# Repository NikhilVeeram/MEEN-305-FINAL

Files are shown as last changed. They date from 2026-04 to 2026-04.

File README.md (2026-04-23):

# MEEN 305 Final Project

This repo is organized around the active continuous beam-design workflow for the
MEEN 305 beam project.

## Current Setup

- Project-correct geometry is a `9.0 in` total beam with supports at `x = 0.5 in`
  and `x = 8.5 in`.
- The support span remains `8.0 in`.
- Load locations are still measured from support A in the project equations, but
  the solver and optimizer now track the full `0 to 9 in` beam coordinate.

## DIR

```text
MEEN-305-FINAL/
|-- README.md
|-- requirements.txt
|-- scripts/
|   |-- beam_solver.py
|   |-- optimize_beam.py
|   |-- beam_3d_models.py
|   `-- diagram_assets.py
|-- docs/
|   |-- notes/
|   |   |-- active_continuous_design_summary.md
|   |   |-- current_design_selection.md
|   |   |-- analysis_accountability_map.md
|   |   `-- beam_length_support_correction_audit.md
|   |-- references/
|   |   `-- project_reference_materials/
|   `-- reports/
|       `-- final_project_report.tex
|-- designs/
|   |-- active_runs/
|   |   |-- continuous_uniform_load_case_1/
|   |   |-- continuous_uniform_load_case_2/
|   |   |-- continuous_uniform_both_load_cases/
|   |   `-- continuous_uniform_both_load_cases_9in_corrected/
|   |-- model_exports/
|   `-- packages/
|-- Instructions_References/
`-- archive/
    `-- deprecated_assets/
```

## Folder Definitions

- [scripts](/c:/Users/nikhil/Documents/GitHub/MEEN-305-FINAL/scripts): source-of-truth analysis, optimization, export, and diagram code.
- [docs/notes](/c:/Users/nikhil/Documents/GitHub/MEEN-305-FINAL/docs/notes): working notes, design decisions, and correction audits.
- [docs/references/project_reference_materials](/c:/Users/nikhil/Documents/GitHub/MEEN-305-FINAL/docs/references/project_reference_materials): project handout, equations sheets, and supporting reference material.
- [docs/reports](/c:/Users/nikhil/Documents/GitHub/MEEN-305-FINAL/docs/reports): report deliverables, including the large final report source.
- [designs/active_runs](/c:/Users/nikhil/Documents/GitHub/MEEN-305-FINAL/designs/active_runs): generated optimization runs and their reports/plots.
- [designs/model_exports](/c:/Users/nikhil/Documents/GitHub/MEEN-305-FINAL/designs/model_exports): exported mesh files, previews, and manifest readmes.
- [designs/packages](/c:/Users/nikhil/Documents/GitHub/MEEN-305-FINAL/designs/packages): presentation-ready per-design bundles.
- [Instructions_References](/c:/Users/nikhil/Documents/GitHub/MEEN-305-FINAL/Instructions_References): prompt fragments and correction instructions collected during the project.
- [archive/deprecated_assets](/c:/Users/nikhil/Documents/GitHub/MEEN-305-FINAL/archive/deprecated_assets): superseded runs, legacy exports, and older exploratory work retained for reference.

## Active Reference Files

- [active_continuous_design_summary.md](/c:/Users/nikhil/Documents/GitHub/MEEN-305-FINAL/docs/notes/active_continuous_design_summary.md)
- [current_design_selection.md](/c:/Users/nikhil/Documents/GitHub/MEEN-305-FINAL/docs/notes/current_design_selection.md)
- [beam_length_support_correction_audit.md](/c:/Users/nikhil/Documents/GitHub/MEEN-305-FINAL/docs/notes/beam_length_support_correction_audit.md)

## Common Commands

Run the solver:

```powershell
python scripts/beam_solver.py --total-length-in 9.0 --span-in 8.0 --support-a-x-in 0.5 --support-b-x-in 8.5
```

Run the corrected optimizer into a named folder:

```powershell
python scripts/optimize_beam.py --output-dir designs/active_runs/continuous_uniform_both_load_cases_9in_corrected --total-length-in 9.0 --span-in 8.0 --support-a-x-in 0.5 --support-b-x-in 8.5
```

Generate 3D exports:

```powershell
python scripts/beam_3d_models.py --write-dxf
```

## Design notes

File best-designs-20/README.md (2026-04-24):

# Best Designs 20

Top 20 feasible corrected 9 in beam candidates for report review.

Ranking formula: `weight_lbf`, with tie-breakers `max_deflection_in`, `abs(min_fos - 1.5)`, then `fos_3to7_std`.

Weight is the primary ranking target. Load Case 2 flatness over x=3..7 is retained as a reported metric and late tie-breaker.

## Folders

- `ranked-designs/`: one folder per top-20 candidate, prefixed with report rank.
- `3d-models/`: generated STL/OBJ/DXF/preview assets after running `scripts/beam_3d_models.py`.
- `report-packages/`: packaged copies of each ranked candidate after 3D generation.
- `ranking_summary.csv`: compact table for report selection.

Archived non-top-20 ranked candidates: `archive/ranked-design-candidates/ranked_candidates_after_top20.csv`.

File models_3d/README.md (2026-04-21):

# 3D Beam Models

This folder contains generated 3D models and preview renders for the beam designs found in the repo.

## Generated designs

### sample_geometry

- STL: [sample_geometry.stl](sample_geometry.stl)
- OBJ: [sample_geometry.obj](sample_geometry.obj)
- Preview: [sample_geometry_preview.png](sample_geometry_preview.png)

### optimization_outputs

- STL: [optimization_outputs.stl](optimization_outputs.stl)
- OBJ: [optimization_outputs.obj](optimization_outputs.obj)
- Preview: [optimization_outputs_preview.png](optimization_outputs_preview.png)

### optimization_targeted

- STL: [optimization_targeted.stl](optimization_targeted.stl)
- OBJ: [optimization_targeted.obj](optimization_targeted.obj)
- Preview: [optimization_targeted_preview.png](optimization_targeted_preview.png)

### optimization_opening_smoke

- STL: [optimization_opening_smoke.stl](optimization_opening_smoke.stl)
- OBJ: [optimization_opening_smoke.obj](optimization_opening_smoke.obj)
- Preview: [optimization_opening_smoke_preview.png](optimization_opening_smoke_preview.png)

### optimization_connected_2026

- STL: [optimization_connected_2026.stl](optimization_connected_2026.stl)
- OBJ: [optimization_connected_2026.obj](optimization_connected_2026.obj)
- Preview: [optimization_connected_2026_preview.png](optimization_connected_2026_preview.png)

### optimization_connected_7777

- STL: [optimization_connected_7777.stl](optimization_connected_7777.stl)
- OBJ: [optimization_connected_7777.obj](optimization_connected_7777.obj)
- Preview: [optimization_connected_7777_preview.png](optimization_connected_7777_preview.png)

### optimization_connected_4242

- STL: [optimization_connected_4242.stl](optimization_connected_4242.stl)
- OBJ: [optimization_connected_4242.obj](optimization_connected_4242.obj)
- Preview: [optimization_connected_4242_preview.png](optimization_connected_4242_preview.png)

### optimization_connected_v2_9191

- STL: [optimization_connected_v2_9191.stl](optimization_connected_v2_9191.stl)
- OBJ: [optimization_connected_v2_9191.obj](optimization_connected_v2_9191.obj)
- Preview: [optimization_connected_v2_9191_preview.png](optimization_connected_v2_9191_preview.png)

### optimization_connected_v2_3030

- STL: [optimization_connected_v2_3030.stl](optimization_connected_v2_3030.stl)
- OBJ: [optimization_connected_v2_3030.obj](optimization_connected_v2_3030.obj)
- Preview: [optimization_connected_v2_3030_preview.png](optimization_connected_v2_3030_preview.png)

### optimization_connected_v2_6060

- STL: [optimization_connected_v2_6060.stl](optimization_connected_v2_6060.stl)
- OBJ: [optimization_connected_v2_6060.obj](optimization_connected_v2_6060.obj)
- Preview: [optimization_connected_v2_6060_preview.png](optimization_connected_v2_6060_preview.png)

### optimization_connected_v3

- STL: [optimization_connected_v3.stl](optimization_connected_v3.stl)
- OBJ: [optimization_connected_v3.obj](optimization_connected_v3.obj)
- Preview: [optimization_connected_v3_preview.png](optimization_connected_v3_preview.png)

### optimization_final

- STL: [optimization_final.stl](optimization_final.stl)
- OBJ: [optimization_final.obj](optimization_final.obj)
- Preview: [optimization_final_preview.png](optimization_final_preview.png)

## How to view them

- Double-click an `.obj` or `.stl` file in a local 3D viewer if you have one installed.
- Use the `.png` previews for quick comparison inside the repo.
- Re-run `python beam_3d_models.py` after optimization updates to refresh the models.

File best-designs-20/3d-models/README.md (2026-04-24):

# 3D Beam Models

This folder contains generated 3D models and preview renders for the beam designs found in the repo.

## Generated designs

### 01_overall_rank__continuous_uniform_both_load_cases_9in_corrected__eval_0370__w_0.02815__fos_1.642

- STL: [01_overall_rank__continuous_uniform_both_load_cases_9in_corrected__eval_0370__w_0.02815__fos_1.642.stl](01_overall_rank__continuous_uniform_both_load_cases_9in_corrected__eval_0370__w_0.02815__fos_1.642.stl)
- OBJ: [01_overall_rank__continuous_uniform_both_load_cases_9in_corrected__eval_0370__w_0.02815__fos_1.642.obj](01_overall_rank__continuous_uniform_both_load_cases_9in_corrected__eval_0370__w_0.02815__fos_1.642.obj)
- Preview: [01_overall_rank__continuous_uniform_both_load_cases_9in_corrected__eval_0370__w_0.02815__fos_1.642_preview.png](01_overall_rank__continuous_uniform_both_load_cases_9in_corrected__eval_0370__w_0.02815__fos_1.642_preview.png)
- DXF sketch: [01_overall_rank__continuous_uniform_both_load_cases_9in_corrected__eval_0370__w_0.02815__fos_1.642.dxf](01_overall_rank__continuous_uniform_both_load_cases_9in_corrected__eval_0370__w_0.02815__fos_1.642.dxf)

### 02_overall_rank__ultra_light_full_strength_seed2433__eval_1528__w_0.02894__fos_1.732

- STL: [02_overall_rank__ultra_light_full_strength_seed2433__eval_1528__w_0.02894__fos_1.732.stl](02_overall_rank__ultra_light_full_strength_seed2433__eval_1528__w_0.02894__fos_1.732.stl)
- OBJ: [02_overall_rank__ultra_light_full_strength_seed2433__eval_1528__w_0.02894__fos_1.732.obj](02_overall_rank__ultra_light_full_strength_seed2433__eval_1528__w_0.02894__fos_1.732.obj)
- Preview: [02_overall_rank__ultra_light_full_strength_seed2433__eval_1528__w_0.02894__fos_1.732_preview.png](02_overall_rank__ultra_light_full_strength_seed2433__eval_1528__w_0.02894__fos_1.732_preview.png)
- DXF sketch: [02_overall_rank__ultra_light_full_strength_seed2433__eval_1528__w_0.02894__fos_1.732.dxf](02_overall_rank__ultra_light_full_strength_seed2433__eval_1528__w_0.02894__fos_1.732.dxf)

### 03_overall_rank__ultra_light_run4_asymmetric_seed2427__eval_1102__w_0.02958__fos_2.116

- STL: [03_overall_rank__ultra_light_run4_asymmetric_seed2427__eval_1102__w_0.02958__fos_2.116.stl](03_overall_rank__ultra_light_run4_asymmetric_seed2427__eval_1102__w_0.02958__fos_2.116.stl)
- OBJ: [03_overall_rank__ultra_light_run4_asymmetric_seed2427__eval_1102__w_0.02958__fos_2.116.obj](03_overall_rank__ultra_light_run4_asymmetric_seed2427__eval_1102__w_0.02958__fos_2.116.obj)
- Preview: [03_overall_rank__ultra_light_run4_asymmetric_seed2427__eval_1102__w_0.02958__fos_2.116_preview.png](03_overall_rank__ultra_light_run4_asymmetric_seed2427__eval_1102__w_0.02958__fos_2.116_preview.png)
- DXF sketch: [03_overall_rank__ultra_light_run4_asymmetric_seed2427__eval_1102__w_0.02958__fos_2.116.dxf](03_overall_rank__ultra_light_run4_asymmetric_seed2427__eval_1102__w_0.02958__fos_2.116.dxf)

### 04_overall_rank__ultra_light_full_strength_seed2433__eval_2458__w_0.02971__fos_1.562

- STL: [04_overall_rank__ultra_light_full_strength_seed2433__eval_2458__w_0.02971__fos_1.562.stl](04_overall_rank__ultra_light_full_strength_seed2433__eval_2458__w_0.02971__fos_1.562.stl)
- OBJ: [04_overall_rank__ultra_light_full_strength_seed2433__eval_2458__w_0.02971__fos_1.562.obj](04_overall_rank__ultra_light_full_strength_seed2433__eval_2458__w_0.02971__fos_1.562.obj)
- Preview: [04_overall_rank__ultra_light_full_strength_seed2433__eval_2458__w_0.02971__fos_1.562_preview.png](04_overall_rank__ultra_light_full_strength_seed2433__eval_2458__w_0.02971__fos_1.562_preview.png)
- DXF sketch: [04_overall_rank__ultra_light_full_strength_seed2433__eval_2458__w_0.02971__fos_1.562.dxf](04_overall_rank__ultra_light_full_strength_seed2433__eval_2458__w_0.02971__fos_1.562.dxf)

### 05_overall_rank__ultra_light_full_infill_seed2432__eval_2924__w_0.03074__fos_1.789

- STL: [05_overall_rank__ultra_light_full_infill_seed2432__eval_2924__w_0.03074__fos_1.789.stl](05_overall_rank__ultra_light_full_infill_seed2432__eval_2924__w_0.03074__fos_1.789.stl)
- OBJ: [05_overall_rank__ultra_light_full_infill_seed2432__eval_2924__w_0.03074__fos_1.789.obj](05_overall_rank__ultra_light_full_infill_seed2432__eval_2924__w_0.03074__fos_1.789.obj)
- Preview: [05_overall_rank__ultra_light_full_infill_seed2432__eval_2924__w_0.03074__fos_1.789_preview.png](05_overall_rank__ultra_light_full_infill_seed2432__eval_2924__w_0.03074__fos_1.789_preview.png)
- DXF sketch: [05_overall_rank__ultra_light_full_infill_seed2432__eval_2924__w_0.03074__fos_1.789.dxf](05_overall_rank__ultra_light_full_infill_seed2432__eval_2924__w_0.03074__fos_1.789.dxf)

### 06_overall_rank__ultra_light_full_strength_seed2433__eval_1532__w_0.03127__fos_1.712

- STL: [06_overall_rank__ultra_light_full_strength_seed2433__eval_1532__w_0.03127__fos_1.712.stl](06_overall_rank__ultra_light_full_strength_seed2433__eval_1532__w_0.03127__fos_1.712.stl)
- OBJ: [06_overall_rank__ultra_light_full_strength_seed2433__eval_1532__w_0.03127__fos_1.712.obj](06_overall_rank__ultra_light_full_strength_seed2433__eval_1532__w_0.03127__fos_1.712.obj)
- Preview: [06_overall_rank__ultra_light_full_strength_seed2433__eval_1532__w_0.03127__fos_1.712_preview.png](06_overall_rank__ultra_light_full_strength_seed2433__eval_1532__w_0.03127__fos_1.712_preview.png)
- DXF sketch: [06_overall_rank__ultra_light_full_strength_seed2433__eval_1532__w_0.03127__fos_1.712.dxf](06_overall_rank__ultra_light_full_strength_seed2433__eval_1532__w_0.03127__fos_1.712.dxf)

### 07_overall_rank__ultra_light_full_infill_seed2432__eval_2497__w_0.03158__fos_1.751

- STL: [07_overall_rank__ultra_light_full_infill_seed2432__eval_2497__w_0.03158__fos_1.751.stl](07_overall_rank__ultra_light_full_infill_seed2432__eval_2497__w_0.03158__fos_1.751.stl)
- OBJ: [07_overall_rank__ultra_light_full_infill_seed2432__eval_2497__w_0.03158__fos_1.751.obj](07_overall_rank__ultra_light_full_infill_seed2432__eval_2497__w_0.03158__fos_1.751.obj)
- Preview: [07_overall_rank__ultra_light_full_infill_seed2432__eval_2497__w_0.03158__fos_1.751_preview.png](07_overall_rank__ultra_light_full_infill_seed2432__eval_2497__w_0.03158__fos_1.751_preview.png)
- DXF sketch: [07_overall_rank__ultra_light_full_infill_seed2432__eval_2497__w_0.03158__fos_1.751.dxf](07_overall_rank__ultra_light_full_infill_seed2432__eval_2497__w_0.03158__fos_1.751.dxf)

### 08_overall_rank__ultra_light_full_infill_seed2432__eval_2852__w_0.03254__fos_1.713

- STL: [08_overall_rank__ultra_light_full_infill_seed2432__eval_2852__w_0.03254__fos_1.713.stl](08_overall_rank__ultra_light_full_infill_seed2432__eval_2852__w_0.03254__fos_1.713.stl)
- OBJ: [08_overall_rank__ultra_light_full_infill_seed2432__eval_2852__w_0.03254__fos_1.713.obj](08_overall_rank__ultra_light_full_infill_seed2432__eval_2852__w_0.03254__fos_1.713.obj)
- Preview: [08_overall_rank__ultra_light_full_infill_seed2432__eval_2852__w_0.03254__fos_1.713_preview.png](08_overall_rank__ultra_light_full_infill_seed2432__eval_2852__w_0.03254__fos_1.713_preview.png)
- DXF sketch: [08_overall_rank__ultra_light_full_infill_seed2432__eval_2852__w_0.03254__fos_1.713.dxf](08_overall_rank__ultra_light_full_infill_seed2432__eval_2852__w_0.03254__fos_1.713.dxf)

### 09_overall_rank__ultra_light_full_infill_seed2432__eval_2251__w_0.03329__fos_1.595

- STL: [09_overall_rank__ultra_light_full_infill_seed2432__eval_2251__w_0.03329__fos_1.595.stl](09_overall_rank__ultra_light_full_infill_seed2432__eval_2251__w_0.03329__fos_1.595.stl)
- OBJ: [09_overall_rank__ultra_light_full_infill_seed2432__eval_2251__w_0.03329__fos_1.595.obj](09_overall_rank__ultra_light_full_infill_seed2432__eval_2251__w_0.03329__fos_1.595.obj)
- Preview: [09_overall_rank__ultra_light_full_infill_seed2432__eval_2251__w_0.03329__fos_1.595_preview.png](09_overall_rank__ultra_light_full_infill_seed2432__eval_2251__w_0.03329__fos_1.595_preview.png)
- DXF sketch: [09_overall_rank__ultra_light_full_infill_seed2432__eval_2251__w_0.03329__fos_1.595.dxf](09_overall_rank__ultra_light_full_infill_seed2432__eval_2251__w_0.03329__fos_1.595.dxf)

### 10_overall_rank__ultra_light_full_infill_seed2432__eval_2514__w_0.03483__fos_1.572

- STL: [10_overall_rank__ultra_light_full_infill_seed2432__eval_2514__w_0.03483__fos_1.572.stl](10_overall_rank__ultra_light_full_infill_seed2432__eval_2514__w_0.03483__fos_1.572.stl)
- OBJ: [10_overall_rank__ultra_light_full_infill_seed2432__eval_2514__w_0.03483__fos_1.572.obj](10_overall_rank__ultra_light_full_infill_seed2432__eval_2514__w_0.03483__fos_1.572.obj)
- Preview: [10_overall_rank__ultra_light_full_infill_seed2432__eval_2514__w_0.03483__fos_1.572_preview.png](10_overall_rank__ultra_light_full_infill_seed2432__eval_2514__w_0.03483__fos_1.572_preview.png)
- DXF sketch: [10_overall_rank__ultra_light_full_infill_seed2432__eval_2514__w_0.03483__fos_1.572.dxf](10_overall_rank__ultra_light_full_infill_seed2432__eval_2514__w_0.03483__fos_1.572.dxf)

### 11_overall_rank__continuous_uniform_both_load_cases_9in_corrected__eval_0572__w_0.03504__fos_1.877

- STL: [11_overall_rank__continuous_uniform_both_load_cases_9in_corrected__eval_0572__w_0.03504__fos_1.877.stl](11_overall_rank__continuous_uniform_both_load_cases_9in_corrected__eval_0572__w_0.03504__fos_1.877.stl)
- OBJ: [11_overall_rank__continuous_uniform_both_load_cases_9in_corrected__eval_0572__w_0.03504__fos_1.877.obj](11_overall_rank__continuous_uniform_both_load_cases_9in_corrected__eval_0572__w_0.03504__fos_1.877.obj)
- Preview: [11_overall_rank__continuous_uniform_both_load_cases_9in_corrected__eval_0572__w_0.03504__fos_1.877_preview.png](11_overall_rank__continuous_uniform_both_load_cases_9in_corrected__eval_0572__w_0.03504__fos_1.877_preview.png)
- DXF sketch: [11_overall_rank__continuous_uniform_both_load_cases_9in_corrected__eval_0572__w_0.03504__fos_1.877.dxf](11_overall_rank__continuous_uniform_both_load_cases_9in_corrected__eval_0572__w_0.03504__fos_1.877.dxf)

### 12_overall_rank__continuous_uniform_both_load_cases_9in_corrected__eval_0680__w_0.03546__fos_2.902

- STL: [12_overall_rank__continuous_uniform_both_load_cases_9in_corrected__eval_0680__w_0.03546__fos_2.902.stl](12_overall_rank__continuous_uniform_both_load_cases_9in_corrected__eval_0680__w_0.03546__fos_2.902.stl)
- OBJ: [12_overall_rank__continuous_uniform_both_load_cases_9in_corrected__eval_0680__w_0.03546__fos_2.902.obj](12_overall_rank__continuous_uniform_both_load_cases_9in_corrected__eval_0680__w_0.03546__fos_2.902.obj)
- Preview: [12_overall_rank__continuous_uniform_both_load_cases_9in_corrected__eval_0680__w_0.03546__fos_2.902_preview.png](12_overall_rank__continuous_uniform_both_load_cases_9in_corrected__eval_0680__w_0.03546__fos_2.902_preview.png)
- DXF sketch: [12_overall_rank__continuous_uniform_both_load_cases_9in_corrected__eval_0680__w_0.03546__fos_2.902.dxf](12_overall_rank__continuous_uniform_both_load_cases_9in_corrected__eval_0680__w_0.03546__fos_2.902.dxf)

### 13_overall_rank__ultra_light_runa_seed2430__eval_2464__w_0.03652__fos_2.154

- STL: [13_overall_rank__ultra_light_runa_seed2430__eval_2464__w_0.03652__fos_2.154.stl](13_overall_rank__ultra_light_runa_seed2430__eval_2464__w_0.03652__fos_2.154.stl)
- OBJ: [13_overall_rank__ultra_light_runa_seed2430__eval_2464__w_0.03652__fos_2.154.obj](13_overall_rank__ultra_light_runa_seed2430__eval_2464__w_0.03652__fos_2.154.obj)
- Preview: [13_overall_rank__ultra_light_runa_seed2430__eval_2464__w_0.03652__fos_2.154_preview.png](13_overall_rank__ultra_light_runa_seed2430__eval_2464__w_0.03652__fos_2.154_preview.png)
- DXF sketch: [13_overall_rank__ultra_light_runa_seed2430__eval_2464__w_0.03652__fos_2.154.dxf](13_overall_rank__ultra_light_runa_seed2430__eval_2464__w_0.03652__fos_2.154.dxf)

### 14_overall_rank__continuous_uniform_both_load_cases_9in_corrected__eval_0402__w_0.03782__fos_2.022

- STL: [14_overall_rank__continuous_uniform_both_load_cases_9in_corrected__eval_0402__w_0.03782__fos_2.022.stl](14_overall_rank__continuous_uniform_both_load_cases_9in_corrected__eval_0402__w_0.03782__fos_2.022.stl)
- OBJ: [14_overall_rank__continuous_uniform_both_load_cases_9in_corrected__eval_0402__w_0.03782__fos_2.022.obj](14_overall_rank__continuous_uniform_both_load_cases_9in_corrected__eval_0402__w_0.03782__fos_2.022.obj)
- Preview: [14_overall_rank__continuous_uniform_both_load_cases_9in_corrected__eval_0402__w_0.03782__fos_2.022_preview.png](14_overall_rank__continuous_uniform_both_load_cases_9in_corrected__eval_0402__w_0.03782__fos_2.022_preview.png)
- DXF sketch: [14_overall_rank__continuous_uniform_both_load_cases_9in_corrected__eval_0402__w_0.03782__fos_2.022.dxf](14_overall_rank__continuous_uniform_both_load_cases_9in_corrected__eval_0402__w_0.03782__fos_2.022.dxf)

### 15_overall_rank__continuous_uniform_both_load_cases_9in_corrected__eval_0364__w_0.03983__fos_1.695

- STL: [15_overall_rank__continuous_uniform_both_load_cases_9in_corrected__eval_0364__w_0.03983__fos_1.695.stl](15_overall_rank__continuous_uniform_both_load_cases_9in_corrected__eval_0364__w_0.03983__fos_1.695.stl)
- OBJ: [15_overall_rank__continuous_uniform_both_load_cases_9in_corrected__eval_0364__w_0.03983__fos_1.695.obj](15_overall_rank__continuous_uniform_both_load_cases_9in_corrected__eval_0364__w_0.03983__fos_1.695.obj)
- Preview: [15_overall_rank__continuous_uniform_both_load_cases_9in_corrected__eval_0364__w_0.03983__fos_1.695_preview.png](15_overall_rank__continuous_uniform_both_load_cases_9in_corrected__eval_0364__w_0.03983__fos_1.695_preview.png)
- DXF sketch: [15_overall_rank__continuous_uniform_both_load_cases_9in_corrected__eval_0364__w_0.03983__fos_1.695.dxf](15_overall_rank__continuous_uniform_both_load_cases_9in_corrected__eval_0364__w_0.03983__fos_1.695.dxf)

### 16_overall_rank__continuous_uniform_both_load_cases_9in_corrected__eval_0219__w_0.03983__fos_1.761

- STL: [16_overall_rank__continuous_uniform_both_load_cases_9in_corrected__eval_0219__w_0.03983__fos_1.761.stl](16_overall_rank__continuous_uniform_both_load_cases_9in_corrected__eval_0219__w_0.03983__fos_1.761.stl)
- OBJ: [16_overall_rank__continuous_uniform_both_load_cases_9in_corrected__eval_0219__w_0.03983__fos_1.761.obj](16_overall_rank__continuous_uniform_both_load_cases_9in_corrected__eval_0219__w_0.03983__fos_1.761.obj)
- Preview: [16_overall_rank__continuous_uniform_both_load_cases_9in_corrected__eval_0219__w_0.03983__fos_1.761_preview.png](16_overall_rank__continuous_uniform_both_load_cases_9in_corrected__eval_0219__w_0.03983__fos_1.761_preview.png)
- DXF sketch: [16_overall_rank__continuous_uniform_both_load_cases_9in_corrected__eval_0219__w_0.03983__fos_1.761.dxf](16_overall_rank__continuous_uniform_both_load_cases_9in_corrected__eval_0219__w_0.03983__fos_1.761.dxf)

### 17_overall_rank__print_safe_contiguous_closed_tube_seed2502__eval_1066__w_0.04048__fos_1.674

- STL: [17_overall_rank__print_safe_contiguous_closed_tube_seed2502__eval_1066__w_0.04048__fos_1.674.stl](17_overall_rank__print_safe_contiguous_closed_tube_seed2502__eval_1066__w_0.04048__fos_1.674.stl)
- OBJ: [17_overall_rank__print_safe_contiguous_closed_tube_seed2502__eval_1066__w_0.04048__fos_1.674.obj](17_overall_rank__print_safe_contiguous_closed_tube_seed2502__eval_1066__w_0.04048__fos_1.674.obj)
- Preview: [17_overall_rank__print_safe_contiguous_closed_tube_seed2502__eval_1066__w_0.04048__fos_1.674_preview.png](17_overall_rank__print_safe_contiguous_closed_tube_seed2502__eval_1066__w_0.04048__fos_1.674_preview.png)
- DXF sketch: [17_overall_rank__print_safe_contiguous_closed_tube_seed2502__eval_1066__w_0.04048__fos_1.674.dxf](17_overall_rank__print_safe_contiguous_closed_tube_seed2502__eval_1066__w_0.04048__fos_1.674.dxf)

### 18_overall_rank__continuous_uniform_both_load_cases_9in_corrected__eval_0441__w_0.04079__fos_1.503

- STL: [18_overall_rank__continuous_uniform_both_load_cases_9in_corrected__eval_0441__w_0.04079__fos_1.503.stl](18_overall_rank__continuous_uniform_both_load_cases_9in_corrected__eval_0441__w_0.04079__fos_1.503.stl)
- OBJ: [18_overall_rank__continuous_uniform_both_load_cases_9in_corrected__eval_0441__w_0.04079__fos_1.503.obj](18_overall_rank__continuous_uniform_both_load_cases_9in_corrected__eval_0441__w_0.04079__fos_1.503.obj)
- Preview: [18_overall_rank__continuous_uniform_both_load_cases_9in_corrected__eval_0441__w_0.04079__fos_1.503_preview.png](18_overall_rank__continuous_uniform_both_load_cases_9in_corrected__eval_0441__w_0.04079__fos_1.503_preview.png)
- DXF sketch: [18_overall_rank__continuous_uniform_both_load_cases_9in_corrected__eval_0441__w_0.04079__fos_1.503.dxf](18_overall_rank__continuous_uniform_both_load_cases_9in_corrected__eval_0441__w_0.04079__fos_1.503.dxf)

### 19_overall_rank__ultra_light_full_infill_seed2432__eval_2513__w_0.04121__fos_1.565

- STL: [19_overall_rank__ultra_light_full_infill_seed2432__eval_2513__w_0.04121__fos_1.565.stl](19_overall_rank__ultra_light_full_infill_seed2432__eval_2513__w_0.04121__fos_1.565.stl)
- OBJ: [19_overall_rank__ultra_light_full_infill_seed2432__eval_2513__w_0.04121__fos_1.565.obj](19_overall_rank__ultra_light_full_infill_seed2432__eval_2513__w_0.04121__fos_1.565.obj)
- Preview: [19_overall_rank__ultra_light_full_infill_seed2432__eval_2513__w_0.04121__fos_1.565_preview.png](19_overall_rank__ultra_light_full_infill_seed2432__eval_2513__w_0.04121__fos_1.565_preview.png)
- DXF sketch: [19_overall_rank__ultra_light_full_infill_seed2432__eval_2513__w_0.04121__fos_1.565.dxf](19_overall_rank__ultra_light_full_infill_seed2432__eval_2513__w_0.04121__fos_1.565.dxf)

### 20_overall_rank__ultra_light_run3_lowheight_seed2426__eval_1611__w_0.04175__fos_2.633

- STL: [20_overall_rank__ultra_light_run3_lowheight_seed2426__eval_1611__w_0.04175__fos_2.633.stl](20_overall_rank__ultra_light_run3_lowheight_seed2426__eval_1611__w_0.04175__fos_2.633.stl)
- OBJ: [20_overall_rank__ultra_light_run3_lowheight_seed2426__eval_1611__w_0.04175__fos_2.633.obj](20_overall_rank__ultra_light_run3_lowheight_seed2426__eval_1611__w_0.04175__fos_2.633.obj)
- Preview: [20_overall_rank__ultra_light_run3_lowheight_seed2426__eval_1611__w_0.04175__fos_2.633_preview.png](20_overall_rank__ultra_light_run3_lowheight_seed2426__eval_1611__w_0.04175__fos_2.633_preview.png)
- DXF sketch: [20_overall_rank__ultra_light_run3_lowheight_seed2426__eval_1611__w_0.04175__fos_2.633.dxf](20_overall_rank__ultra_light_run3_lowheight_seed2426__eval_1611__w_0.04175__fos_2.633.dxf)

## How to view them

- Double-click an `.obj` or `.stl` file in a local 3D viewer if you have one installed.
- Use the `.png` previews for quick comparison inside the repo.
- Re-run `python scripts/beam_3d_models.py` after optimization updates to refresh the models.

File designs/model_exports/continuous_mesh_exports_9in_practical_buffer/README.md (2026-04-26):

# 3D Beam Models

This folder contains generated 3D models and preview renders for the beam designs found in the repo.

## Generated designs

### continuous_uniform_both_load_cases_9in_practical_buffer

- STL: [continuous_uniform_both_load_cases_9in_practical_buffer.stl](continuous_uniform_both_load_cases_9in_practical_buffer.stl)
- OBJ: [continuous_uniform_both_load_cases_9in_practical_buffer.obj](continuous_uniform_both_load_cases_9in_practical_buffer.obj)
- Preview: [continuous_uniform_both_load_cases_9in_practical_buffer_preview.png](continuous_uniform_both_load_cases_9in_practical_buffer_preview.png)
- DXF sketch: [continuous_uniform_both_load_cases_9in_practical_buffer.dxf](continuous_uniform_both_load_cases_9in_practical_buffer.dxf)

## How to view them

- Double-click an `.obj` or `.stl` file in a local 3D viewer if you have one installed.
- Use the `.png` previews for quick comparison inside the repo.
- Re-run `python scripts/beam_3d_models.py` after optimization updates to refresh the models.

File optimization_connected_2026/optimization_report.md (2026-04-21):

# Beam Optimization Report

## Search Summary

- Search method: stratified global sampling with elite local refinement
- Total evaluated designs: 1540
- Feasible designs found: 429
- Minimum required factor of safety: 1.500
- Objective shaping: penalize excess FoS margin and underutilized stress envelope so the design approaches the 1.5 target more closely
- Maximum allowed deflection: not enforced in this run
- Random seed: 2026

## Best Design

- Weight: 0.05103 lbf
- Minimum factor of safety: 2.288
- Excess FoS above target: 0.788
- Governing minimum-FoS load case: Load Case 2 at x = 4.000 in
- Maximum deflection: 0.07570 in
- Durability score (0 is best): 0.000000
- Constraint status: feasible

### Geometry Variables

| Variable | Value |
| --- | ---: |
| $L$ [in] | 8.000 |
| $L_{total}$ [in] | 9.000 |
| $b_L$ [in] | 0.400 |
| $b_M$ [in] | 0.400 |
| $b_R$ [in] | 0.759 |
| $h_L$ [in] | 0.978 |
| $h_M$ [in] | 0.533 |
| $h_R$ [in] | 0.889 |
| $t$ [in] | 0.074 |
| $r_L$ [-] | 0.680 |
| $r_M$ [-] | 0.000 |
| $r_R$ [-] | 0.000 |
| $E_{eff}$ [psi] | 297500.0 |
| $\sigma_{allow,eff}$ [psi] | 2380.0 |

### Best-Design Load-Case Metrics

| Load Case | Orientation | Load [lbf] | Location [in] | Min FoS | FoS x [in] | Max Deflection [in] | Max von Mises [psi] |
| --- | --- | ---: | ---: | ---: | ---: | ---: | ---: |
| Load Case 1 | upright | 5.000 | 4.000 | 3.416 | 4.000 | 0.02977 | 696.8 |
| Load Case 2 | side | 8.000 | 5.000 | 2.288 | 4.000 | 0.07570 | 1040.3 |

## Beam Structure and Parameters

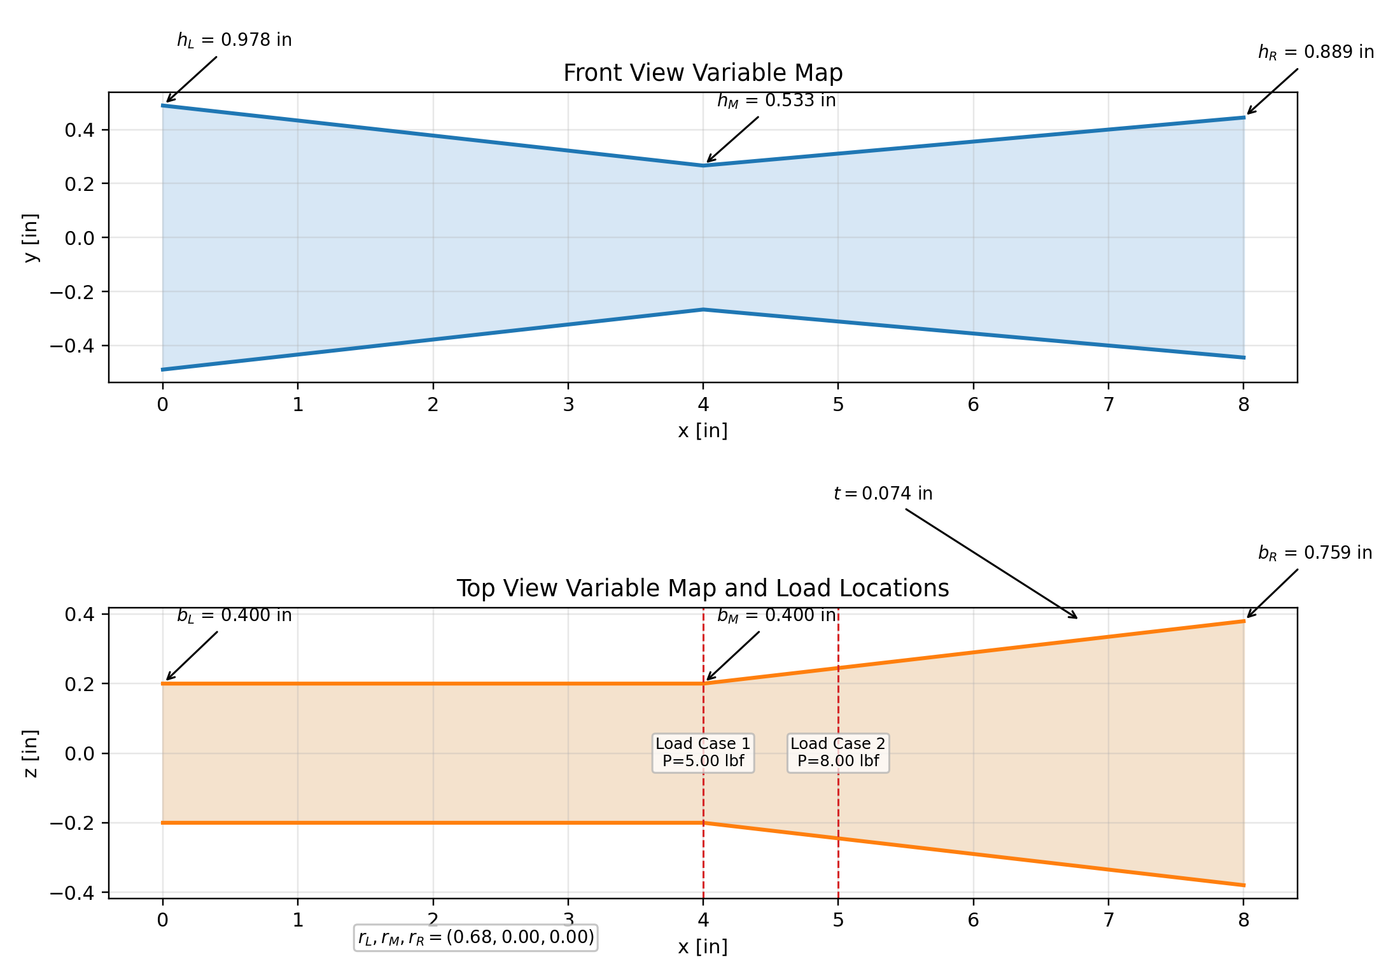
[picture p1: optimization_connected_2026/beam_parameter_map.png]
Beam parameter map


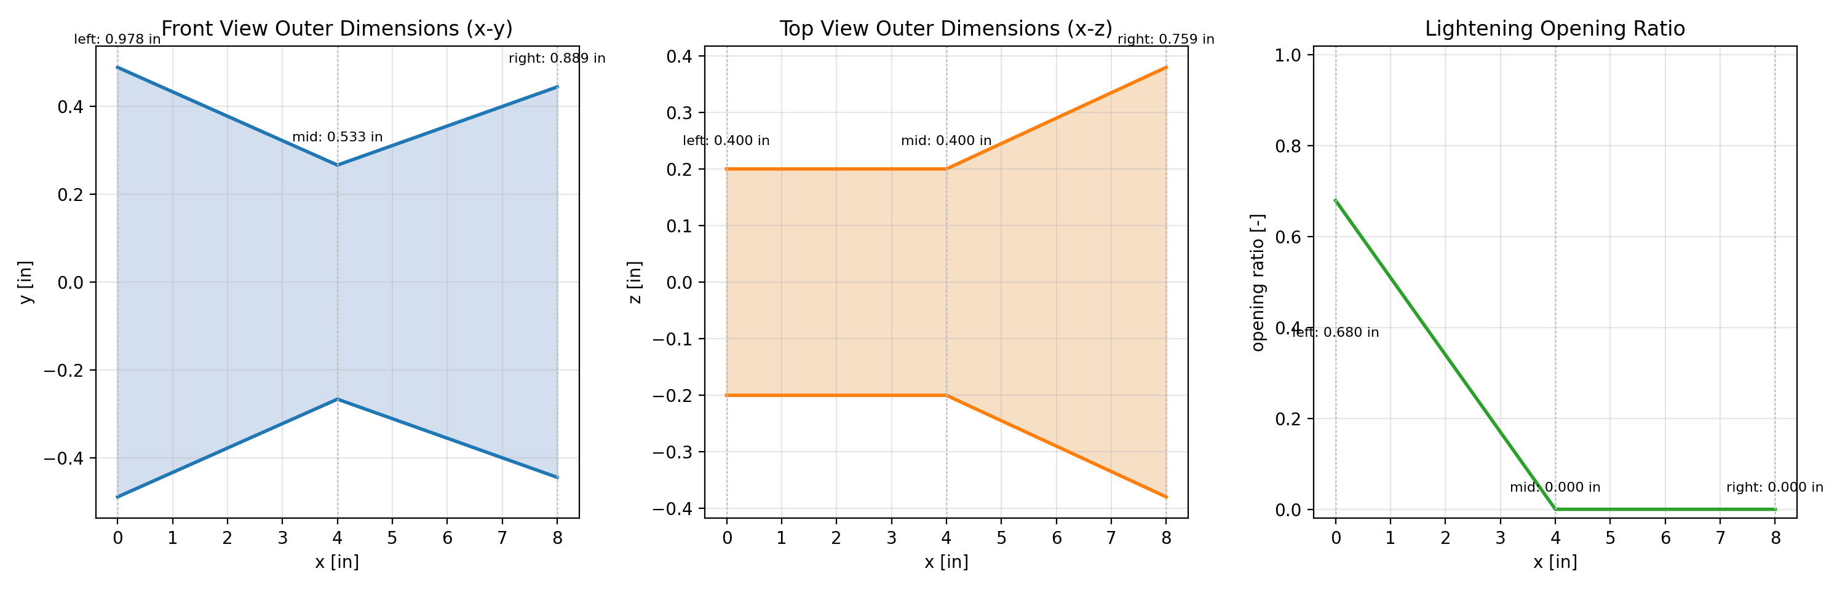
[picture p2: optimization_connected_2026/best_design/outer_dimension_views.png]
Outer dimension views


## General Equations

### Geometry

- $$b(x)=\begin{cases}0.4000 + (0.0000)x, & 0 \le x \le 4.0000\\0.4000 + (0.0897)(x-4.0000), & 4.0000 < x \le 8.0000\end{cases}$$
- $$h(x)=\begin{cases}0.9784 + (-0.1113)x, & 0 \le x \le 4.0000\\0.5332 + (0.0890)(x-4.0000), & 4.0000 < x \le 8.0000\end{cases}$$
- $$r(x)=\begin{cases}0.6797 + (-0.1699)x, & 0 \le x \le 4.0000\\0.0000 + (0.0000)(x-4.0000), & 4.0000 < x \le 8.0000\end{cases}$$
- Hollow tube area with lightening openings: $A(x)=2b(x)t + [1-r(x)]2t[h(x)-2t]$
- Upright bending second moment: $I(x)=\frac{b(x)h(x)^3-[b(x)-2t][h(x)-2t]^3}{12}-2\frac{t[r(x)(h(x)-2t)]^3}{12}$
- Side-rotated bending second moment: $I_{side}(x)=\frac{h(x)b(x)^3-[h(x)-2t][b(x)-2t]^3}{12}-2\frac{t[r(x)(b(x)-2t)]^3}{12}$
- Section modulus: $S(x)=I(x)/c(x)$ with $c(x)=\text{outer vertical dimension}/2$

### Statics and Stress

- Reactions for a point load $P$ at $x=a$: $R_A=P(L-a)/L$, $R_B=Pa/L$
- Shear and moment: $V(x)$ and $M(x)$ are computed piecewise from the reactions and applied load
- Bending stress: $\sigma_b(x)=|M(x)|/S(x)$
- Shear stress estimate: $\tau(x)=|V(x)|/A_{shear}(x)$ with $A_{shear}(x)=[1-r(x)]2t\,h_{clear}(x)$ for the active orientation
- von Mises stress: $\sigma_{vm}(x)=\sqrt{\sigma_b(x)^2+3\tau(x)^2}$
- Factor of safety: $FoS(x)=\sigma_{allow,eff}/\sigma_{vm}(x)$

### Deflection and Objective

- Euler-Bernoulli relation: $E_{eff}I(x)v''(x)=M(x)$
- Weight objective: $W=\rho\int_0^L A(x)\,dx$
- Search objective used here: minimize weight while enforcing factor-of-safety and optional deflection constraints

## Automatic Equation Substitution

### Effective Material Properties

- $E_{eff} = E \times k_{orientation} \times k_{infill} = 500000.0 \times 0.700 \times 0.850 = 297500.0\ \text{psi}$
- $\sigma_{allow,eff} = \sigma_{allow} \times k_{orientation} \times k_{infill} = 4000.0 \times 0.700 \times 0.850 = 2380.0\ \text{psi}$
- $W = \rho \int_0^L A(x)\,dx = 0.05103\ \text{lbf}$
- Global governing factor of safety is the minimum value over all beam stations and over both load cases.

### Load Case 1

- Active bending orientation: upright (upright section properties)
- $R_A = P(L-a)/L = 5.000(8.000-4.000)/8.000 = 2.500\ \text{lbf}$
- $R_B = Pa/L = 5.000(4.000)/8.000 = 2.500\ \text{lbf}$
- $FoS_{min} = \sigma_{allow,eff}/\sigma_{vm,max} = 2380.0/696.8 = 3.416$
- Governing location for this load case: $x = 4.000\ \text{in}$
- $\max |v(x)| = 0.02977\ \text{in}$
- $\max |\theta(x)| = 0.010006\ \text{rad}$

### Load Case 2

- Active bending orientation: side (side-rotated section properties)
- $R_A = P(L-a)/L = 8.000(8.000-5.000)/8.000 = 3.000\ \text{lbf}$
- $R_B = Pa/L = 8.000(5.000)/8.000 = 5.000\ \text{lbf}$
- $FoS_{min} = \sigma_{allow,eff}/\sigma_{vm,max} = 2380.0/1040.3 = 2.288$
- Governing location for this load case: $x = 4.000\ \text{in}$
- $\max |v(x)| = 0.07570\ \text{in}$
- $\max |\theta(x)| = 0.027437\ \text{rad}$

## Automatic Trail of Tried Designs

- Full design study table: `design_study.csv`
- Best design record: `best_design.json`
- Best-design plots folder: `best_design/`

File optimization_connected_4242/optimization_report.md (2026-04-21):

# Beam Optimization Report

## Search Summary

- Search method: stratified global sampling with elite local refinement
- Total evaluated designs: 1540
- Feasible designs found: 418
- Minimum required factor of safety: 1.500
- Objective shaping: penalize excess FoS margin and underutilized stress envelope so the design approaches the 1.5 target more closely
- Maximum allowed deflection: not enforced in this run
- Random seed: 4242

## Best Design

- Weight: 0.05003 lbf
- Minimum factor of safety: 2.594
- Excess FoS above target: 1.094
- Governing minimum-FoS load case: Load Case 2 at x = 4.000 in
- Maximum deflection: 0.05061 in
- Durability score (0 is best): 0.000000
- Constraint status: feasible

### Geometry Variables

| Variable | Value |
| --- | ---: |
| $L$ [in] | 8.000 |
| $L_{total}$ [in] | 9.000 |
| $b_L$ [in] | 0.909 |
| $b_M$ [in] | 0.477 |
| $b_R$ [in] | 0.807 |
| $h_L$ [in] | 0.659 |
| $h_M$ [in] | 0.450 |
| $h_R$ [in] | 0.703 |
| $t$ [in] | 0.073 |
| $r_L$ [-] | 0.595 |
| $r_M$ [-] | 0.195 |
| $r_R$ [-] | 0.309 |
| $E_{eff}$ [psi] | 297500.0 |
| $\sigma_{allow,eff}$ [psi] | 2380.0 |

### Best-Design Load-Case Metrics

| Load Case | Orientation | Load [lbf] | Location [in] | Min FoS | FoS x [in] | Max Deflection [in] | Max von Mises [psi] |
| --- | --- | ---: | ---: | ---: | ---: | ---: | ---: |
| Load Case 1 | upright | 5.000 | 4.000 | 2.981 | 4.000 | 0.04204 | 798.4 |
| Load Case 2 | side | 8.000 | 5.000 | 2.594 | 4.000 | 0.05061 | 917.5 |

## Beam Structure and Parameters

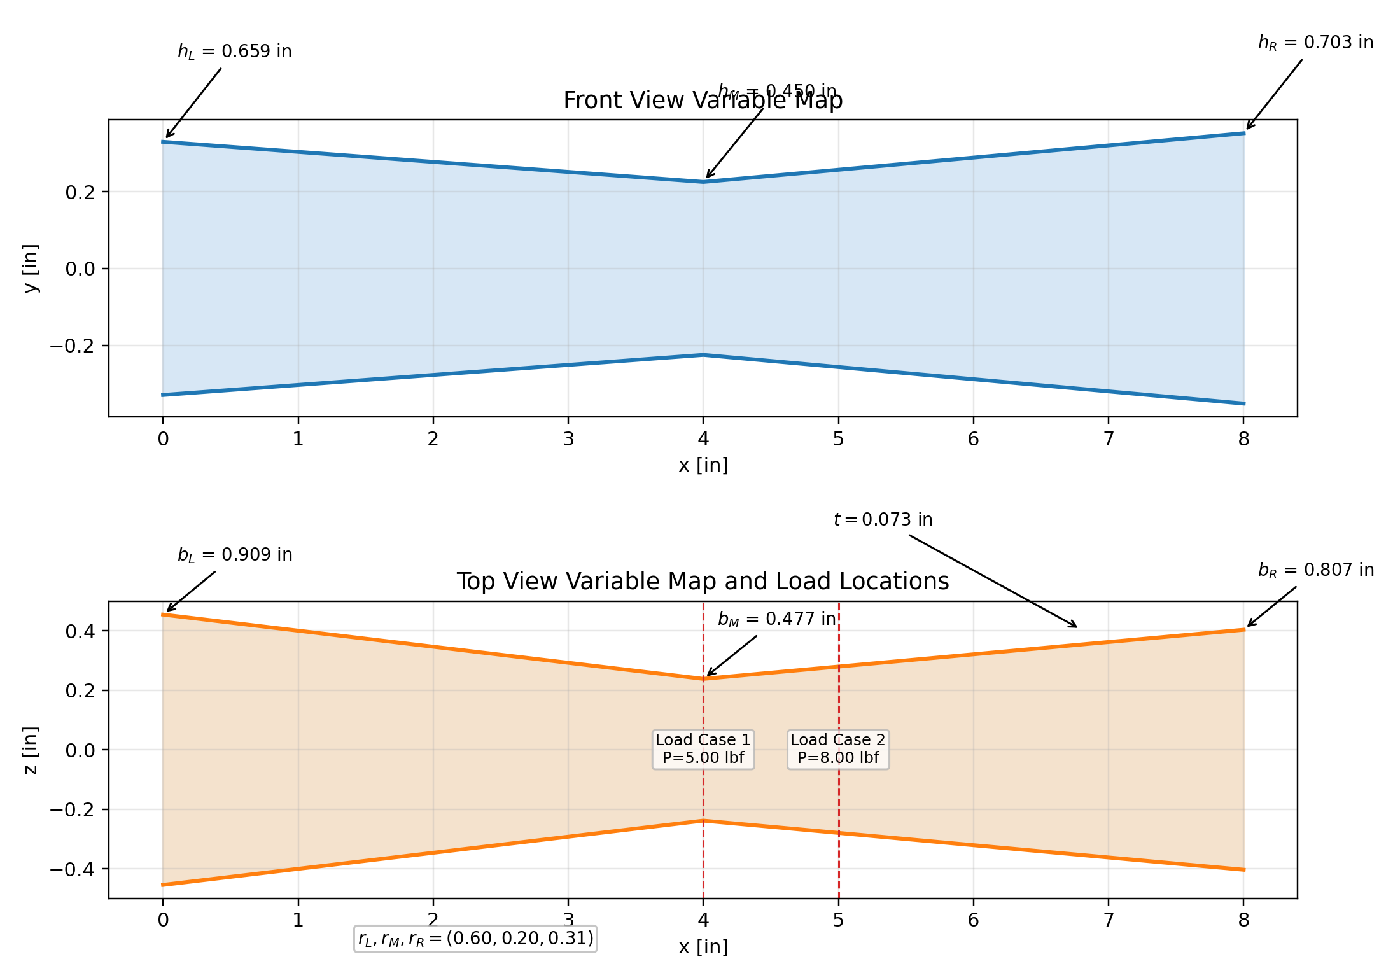
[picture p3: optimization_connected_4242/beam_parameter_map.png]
Beam parameter map


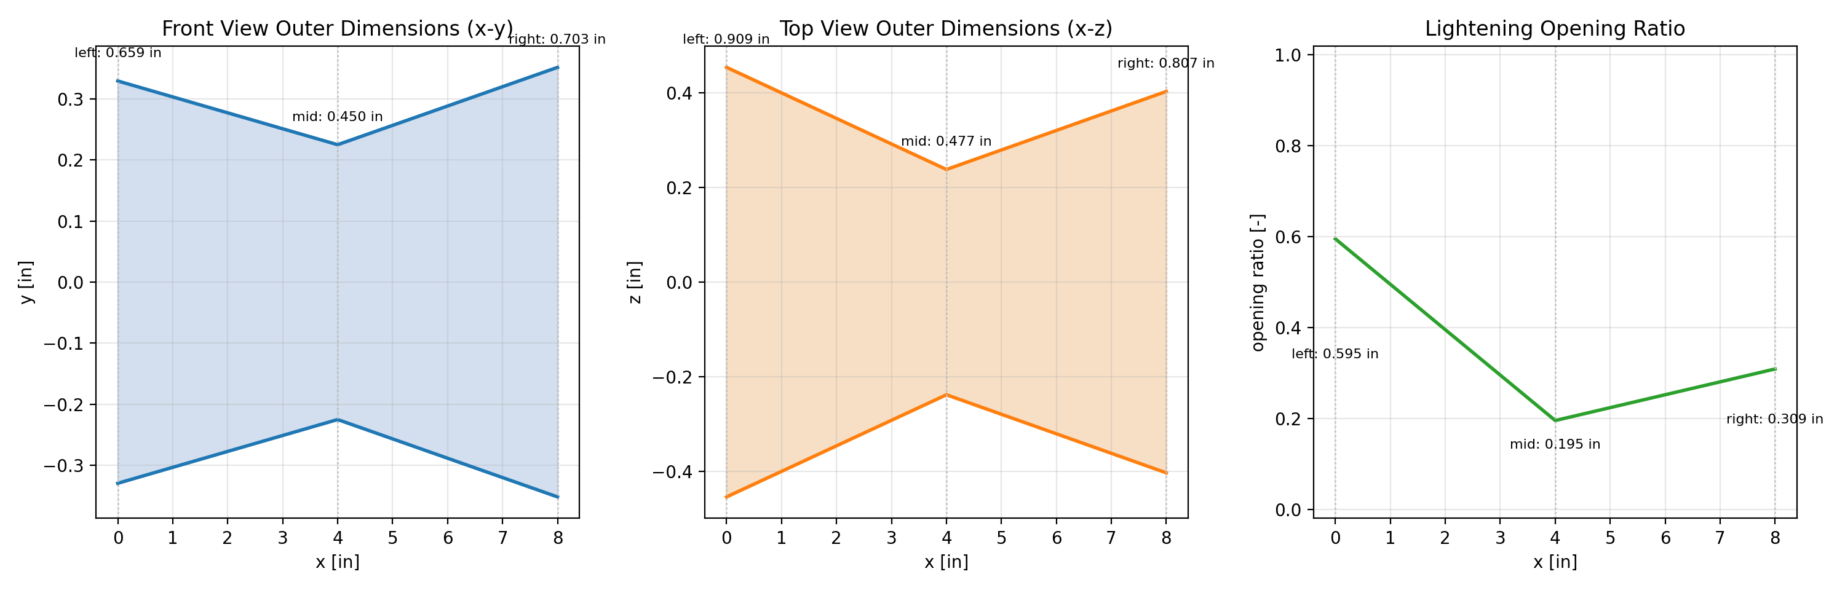
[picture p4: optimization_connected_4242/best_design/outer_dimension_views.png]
Outer dimension views


## General Equations

### Geometry

- $$b(x)=\begin{cases}0.9087 + (-0.1080)x, & 0 \le x \le 4.0000\\0.4766 + (0.0826)(x-4.0000), & 4.0000 < x \le 8.0000\end{cases}$$
- $$h(x)=\begin{cases}0.6586 + (-0.0522)x, & 0 \le x \le 4.0000\\0.4500 + (0.0633)(x-4.0000), & 4.0000 < x \le 8.0000\end{cases}$$
- $$r(x)=\begin{cases}0.5951 + (-0.0999)x, & 0 \le x \le 4.0000\\0.1954 + (0.0284)(x-4.0000), & 4.0000 < x \le 8.0000\end{cases}$$
- Hollow tube area with lightening openings: $A(x)=2b(x)t + [1-r(x)]2t[h(x)-2t]$
- Upright bending second moment: $I(x)=\frac{b(x)h(x)^3-[b(x)-2t][h(x)-2t]^3}{12}-2\frac{t[r(x)(h(x)-2t)]^3}{12}$
- Side-rotated bending second moment: $I_{side}(x)=\frac{h(x)b(x)^3-[h(x)-2t][b(x)-2t]^3}{12}-2\frac{t[r(x)(b(x)-2t)]^3}{12}$
- Section modulus: $S(x)=I(x)/c(x)$ with $c(x)=\text{outer vertical dimension}/2$

### Statics and Stress

- Reactions for a point load $P$ at $x=a$: $R_A=P(L-a)/L$, $R_B=Pa/L$
- Shear and moment: $V(x)$ and $M(x)$ are computed piecewise from the reactions and applied load
- Bending stress: $\sigma_b(x)=|M(x)|/S(x)$
- Shear stress estimate: $\tau(x)=|V(x)|/A_{shear}(x)$ with $A_{shear}(x)=[1-r(x)]2t\,h_{clear}(x)$ for the active orientation
- von Mises stress: $\sigma_{vm}(x)=\sqrt{\sigma_b(x)^2+3\tau(x)^2}$
- Factor of safety: $FoS(x)=\sigma_{allow,eff}/\sigma_{vm}(x)$

### Deflection and Objective

- Euler-Bernoulli relation: $E_{eff}I(x)v''(x)=M(x)$
- Weight objective: $W=\rho\int_0^L A(x)\,dx$
- Search objective used here: minimize weight while enforcing factor-of-safety and optional deflection constraints

## Automatic Equation Substitution

### Effective Material Properties

- $E_{eff} = E \times k_{orientation} \times k_{infill} = 500000.0 \times 0.700 \times 0.850 = 297500.0\ \text{psi}$
- $\sigma_{allow,eff} = \sigma_{allow} \times k_{orientation} \times k_{infill} = 4000.0 \times 0.700 \times 0.850 = 2380.0\ \text{psi}$
- $W = \rho \int_0^L A(x)\,dx = 0.05003\ \text{lbf}$
- Global governing factor of safety is the minimum value over all beam stations and over both load cases.

### Load Case 1

- Active bending orientation: upright (upright section properties)
- $R_A = P(L-a)/L = 5.000(8.000-4.000)/8.000 = 2.500\ \text{lbf}$
- $R_B = Pa/L = 5.000(4.000)/8.000 = 2.500\ \text{lbf}$
- $FoS_{min} = \sigma_{allow,eff}/\sigma_{vm,max} = 2380.0/798.4 = 2.981$
- Governing location for this load case: $x = 4.000\ \text{in}$
- $\max |v(x)| = 0.04204\ \text{in}$
- $\max |\theta(x)| = 0.014120\ \text{rad}$

### Load Case 2

- Active bending orientation: side (side-rotated section properties)
- $R_A = P(L-a)/L = 8.000(8.000-5.000)/8.000 = 3.000\ \text{lbf}$
- $R_B = Pa/L = 8.000(5.000)/8.000 = 5.000\ \text{lbf}$
- $FoS_{min} = \sigma_{allow,eff}/\sigma_{vm,max} = 2380.0/917.5 = 2.594$
- Governing location for this load case: $x = 4.000\ \text{in}$
- $\max |v(x)| = 0.05061\ \text{in}$
- $\max |\theta(x)| = 0.018242\ \text{rad}$

## Automatic Trail of Tried Designs

- Full design study table: `design_study.csv`
- Best design record: `best_design.json`
- Best-design plots folder: `best_design/`

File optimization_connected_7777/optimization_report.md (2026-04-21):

# Beam Optimization Report

## Search Summary

- Search method: stratified global sampling with elite local refinement
- Total evaluated designs: 1540
- Feasible designs found: 433
- Minimum required factor of safety: 1.500
- Objective shaping: penalize excess FoS margin and underutilized stress envelope so the design approaches the 1.5 target more closely
- Maximum allowed deflection: not enforced in this run
- Random seed: 7777

## Best Design

- Weight: 0.03968 lbf
- Minimum factor of safety: 2.051
- Excess FoS above target: 0.551
- Governing minimum-FoS load case: Load Case 2 at x = 5.000 in
- Maximum deflection: 0.09771 in
- Durability score (0 is best): 0.000000
- Constraint status: feasible

### Geometry Variables

| Variable | Value |
| --- | ---: |
| $L$ [in] | 8.000 |
| $L_{total}$ [in] | 9.000 |
| $b_L$ [in] | 0.400 |
| $b_M$ [in] | 0.400 |
| $b_R$ [in] | 0.400 |
| $h_L$ [in] | 0.616 |
| $h_M$ [in] | 0.687 |
| $h_R$ [in] | 0.450 |
| $t$ [in] | 0.072 |
| $r_L$ [-] | 0.302 |
| $r_M$ [-] | 0.205 |
| $r_R$ [-] | 0.130 |
| $E_{eff}$ [psi] | 297500.0 |
| $\sigma_{allow,eff}$ [psi] | 2380.0 |

### Best-Design Load-Case Metrics

| Load Case | Orientation | Load [lbf] | Location [in] | Min FoS | FoS x [in] | Max Deflection [in] | Max von Mises [psi] |
| --- | --- | ---: | ---: | ---: | ---: | ---: | ---: |
| Load Case 1 | upright | 5.000 | 4.000 | 5.049 | 4.000 | 0.02899 | 471.4 |
| Load Case 2 | side | 8.000 | 5.000 | 2.051 | 5.000 | 0.09771 | 1160.5 |

## Beam Structure and Parameters

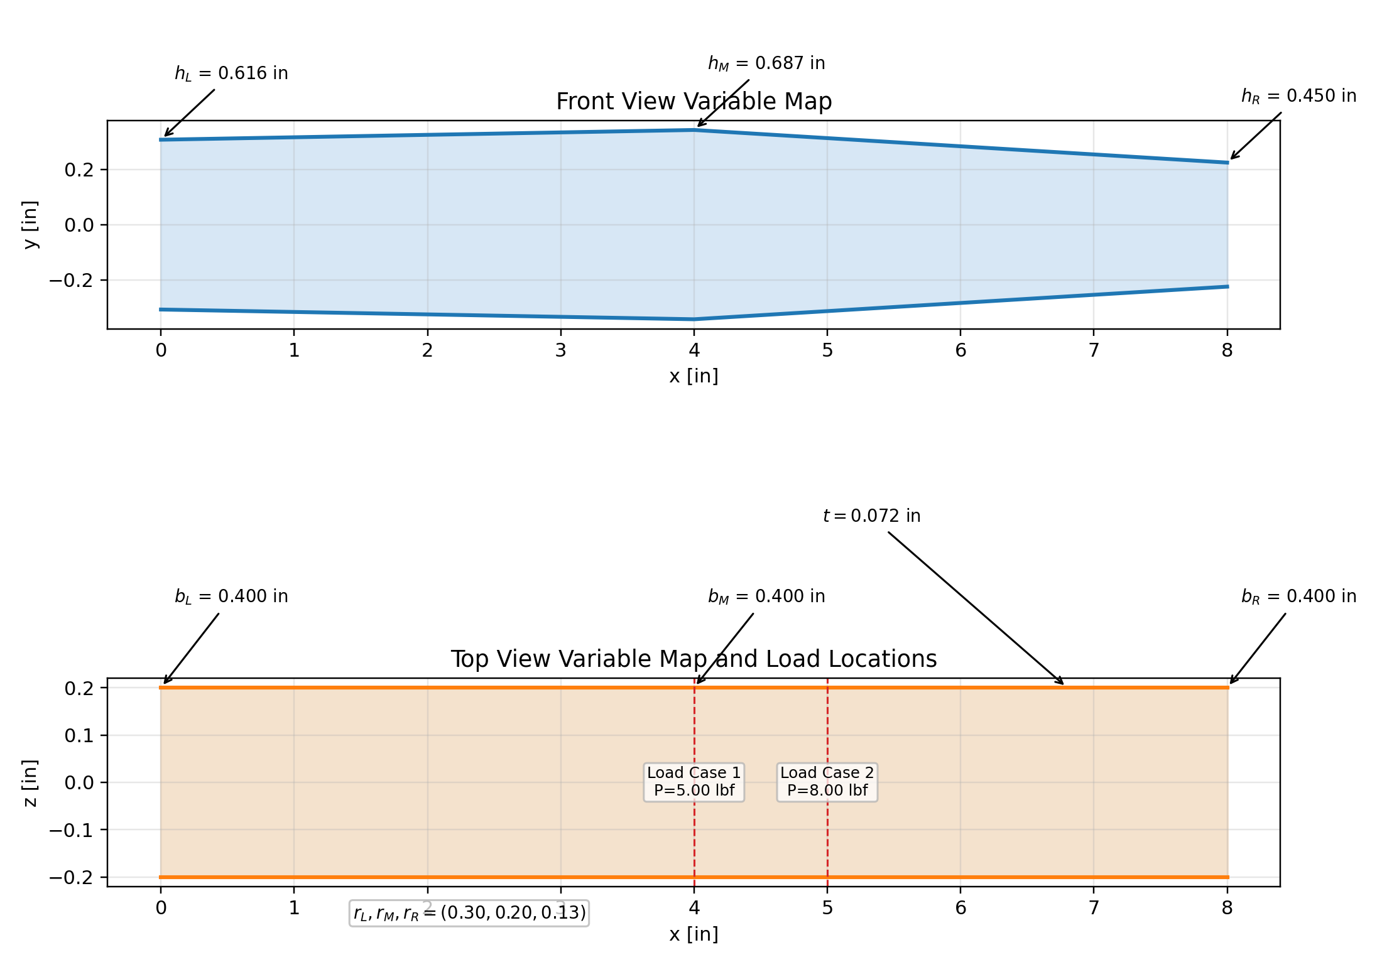
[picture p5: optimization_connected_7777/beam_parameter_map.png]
Beam parameter map


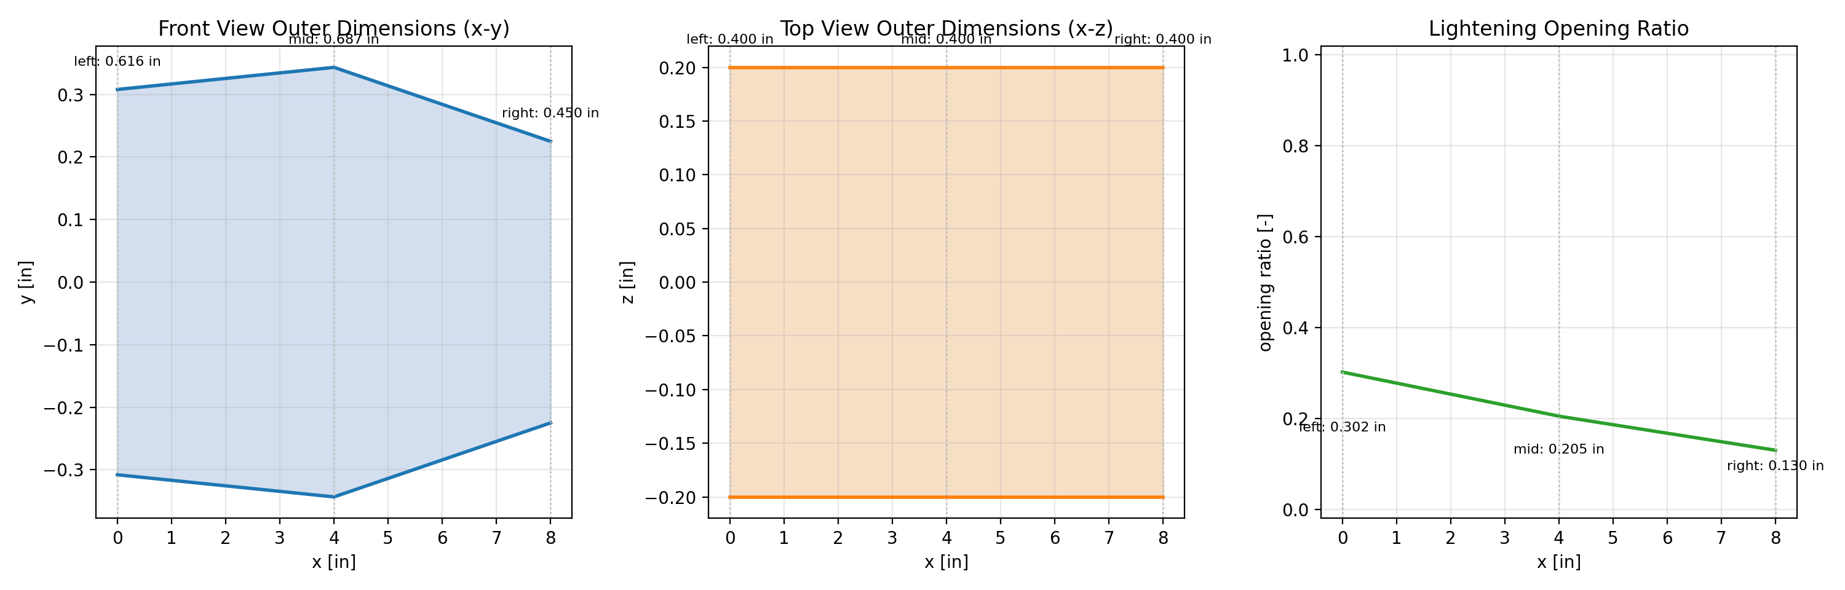
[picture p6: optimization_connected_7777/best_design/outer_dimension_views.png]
Outer dimension views


## General Equations

### Geometry

- $$b(x)=\begin{cases}0.4000 + (0.0000)x, & 0 \le x \le 4.0000\\0.4000 + (0.0000)(x-4.0000), & 4.0000 < x \le 8.0000\end{cases}$$
- $$h(x)=\begin{cases}0.6159 + (0.0177)x, & 0 \le x \le 4.0000\\0.6866 + (-0.0591)(x-4.0000), & 4.0000 < x \le 8.0000\end{cases}$$
- $$r(x)=\begin{cases}0.3020 + (-0.0243)x, & 0 \le x \le 4.0000\\0.2049 + (-0.0187)(x-4.0000), & 4.0000 < x \le 8.0000\end{cases}$$
- Hollow tube area with lightening openings: $A(x)=2b(x)t + [1-r(x)]2t[h(x)-2t]$
- Upright bending second moment: $I(x)=\frac{b(x)h(x)^3-[b(x)-2t][h(x)-2t]^3}{12}-2\frac{t[r(x)(h(x)-2t)]^3}{12}$
- Side-rotated bending second moment: $I_{side}(x)=\frac{h(x)b(x)^3-[h(x)-2t][b(x)-2t]^3}{12}-2\frac{t[r(x)(b(x)-2t)]^3}{12}$
- Section modulus: $S(x)=I(x)/c(x)$ with $c(x)=\text{outer vertical dimension}/2$

### Statics and Stress

- Reactions for a point load $P$ at $x=a$: $R_A=P(L-a)/L$, $R_B=Pa/L$
- Shear and moment: $V(x)$ and $M(x)$ are computed piecewise from the reactions and applied load
- Bending stress: $\sigma_b(x)=|M(x)|/S(x)$
- Shear stress estimate: $\tau(x)=|V(x)|/A_{shear}(x)$ with $A_{shear}(x)=[1-r(x)]2t\,h_{clear}(x)$ for the active orientation
- von Mises stress: $\sigma_{vm}(x)=\sqrt{\sigma_b(x)^2+3\tau(x)^2}$
- Factor of safety: $FoS(x)=\sigma_{allow,eff}/\sigma_{vm}(x)$

### Deflection and Objective

- Euler-Bernoulli relation: $E_{eff}I(x)v''(x)=M(x)$
- Weight objective: $W=\rho\int_0^L A(x)\,dx$
- Search objective used here: minimize weight while enforcing factor-of-safety and optional deflection constraints

## Automatic Equation Substitution

### Effective Material Properties

- $E_{eff} = E \times k_{orientation} \times k_{infill} = 500000.0 \times 0.700 \times 0.850 = 297500.0\ \text{psi}$
- $\sigma_{allow,eff} = \sigma_{allow} \times k_{orientation} \times k_{infill} = 4000.0 \times 0.700 \times 0.850 = 2380.0\ \text{psi}$
- $W = \rho \int_0^L A(x)\,dx = 0.03968\ \text{lbf}$
- Global governing factor of safety is the minimum value over all beam stations and over both load cases.

### Load Case 1

- Active bending orientation: upright (upright section properties)
- $R_A = P(L-a)/L = 5.000(8.000-4.000)/8.000 = 2.500\ \text{lbf}$
- $R_B = Pa/L = 5.000(4.000)/8.000 = 2.500\ \text{lbf}$
- $FoS_{min} = \sigma_{allow,eff}/\sigma_{vm,max} = 2380.0/471.4 = 5.049$
- Governing location for this load case: $x = 4.000\ \text{in}$
- $\max |v(x)| = 0.02899\ \text{in}$
- $\max |\theta(x)| = 0.012448\ \text{rad}$

### Load Case 2

- Active bending orientation: side (side-rotated section properties)
- $R_A = P(L-a)/L = 8.000(8.000-5.000)/8.000 = 3.000\ \text{lbf}$
- $R_B = Pa/L = 8.000(5.000)/8.000 = 5.000\ \text{lbf}$
- $FoS_{min} = \sigma_{allow,eff}/\sigma_{vm,max} = 2380.0/1160.5 = 2.051$
- Governing location for this load case: $x = 5.000\ \text{in}$
- $\max |v(x)| = 0.09771\ \text{in}$
- $\max |\theta(x)| = 0.042322\ \text{rad}$

## Automatic Trail of Tried Designs

- Full design study table: `design_study.csv`
- Best design record: `best_design.json`
- Best-design plots folder: `best_design/`

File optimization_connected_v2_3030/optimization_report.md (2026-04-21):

# Beam Optimization Report

## Search Summary

- Search method: stratified global sampling with elite local refinement
- Total evaluated designs: 1540
- Feasible designs found: 398
- Minimum required factor of safety: 1.500
- Objective shaping: penalize excess FoS margin and underutilized stress envelope so the design approaches the 1.5 target more closely
- Maximum allowed deflection: not enforced in this run
- Random seed: 3030

## Best Design

- Weight: 0.03643 lbf
- Minimum factor of safety: 1.591
- Excess FoS above target: 0.091
- Governing minimum-FoS load case: Load Case 2 at x = 5.000 in
- Maximum deflection: 0.14085 in
- Durability score (0 is best): 0.000000
- Constraint status: feasible

### Geometry Variables

| Variable | Value |
| --- | ---: |
| $L$ [in] | 8.000 |
| $L_{total}$ [in] | 9.000 |
| $b_L$ [in] | 0.350 |
| $b_M$ [in] | 0.351 |
| $b_R$ [in] | 0.350 |
| $h_L$ [in] | 0.694 |
| $h_M$ [in] | 0.584 |
| $h_R$ [in] | 0.551 |
| $t$ [in] | 0.081 |
| $r_L$ [-] | 0.442 |
| $r_M$ [-] | 0.304 |
| $r_R$ [-] | 0.458 |
| $E_{eff}$ [psi] | 297500.0 |
| $\sigma_{allow,eff}$ [psi] | 2380.0 |

### Best-Design Load-Case Metrics

| Load Case | Orientation | Load [lbf] | Location [in] | Min FoS | FoS x [in] | Max Deflection [in] | Max von Mises [psi] |
| --- | --- | ---: | ---: | ---: | ---: | ---: | ---: |
| Load Case 1 | upright | 5.000 | 4.000 | 3.722 | 4.000 | 0.03762 | 639.4 |
| Load Case 2 | side | 8.000 | 5.000 | 1.591 | 5.000 | 0.14085 | 1496.0 |

## Beam Structure and Parameters

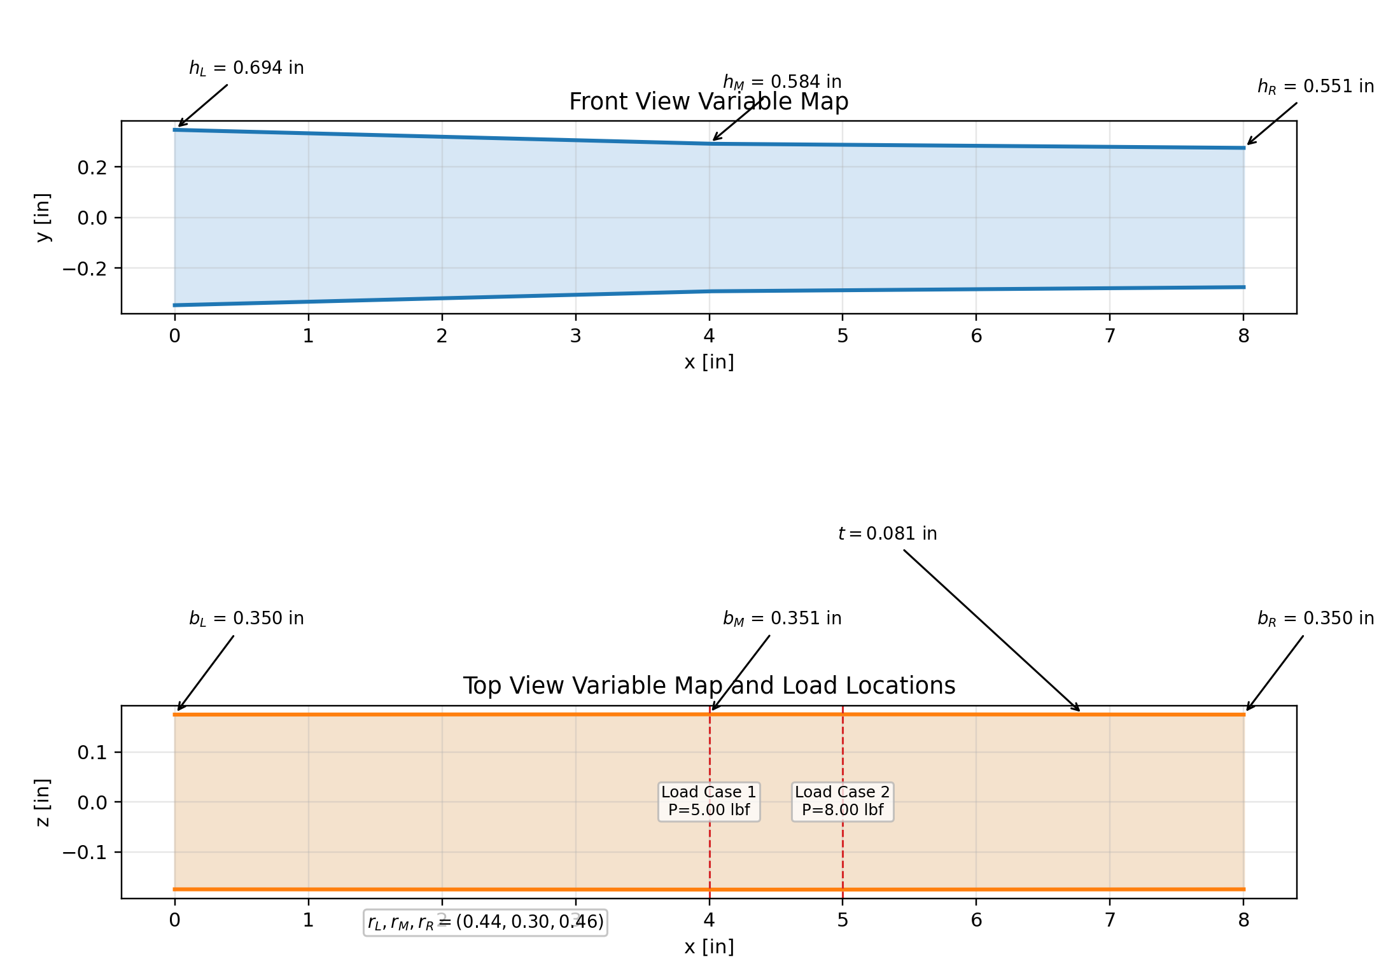
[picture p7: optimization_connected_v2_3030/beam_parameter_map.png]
Beam parameter map


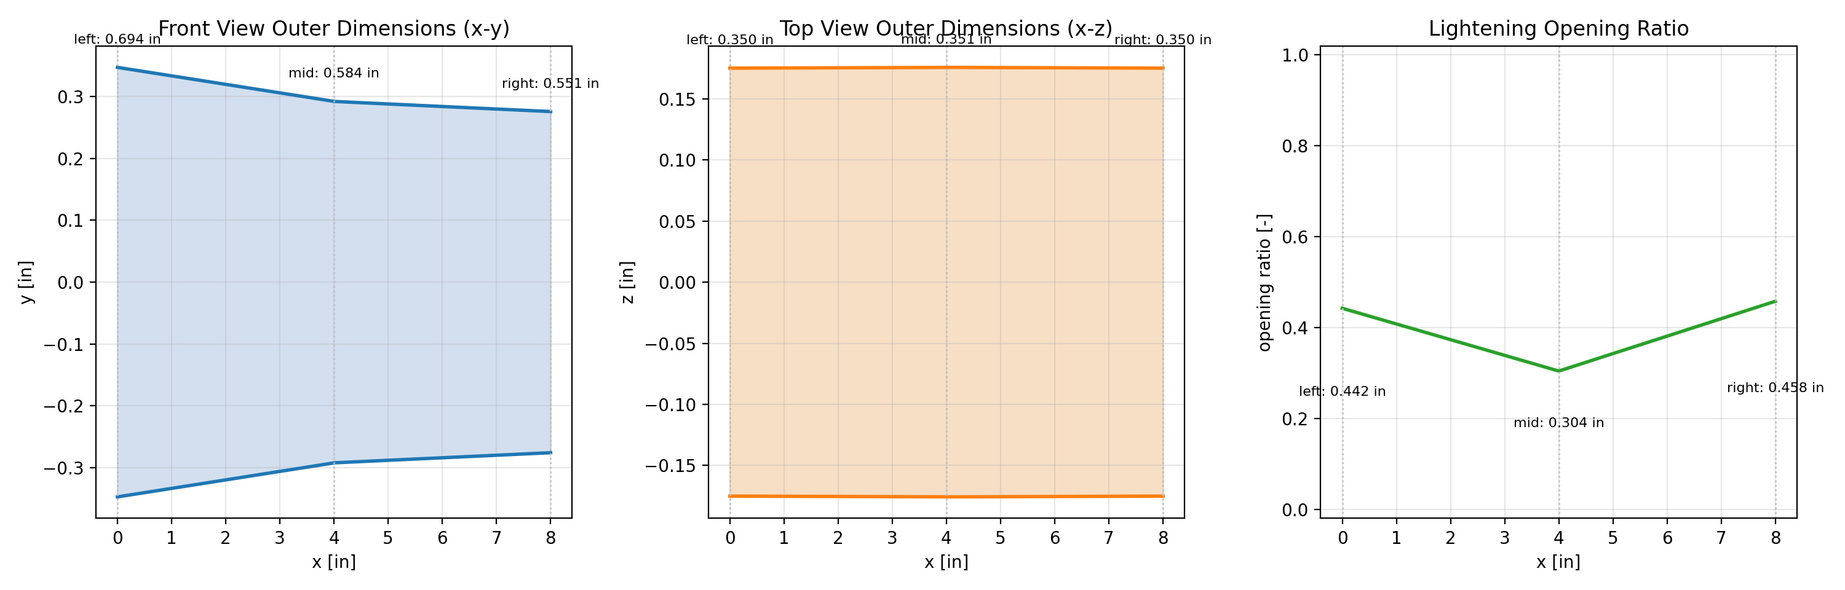
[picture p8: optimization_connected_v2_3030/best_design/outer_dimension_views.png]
Outer dimension views


## General Equations

### Geometry

- $$b(x)=\begin{cases}0.3500 + (0.0003)x, & 0 \le x \le 4.0000\\0.3513 + (-0.0003)(x-4.0000), & 4.0000 < x \le 8.0000\end{cases}$$
- $$h(x)=\begin{cases}0.6940 + (-0.0275)x, & 0 \le x \le 4.0000\\0.5839 + (-0.0082)(x-4.0000), & 4.0000 < x \le 8.0000\end{cases}$$
- $$r(x)=\begin{cases}0.4425 + (-0.0346)x, & 0 \le x \le 4.0000\\0.3043 + (0.0384)(x-4.0000), & 4.0000 < x \le 8.0000\end{cases}$$
- Hollow tube area with lightening openings: $A(x)=2b(x)t + [1-r(x)]2t[h(x)-2t]$
- Upright bending second moment: $I(x)=\frac{b(x)h(x)^3-[b(x)-2t][h(x)-2t]^3}{12}-2\frac{t[r(x)(h(x)-2t)]^3}{12}$
- Side-rotated bending second moment: $I_{side}(x)=\frac{h(x)b(x)^3-[h(x)-2t][b(x)-2t]^3}{12}-2\frac{t[r(x)(b(x)-2t)]^3}{12}$
- Section modulus: $S(x)=I(x)/c(x)$ with $c(x)=\text{outer vertical dimension}/2$

### Statics and Stress

- Reactions for a point load $P$ at $x=a$: $R_A=P(L-a)/L$, $R_B=Pa/L$
- Shear and moment: $V(x)$ and $M(x)$ are computed piecewise from the reactions and applied load
- Bending stress: $\sigma_b(x)=|M(x)|/S(x)$
- Shear stress estimate: $\tau(x)=|V(x)|/A_{shear}(x)$ with $A_{shear}(x)=[1-r(x)]2t\,h_{clear}(x)$ for the active orientation
- von Mises stress: $\sigma_{vm}(x)=\sqrt{\sigma_b(x)^2+3\tau(x)^2}$
- Factor of safety: $FoS(x)=\sigma_{allow,eff}/\sigma_{vm}(x)$

### Deflection and Objective

- Euler-Bernoulli relation: $E_{eff}I(x)v''(x)=M(x)$
- Weight objective: $W=\rho\int_0^L A(x)\,dx$
- Search objective used here: minimize weight while enforcing factor-of-safety and optional deflection constraints

## Automatic Equation Substitution

### Effective Material Properties

- $E_{eff} = E \times k_{orientation} \times k_{infill} = 500000.0 \times 0.700 \times 0.850 = 297500.0\ \text{psi}$
- $\sigma_{allow,eff} = \sigma_{allow} \times k_{orientation} \times k_{infill} = 4000.0 \times 0.700 \times 0.850 = 2380.0\ \text{psi}$
- $W = \rho \int_0^L A(x)\,dx = 0.03643\ \text{lbf}$
- Global governing factor of safety is the minimum value over all beam stations and over both load cases.

### Load Case 1

- Active bending orientation: upright (upright section properties)
- $R_A = P(L-a)/L = 5.000(8.000-4.000)/8.000 = 2.500\ \text{lbf}$
- $R_B = Pa/L = 5.000(4.000)/8.000 = 2.500\ \text{lbf}$
- $FoS_{min} = \sigma_{allow,eff}/\sigma_{vm,max} = 2380.0/639.4 = 3.722$
- Governing location for this load case: $x = 4.000\ \text{in}$
- $\max |v(x)| = 0.03762\ \text{in}$
- $\max |\theta(x)| = 0.014684\ \text{rad}$

### Load Case 2

- Active bending orientation: side (side-rotated section properties)
- $R_A = P(L-a)/L = 8.000(8.000-5.000)/8.000 = 3.000\ \text{lbf}$
- $R_B = Pa/L = 8.000(5.000)/8.000 = 5.000\ \text{lbf}$
- $FoS_{min} = \sigma_{allow,eff}/\sigma_{vm,max} = 2380.0/1496.0 = 1.591$
- Governing location for this load case: $x = 5.000\ \text{in}$
- $\max |v(x)| = 0.14085\ \text{in}$
- $\max |\theta(x)| = 0.059125\ \text{rad}$

## Automatic Trail of Tried Designs

- Full design study table: `design_study.csv`
- Best design record: `best_design.json`
- Best-design plots folder: `best_design/`

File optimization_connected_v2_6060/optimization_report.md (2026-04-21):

# Beam Optimization Report

## Search Summary

- Search method: stratified global sampling with elite local refinement
- Total evaluated designs: 1540
- Feasible designs found: 419
- Minimum required factor of safety: 1.500
- Objective shaping: penalize excess FoS margin and underutilized stress envelope so the design approaches the 1.5 target more closely
- Maximum allowed deflection: not enforced in this run
- Random seed: 6060

## Best Design

- Weight: 0.03018 lbf
- Minimum factor of safety: 1.634
- Excess FoS above target: 0.134
- Governing minimum-FoS load case: Load Case 2 at x = 5.000 in
- Maximum deflection: 0.12226 in
- Durability score (0 is best): 0.000000
- Constraint status: feasible

### Geometry Variables

| Variable | Value |
| --- | ---: |
| $L$ [in] | 8.000 |
| $L_{total}$ [in] | 9.000 |
| $b_L$ [in] | 0.446 |
| $b_M$ [in] | 0.350 |
| $b_R$ [in] | 0.572 |
| $h_L$ [in] | 1.051 |
| $h_M$ [in] | 0.559 |
| $h_R$ [in] | 0.530 |
| $t$ [in] | 0.060 |
| $r_L$ [-] | 0.621 |
| $r_M$ [-] | 0.525 |
| $r_R$ [-] | 0.297 |
| $E_{eff}$ [psi] | 297500.0 |
| $\sigma_{allow,eff}$ [psi] | 2380.0 |

### Best-Design Load-Case Metrics

| Load Case | Orientation | Load [lbf] | Location [in] | Min FoS | FoS x [in] | Max Deflection [in] | Max von Mises [psi] |
| --- | --- | ---: | ---: | ---: | ---: | ---: | ---: |
| Load Case 1 | upright | 5.000 | 4.000 | 2.798 | 4.000 | 0.04145 | 850.7 |
| Load Case 2 | side | 8.000 | 5.000 | 1.634 | 5.000 | 0.12226 | 1457.0 |

## Beam Structure and Parameters

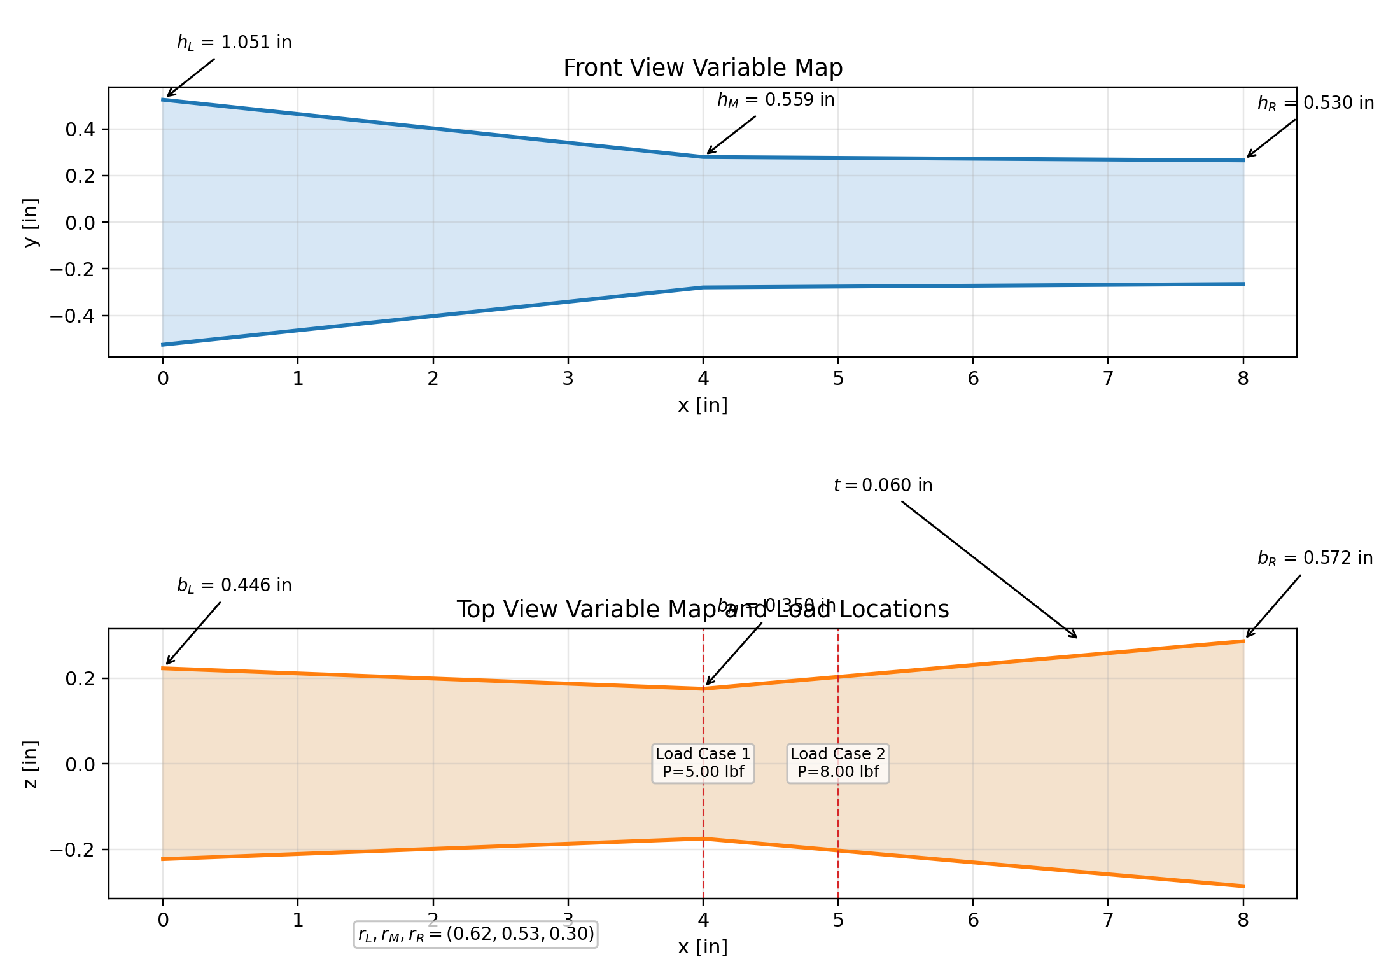
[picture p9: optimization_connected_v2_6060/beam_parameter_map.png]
Beam parameter map


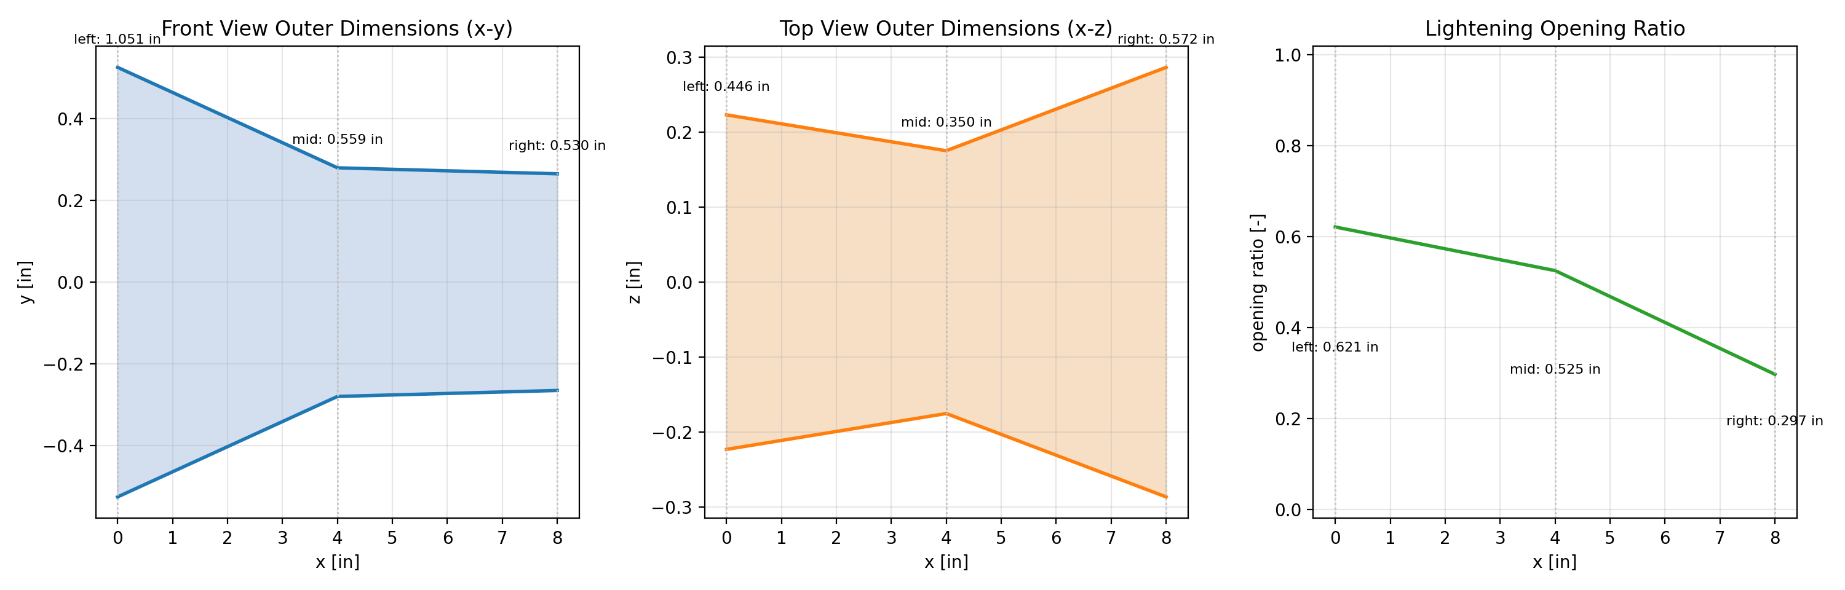
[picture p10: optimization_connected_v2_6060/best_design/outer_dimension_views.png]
Outer dimension views


## General Equations

### Geometry

- $$b(x)=\begin{cases}0.4458 + (-0.0239)x, & 0 \le x \le 4.0000\\0.3502 + (0.0555)(x-4.0000), & 4.0000 < x \le 8.0000\end{cases}$$
- $$h(x)=\begin{cases}1.0509 + (-0.1229)x, & 0 \le x \le 4.0000\\0.5594 + (-0.0073)(x-4.0000), & 4.0000 < x \le 8.0000\end{cases}$$
- $$r(x)=\begin{cases}0.6214 + (-0.0240)x, & 0 \le x \le 4.0000\\0.5254 + (-0.0571)(x-4.0000), & 4.0000 < x \le 8.0000\end{cases}$$
- Hollow tube area with lightening openings: $A(x)=2b(x)t + [1-r(x)]2t[h(x)-2t]$
- Upright bending second moment: $I(x)=\frac{b(x)h(x)^3-[b(x)-2t][h(x)-2t]^3}{12}-2\frac{t[r(x)(h(x)-2t)]^3}{12}$
- Side-rotated bending second moment: $I_{side}(x)=\frac{h(x)b(x)^3-[h(x)-2t][b(x)-2t]^3}{12}-2\frac{t[r(x)(b(x)-2t)]^3}{12}$
- Section modulus: $S(x)=I(x)/c(x)$ with $c(x)=\text{outer vertical dimension}/2$

### Statics and Stress

- Reactions for a point load $P$ at $x=a$: $R_A=P(L-a)/L$, $R_B=Pa/L$
- Shear and moment: $V(x)$ and $M(x)$ are computed piecewise from the reactions and applied load
- Bending stress: $\sigma_b(x)=|M(x)|/S(x)$
- Shear stress estimate: $\tau(x)=|V(x)|/A_{shear}(x)$ with $A_{shear}(x)=[1-r(x)]2t\,h_{clear}(x)$ for the active orientation
- von Mises stress: $\sigma_{vm}(x)=\sqrt{\sigma_b(x)^2+3\tau(x)^2}$
- Factor of safety: $FoS(x)=\sigma_{allow,eff}/\sigma_{vm}(x)$

### Deflection and Objective

- Euler-Bernoulli relation: $E_{eff}I(x)v''(x)=M(x)$
- Weight objective: $W=\rho\int_0^L A(x)\,dx$
- Search objective used here: minimize weight while enforcing factor-of-safety and optional deflection constraints

## Automatic Equation Substitution

### Effective Material Properties

- $E_{eff} = E \times k_{orientation} \times k_{infill} = 500000.0 \times 0.700 \times 0.850 = 297500.0\ \text{psi}$
- $\sigma_{allow,eff} = \sigma_{allow} \times k_{orientation} \times k_{infill} = 4000.0 \times 0.700 \times 0.850 = 2380.0\ \text{psi}$
- $W = \rho \int_0^L A(x)\,dx = 0.03018\ \text{lbf}$
- Global governing factor of safety is the minimum value over all beam stations and over both load cases.

### Load Case 1

- Active bending orientation: upright (upright section properties)
- $R_A = P(L-a)/L = 5.000(8.000-4.000)/8.000 = 2.500\ \text{lbf}$
- $R_B = Pa/L = 5.000(4.000)/8.000 = 2.500\ \text{lbf}$
- $FoS_{min} = \sigma_{allow,eff}/\sigma_{vm,max} = 2380.0/850.7 = 2.798$
- Governing location for this load case: $x = 4.000\ \text{in}$
- $\max |v(x)| = 0.04145\ \text{in}$
- $\max |\theta(x)| = 0.015984\ \text{rad}$

### Load Case 2

- Active bending orientation: side (side-rotated section properties)
- $R_A = P(L-a)/L = 8.000(8.000-5.000)/8.000 = 3.000\ \text{lbf}$
- $R_B = Pa/L = 8.000(5.000)/8.000 = 5.000\ \text{lbf}$
- $FoS_{min} = \sigma_{allow,eff}/\sigma_{vm,max} = 2380.0/1457.0 = 1.634$
- Governing location for this load case: $x = 5.000\ \text{in}$
- $\max |v(x)| = 0.12226\ \text{in}$
- $\max |\theta(x)| = 0.045448\ \text{rad}$

## Automatic Trail of Tried Designs

- Full design study table: `design_study.csv`
- Best design record: `best_design.json`
- Best-design plots folder: `best_design/`

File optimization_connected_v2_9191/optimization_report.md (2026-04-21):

# Beam Optimization Report

## Search Summary

- Search method: stratified global sampling with elite local refinement
- Total evaluated designs: 1540
- Feasible designs found: 337
- Minimum required factor of safety: 1.500
- Objective shaping: penalize excess FoS margin and underutilized stress envelope so the design approaches the 1.5 target more closely
- Maximum allowed deflection: not enforced in this run
- Random seed: 9191

## Best Design

- Weight: 0.04215 lbf
- Minimum factor of safety: 1.551
- Excess FoS above target: 0.051
- Governing minimum-FoS load case: Load Case 2 at x = 4.000 in
- Maximum deflection: 0.11218 in
- Durability score (0 is best): 0.000000
- Constraint status: feasible

### Geometry Variables

| Variable | Value |
| --- | ---: |
| $L$ [in] | 8.000 |
| $L_{total}$ [in] | 9.000 |
| $b_L$ [in] | 0.707 |
| $b_M$ [in] | 0.350 |
| $b_R$ [in] | 0.626 |
| $h_L$ [in] | 0.595 |
| $h_M$ [in] | 0.463 |
| $h_R$ [in] | 0.685 |
| $t$ [in] | 0.067 |
| $r_L$ [-] | 0.456 |
| $r_M$ [-] | 0.018 |
| $r_R$ [-] | 0.000 |
| $E_{eff}$ [psi] | 297500.0 |
| $\sigma_{allow,eff}$ [psi] | 2380.0 |

### Best-Design Load-Case Metrics

| Load Case | Orientation | Load [lbf] | Location [in] | Min FoS | FoS x [in] | Max Deflection [in] | Max von Mises [psi] |
| --- | --- | ---: | ---: | ---: | ---: | ---: | ---: |
| Load Case 1 | upright | 5.000 | 4.000 | 2.307 | 4.000 | 0.05582 | 1031.5 |
| Load Case 2 | side | 8.000 | 5.000 | 1.551 | 4.000 | 0.11218 | 1534.9 |

## Beam Structure and Parameters

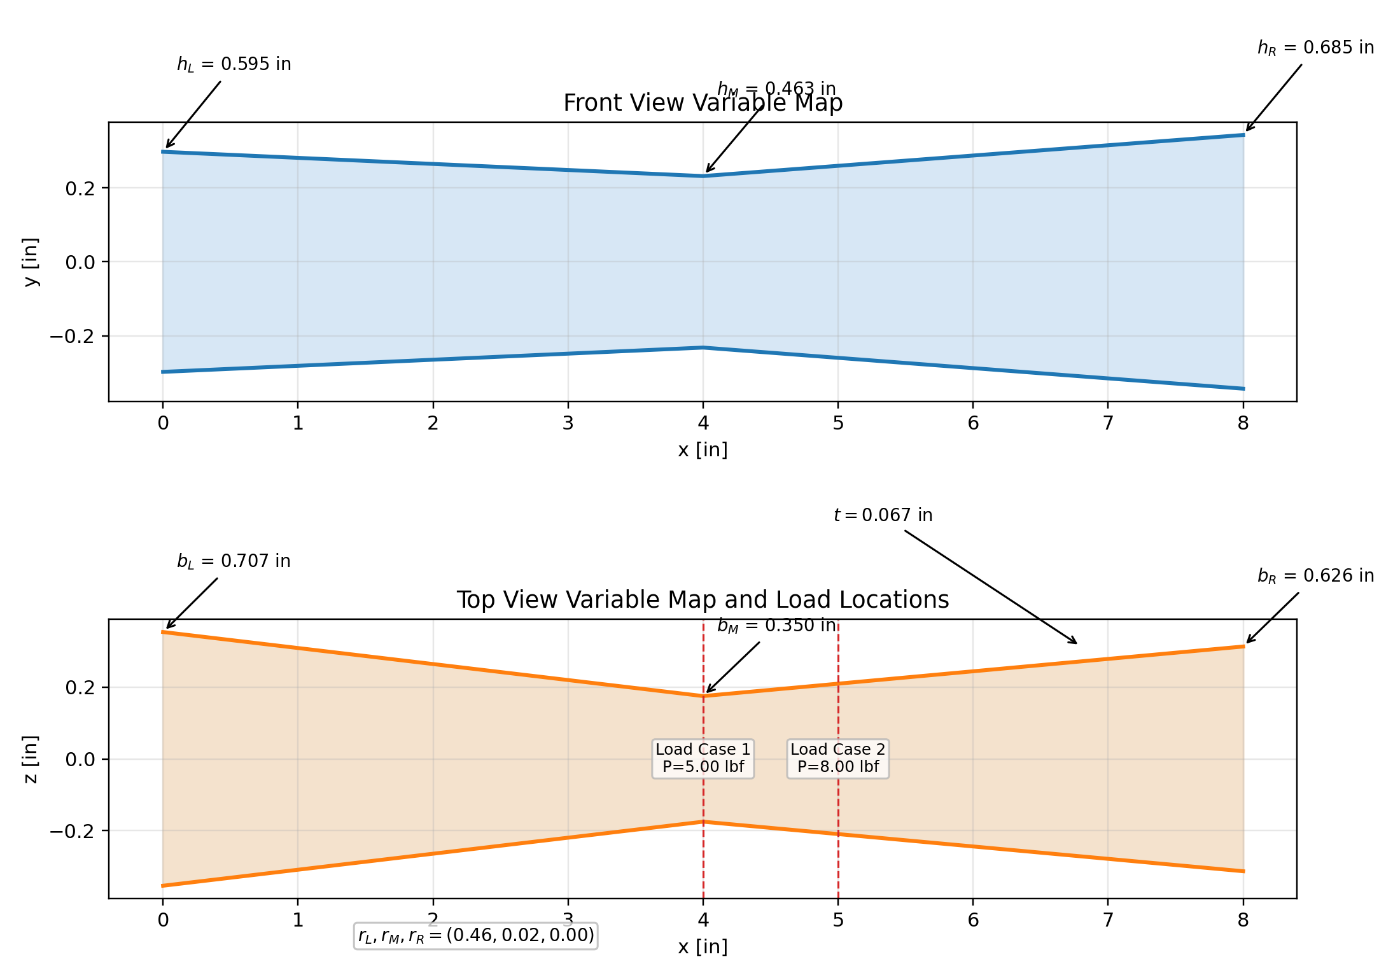
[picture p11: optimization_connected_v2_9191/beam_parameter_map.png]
Beam parameter map


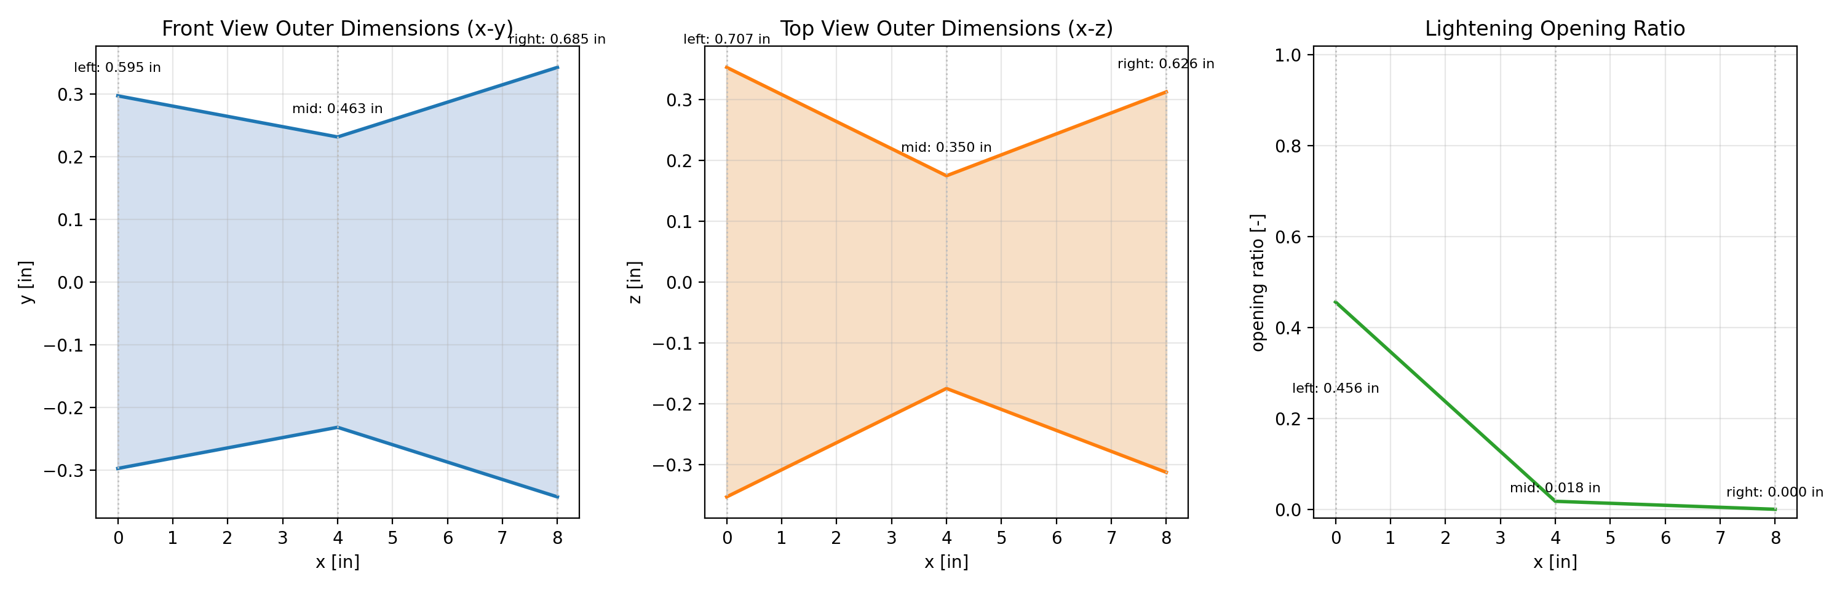
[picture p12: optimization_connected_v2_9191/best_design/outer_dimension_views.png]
Outer dimension views


## General Equations

### Geometry

- $$b(x)=\begin{cases}0.7068 + (-0.0892)x, & 0 \le x \le 4.0000\\0.3500 + (0.0690)(x-4.0000), & 4.0000 < x \le 8.0000\end{cases}$$
- $$h(x)=\begin{cases}0.5947 + (-0.0328)x, & 0 \le x \le 4.0000\\0.4633 + (0.0555)(x-4.0000), & 4.0000 < x \le 8.0000\end{cases}$$
- $$r(x)=\begin{cases}0.4562 + (-0.1097)x, & 0 \le x \le 4.0000\\0.0176 + (-0.0044)(x-4.0000), & 4.0000 < x \le 8.0000\end{cases}$$
- Hollow tube area with lightening openings: $A(x)=2b(x)t + [1-r(x)]2t[h(x)-2t]$
- Upright bending second moment: $I(x)=\frac{b(x)h(x)^3-[b(x)-2t][h(x)-2t]^3}{12}-2\frac{t[r(x)(h(x)-2t)]^3}{12}$
- Side-rotated bending second moment: $I_{side}(x)=\frac{h(x)b(x)^3-[h(x)-2t][b(x)-2t]^3}{12}-2\frac{t[r(x)(b(x)-2t)]^3}{12}$
- Section modulus: $S(x)=I(x)/c(x)$ with $c(x)=\text{outer vertical dimension}/2$

### Statics and Stress

- Reactions for a point load $P$ at $x=a$: $R_A=P(L-a)/L$, $R_B=Pa/L$
- Shear and moment: $V(x)$ and $M(x)$ are computed piecewise from the reactions and applied load
- Bending stress: $\sigma_b(x)=|M(x)|/S(x)$
- Shear stress estimate: $\tau(x)=|V(x)|/A_{shear}(x)$ with $A_{shear}(x)=[1-r(x)]2t\,h_{clear}(x)$ for the active orientation
- von Mises stress: $\sigma_{vm}(x)=\sqrt{\sigma_b(x)^2+3\tau(x)^2}$
- Factor of safety: $FoS(x)=\sigma_{allow,eff}/\sigma_{vm}(x)$

### Deflection and Objective

- Euler-Bernoulli relation: $E_{eff}I(x)v''(x)=M(x)$
- Weight objective: $W=\rho\int_0^L A(x)\,dx$
- Search objective used here: minimize weight while enforcing factor-of-safety and optional deflection constraints

## Automatic Equation Substitution

### Effective Material Properties

- $E_{eff} = E \times k_{orientation} \times k_{infill} = 500000.0 \times 0.700 \times 0.850 = 297500.0\ \text{psi}$
- $\sigma_{allow,eff} = \sigma_{allow} \times k_{orientation} \times k_{infill} = 4000.0 \times 0.700 \times 0.850 = 2380.0\ \text{psi}$
- $W = \rho \int_0^L A(x)\,dx = 0.04215\ \text{lbf}$
- Global governing factor of safety is the minimum value over all beam stations and over both load cases.

### Load Case 1

- Active bending orientation: upright (upright section properties)
- $R_A = P(L-a)/L = 5.000(8.000-4.000)/8.000 = 2.500\ \text{lbf}$
- $R_B = Pa/L = 5.000(4.000)/8.000 = 2.500\ \text{lbf}$
- $FoS_{min} = \sigma_{allow,eff}/\sigma_{vm,max} = 2380.0/1031.5 = 2.307$
- Governing location for this load case: $x = 4.000\ \text{in}$
- $\max |v(x)| = 0.05582\ \text{in}$
- $\max |\theta(x)| = 0.019223\ \text{rad}$

### Load Case 2

- Active bending orientation: side (side-rotated section properties)
- $R_A = P(L-a)/L = 8.000(8.000-5.000)/8.000 = 3.000\ \text{lbf}$
- $R_B = Pa/L = 8.000(5.000)/8.000 = 5.000\ \text{lbf}$
- $FoS_{min} = \sigma_{allow,eff}/\sigma_{vm,max} = 2380.0/1534.9 = 1.551$
- Governing location for this load case: $x = 4.000\ \text{in}$
- $\max |v(x)| = 0.11218\ \text{in}$
- $\max |\theta(x)| = 0.040035\ \text{rad}$

## Automatic Trail of Tried Designs

- Full design study table: `design_study.csv`
- Best design record: `best_design.json`
- Best-design plots folder: `best_design/`

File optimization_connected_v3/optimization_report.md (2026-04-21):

# Beam Optimization Report

## Search Summary

- Search method: stratified global sampling with elite local refinement
- Total evaluated designs: 1940
- Feasible designs found: 579
- Minimum required factor of safety: 1.500
- Objective shaping: penalize excess FoS margin and underutilized stress envelope so the design approaches the 1.5 target more closely
- Maximum allowed deflection: not enforced in this run
- Random seed: 9191

## Best Design

- Weight: 0.09583 lbf
- Minimum factor of safety: 1.804
- Excess FoS above target: 0.304
- Governing minimum-FoS load case: Load Case 2 at x = 5.000 in
- Maximum deflection: 0.05265 in
- Durability score (0 is best): 0.000000
- Constraint status: feasible

### Geometry Variables

| Variable | Value |
| --- | ---: |
| $L$ [in] | 8.000 |
| $L_{total}$ [in] | 9.000 |
| $b_L$ [in] | 0.719 |
| $b_M$ [in] | 0.350 |
| $b_R$ [in] | 0.350 |
| $h_L$ [in] | 0.691 |
| $h_M$ [in] | 1.250 |
| $h_R$ [in] | 1.091 |
| $t$ [in] | 0.149 |
| $r_L$ [-] | 0.084 |
| $r_M$ [-] | 0.602 |
| $r_R$ [-] | 0.281 |
| $E_{eff}$ [psi] | 297500.0 |
| $\sigma_{allow,eff}$ [psi] | 2380.0 |

### Best-Design Load-Case Metrics

| Load Case | Orientation | Load [lbf] | Location [in] | Min FoS | FoS x [in] | Max Deflection [in] | Max von Mises [psi] |
| --- | --- | ---: | ---: | ---: | ---: | ---: | ---: |
| Load Case 1 | upright | 5.000 | 4.000 | 17.728 | 4.000 | 0.00416 | 134.3 |
| Load Case 2 | side | 8.000 | 5.000 | 1.804 | 5.000 | 0.05265 | 1318.9 |

## Beam Structure and Parameters

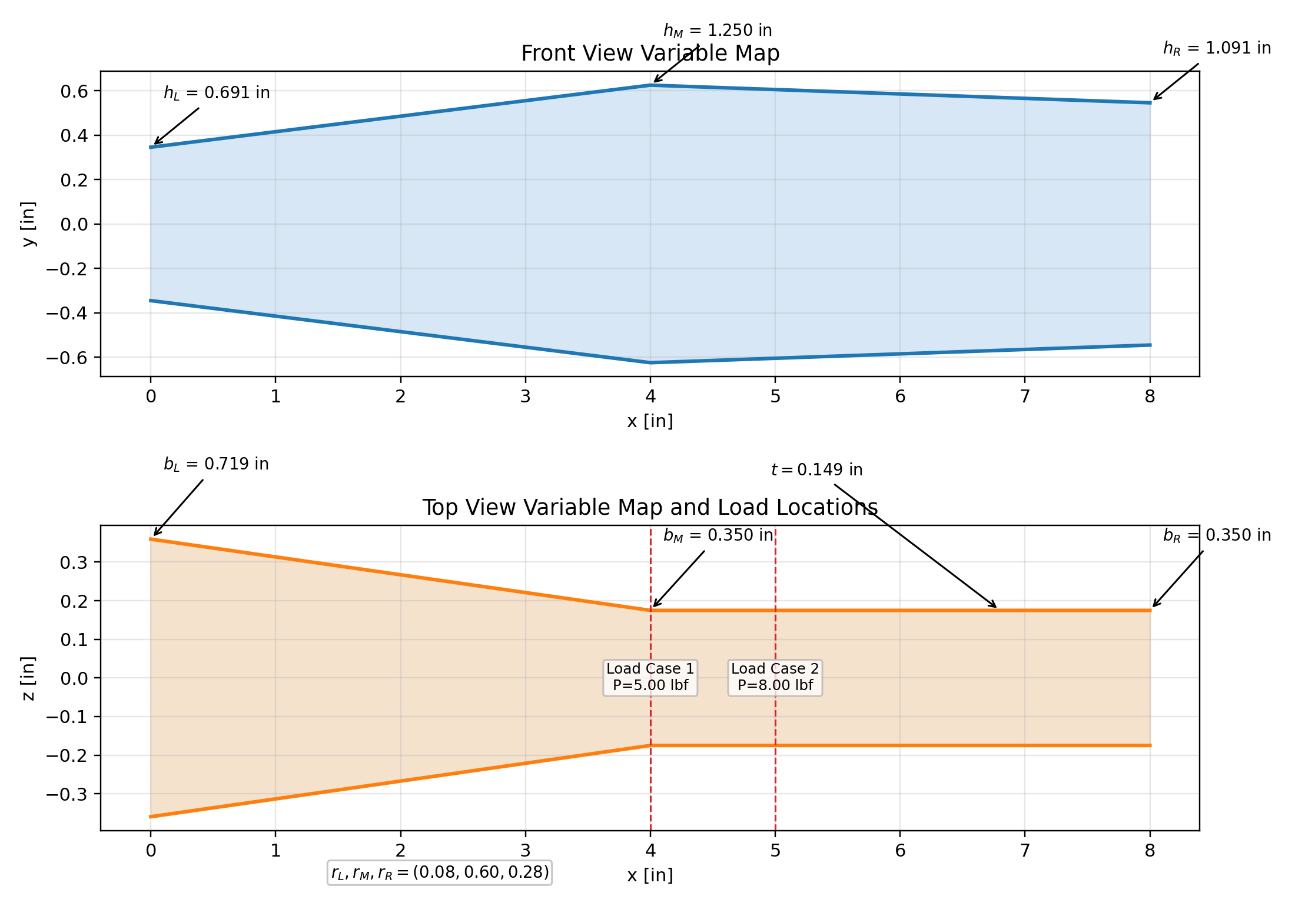
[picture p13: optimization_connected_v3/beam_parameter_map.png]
Beam parameter map


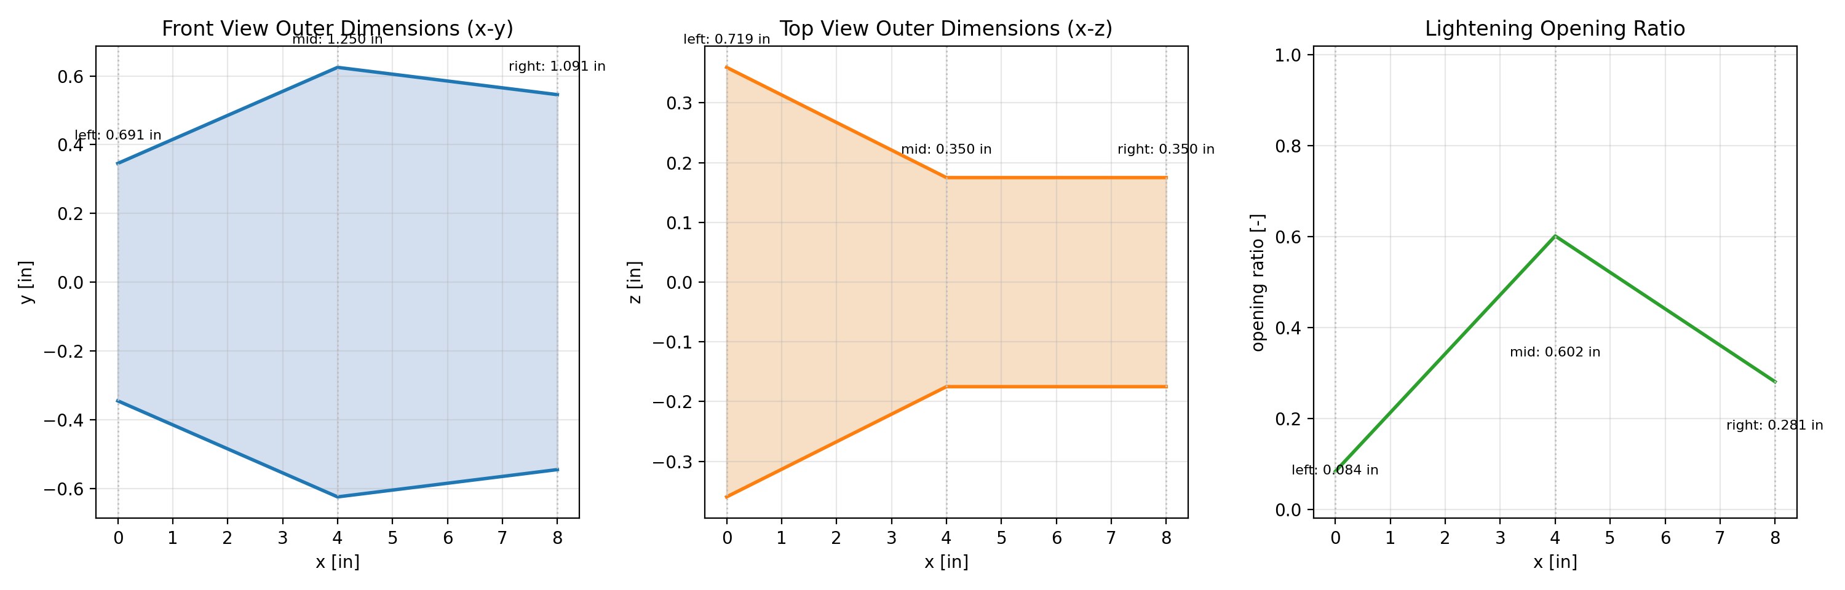
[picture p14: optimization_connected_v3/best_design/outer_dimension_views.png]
Outer dimension views


## General Equations

### Geometry

- $$b(x)=\begin{cases}0.7191 + (-0.0923)x, & 0 \le x \le 4.0000\\0.3500 + (0.0000)(x-4.0000), & 4.0000 < x \le 8.0000\end{cases}$$
- $$h(x)=\begin{cases}0.6910 + (0.1398)x, & 0 \le x \le 4.0000\\1.2500 + (-0.0397)(x-4.0000), & 4.0000 < x \le 8.0000\end{cases}$$
- $$r(x)=\begin{cases}0.0835 + (0.1295)x, & 0 \le x \le 4.0000\\0.6016 + (-0.0802)(x-4.0000), & 4.0000 < x \le 8.0000\end{cases}$$
- Hollow tube area with lightening openings: $A(x)=2b(x)t + [1-r(x)]2t[h(x)-2t]$
- Upright bending second moment: $I(x)=\frac{b(x)h(x)^3-[b(x)-2t][h(x)-2t]^3}{12}-2\frac{t[r(x)(h(x)-2t)]^3}{12}$
- Side-rotated bending second moment: $I_{side}(x)=\frac{h(x)b(x)^3-[h(x)-2t][b(x)-2t]^3}{12}-2\frac{t[r(x)(b(x)-2t)]^3}{12}$
- Section modulus: $S(x)=I(x)/c(x)$ with $c(x)=\text{outer vertical dimension}/2$

### Statics and Stress

- Reactions for a point load $P$ at $x=a$: $R_A=P(L-a)/L$, $R_B=Pa/L$
- Shear and moment: $V(x)$ and $M(x)$ are computed piecewise from the reactions and applied load
- Bending stress: $\sigma_b(x)=|M(x)|/S(x)$
- Shear stress estimate: $\tau(x)=|V(x)|/A_{shear}(x)$ with $A_{shear}(x)=[1-r(x)]2t\,h_{clear}(x)$ for the active orientation
- von Mises stress: $\sigma_{vm}(x)=\sqrt{\sigma_b(x)^2+3\tau(x)^2}$
- Factor of safety: $FoS(x)=\sigma_{allow,eff}/\sigma_{vm}(x)$

### Deflection and Objective

- Euler-Bernoulli relation: $E_{eff}I(x)v''(x)=M(x)$
- Weight objective: $W=\rho\int_0^L A(x)\,dx$
- Search objective used here: minimize weight while enforcing factor-of-safety and optional deflection constraints

## Automatic Equation Substitution

### Effective Material Properties

- $E_{eff} = E \times k_{orientation} \times k_{infill} = 500000.0 \times 0.700 \times 0.850 = 297500.0\ \text{psi}$
- $\sigma_{allow,eff} = \sigma_{allow} \times k_{orientation} \times k_{infill} = 4000.0 \times 0.700 \times 0.850 = 2380.0\ \text{psi}$
- $W = \rho \int_0^L A(x)\,dx = 0.09583\ \text{lbf}$
- Global governing factor of safety is the minimum value over all beam stations and over both load cases.

### Load Case 1

- Active bending orientation: upright (upright section properties)
- $R_A = P(L-a)/L = 5.000(8.000-4.000)/8.000 = 2.500\ \text{lbf}$
- $R_B = Pa/L = 5.000(4.000)/8.000 = 2.500\ \text{lbf}$
- $FoS_{min} = \sigma_{allow,eff}/\sigma_{vm,max} = 2380.0/134.3 = 17.728$
- Governing location for this load case: $x = 4.000\ \text{in}$
- $\max |v(x)| = 0.00416\ \text{in}$
- $\max |\theta(x)| = 0.001728\ \text{rad}$

### Load Case 2

- Active bending orientation: side (side-rotated section properties)
- $R_A = P(L-a)/L = 8.000(8.000-5.000)/8.000 = 3.000\ \text{lbf}$
- $R_B = Pa/L = 8.000(5.000)/8.000 = 5.000\ \text{lbf}$
- $FoS_{min} = \sigma_{allow,eff}/\sigma_{vm,max} = 2380.0/1318.9 = 1.804$
- Governing location for this load case: $x = 5.000\ \text{in}$
- $\max |v(x)| = 0.05265\ \text{in}$
- $\max |\theta(x)| = 0.023306\ \text{rad}$

## Automatic Trail of Tried Designs

- Full design study table: `design_study.csv`
- Best design record: `best_design.json`
- Best-design plots folder: `best_design/`

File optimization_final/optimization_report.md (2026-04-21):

# Beam Optimization Report

## Search Summary

- Search method: stratified global sampling with elite local refinement
- Total evaluated designs: 1300
- Feasible designs found: 684
- Minimum required factor of safety: 1.500
- Objective shaping: penalize excess FoS margin and underutilized stress envelope so the design approaches the 1.5 target more closely
- Maximum allowed deflection: not enforced in this run
- Random seed: 7777

## Best Design

- Weight: 0.03454 lbf
- Minimum factor of safety: 1.522
- Excess FoS above target: 0.022
- Governing minimum-FoS load case: Load Case 2 at x = 5.000 in
- Maximum deflection: 0.11608 in
- Constraint status: feasible

### Geometry Variables

| Variable | Value |
| --- | ---: |
| $L$ [in] | 8.000 |
| $L_{total}$ [in] | 9.000 |
| $b_L$ [in] | 0.823 |
| $b_M$ [in] | 0.350 |
| $b_R$ [in] | 0.350 |
| $h_L$ [in] | 0.959 |
| $h_M$ [in] | 0.727 |
| $h_R$ [in] | 0.606 |
| $t$ [in] | 0.060 |
| $r_L$ [-] | 0.334 |
| $r_M$ [-] | 0.650 |
| $r_R$ [-] | 0.276 |
| $E_{eff}$ [psi] | 297500.0 |
| $\sigma_{allow,eff}$ [psi] | 2380.0 |

### Best-Design Load-Case Metrics

| Load Case | Orientation | Load [lbf] | Location [in] | Min FoS | FoS x [in] | Max Deflection [in] | Max von Mises [psi] |
| --- | --- | ---: | ---: | ---: | ---: | ---: | ---: |
| Load Case 1 | upright | 5.000 | 4.000 | 3.956 | 4.000 | 0.02538 | 601.6 |
| Load Case 2 | side | 8.000 | 5.000 | 1.522 | 5.000 | 0.11608 | 1563.8 |

## Beam Structure and Parameters

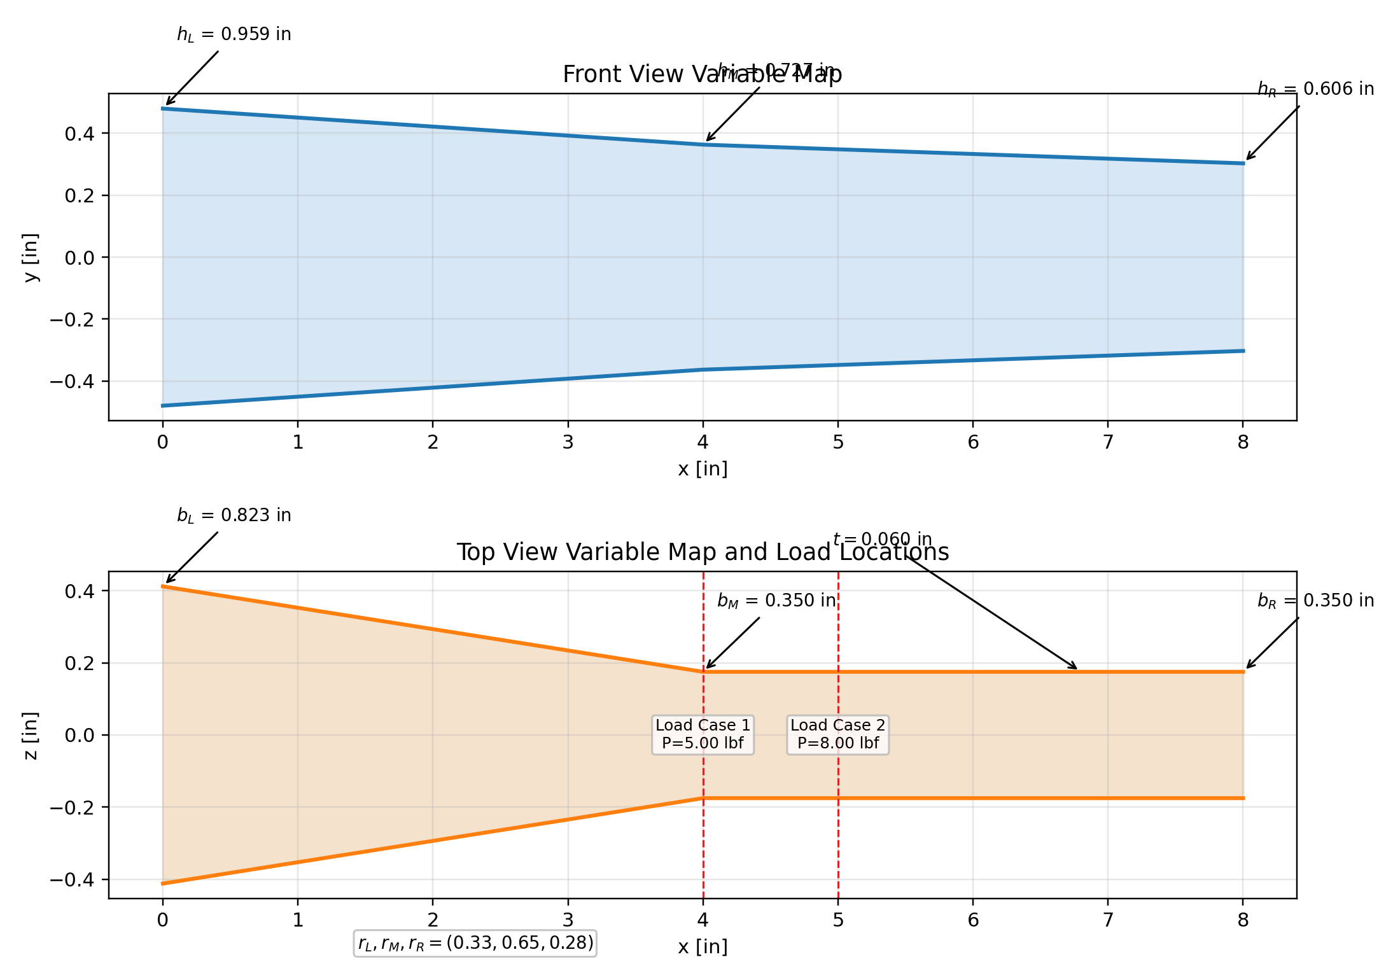
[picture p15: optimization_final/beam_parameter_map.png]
Beam parameter map


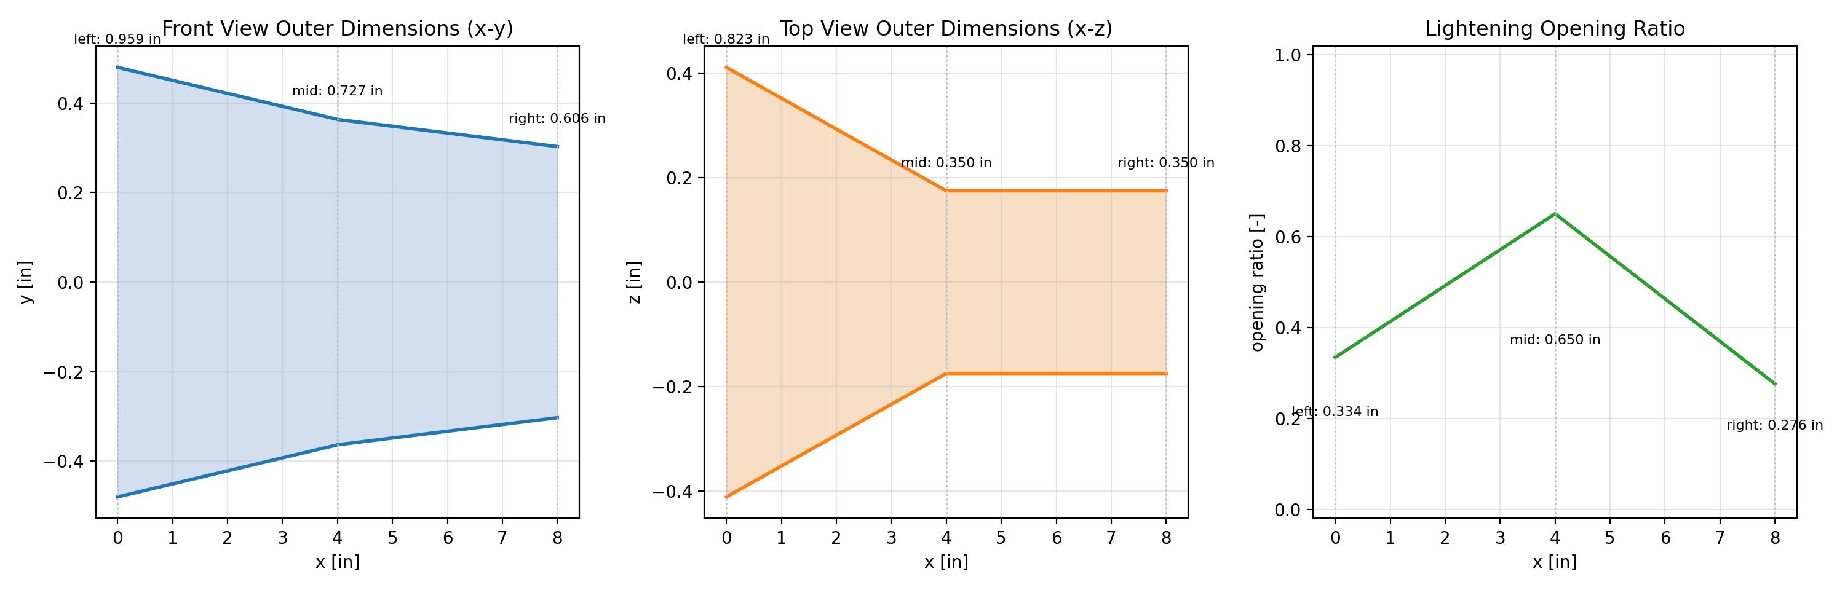
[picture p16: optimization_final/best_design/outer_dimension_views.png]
Outer dimension views


## General Equations

### Geometry

- $$b(x)=\begin{cases}0.8230 + (-0.1183)x, & 0 \le x \le 4.0000\\0.3500 + (0.0000)(x-4.0000), & 4.0000 < x \le 8.0000\end{cases}$$
- $$h(x)=\begin{cases}0.9594 + (-0.0582)x, & 0 \le x \le 4.0000\\0.7266 + (-0.0302)(x-4.0000), & 4.0000 < x \le 8.0000\end{cases}$$
- $$r(x)=\begin{cases}0.3342 + (0.0790)x, & 0 \le x \le 4.0000\\0.6504 + (-0.0936)(x-4.0000), & 4.0000 < x \le 8.0000\end{cases}$$
- Hollow tube area with lightening openings: $A(x)=2b(x)t + [1-r(x)]2t[h(x)-2t]$
- Upright bending second moment: $I(x)=\frac{b(x)h(x)^3-[b(x)-2t][h(x)-2t]^3}{12}-2\frac{t[r(x)(h(x)-2t)]^3}{12}$
- Side-rotated bending second moment: $I_{side}(x)=\frac{h(x)b(x)^3-[h(x)-2t][b(x)-2t]^3}{12}-2\frac{t[r(x)(b(x)-2t)]^3}{12}$
- Section modulus: $S(x)=I(x)/c(x)$ with $c(x)=\text{outer vertical dimension}/2$

### Statics and Stress

- Reactions for a point load $P$ at $x=a$: $R_A=P(L-a)/L$, $R_B=Pa/L$
- Shear and moment: $V(x)$ and $M(x)$ are computed piecewise from the reactions and applied load
- Bending stress: $\sigma_b(x)=|M(x)|/S(x)$
- Shear stress estimate: $\tau(x)=|V(x)|/A_{shear}(x)$ with $A_{shear}(x)=[1-r(x)]2t\,h_{clear}(x)$ for the active orientation
- von Mises stress: $\sigma_{vm}(x)=\sqrt{\sigma_b(x)^2+3\tau(x)^2}$
- Factor of safety: $FoS(x)=\sigma_{allow,eff}/\sigma_{vm}(x)$

### Deflection and Objective

- Euler-Bernoulli relation: $E_{eff}I(x)v''(x)=M(x)$
- Weight objective: $W=\rho\int_0^L A(x)\,dx$
- Search objective used here: minimize weight while enforcing factor-of-safety and optional deflection constraints

## Automatic Equation Substitution

### Effective Material Properties

- $E_{eff} = E \times k_{orientation} \times k_{infill} = 500000.0 \times 0.700 \times 0.850 = 297500.0\ \text{psi}$
- $\sigma_{allow,eff} = \sigma_{allow} \times k_{orientation} \times k_{infill} = 4000.0 \times 0.700 \times 0.850 = 2380.0\ \text{psi}$
- $W = \rho \int_0^L A(x)\,dx = 0.03454\ \text{lbf}$
- Global governing factor of safety is the minimum value over all beam stations and over both load cases.

### Load Case 1

- Active bending orientation: upright (upright section properties)
- $R_A = P(L-a)/L = 5.000(8.000-4.000)/8.000 = 2.500\ \text{lbf}$
- $R_B = Pa/L = 5.000(4.000)/8.000 = 2.500\ \text{lbf}$
- $FoS_{min} = \sigma_{allow,eff}/\sigma_{vm,max} = 2380.0/601.6 = 3.956$
- Governing location for this load case: $x = 4.000\ \text{in}$
- $\max |v(x)| = 0.02538\ \text{in}$
- $\max |\theta(x)| = 0.010536\ \text{rad}$

### Load Case 2

- Active bending orientation: side (side-rotated section properties)
- $R_A = P(L-a)/L = 8.000(8.000-5.000)/8.000 = 3.000\ \text{lbf}$
- $R_B = Pa/L = 8.000(5.000)/8.000 = 5.000\ \text{lbf}$
- $FoS_{min} = \sigma_{allow,eff}/\sigma_{vm,max} = 2380.0/1563.8 = 1.522$
- Governing location for this load case: $x = 5.000\ \text{in}$
- $\max |v(x)| = 0.11608\ \text{in}$
- $\max |\theta(x)| = 0.052181\ \text{rad}$

## Automatic Trail of Tried Designs

- Full design study table: `design_study.csv`
- Best design record: `best_design.json`
- Best-design plots folder: `best_design/`

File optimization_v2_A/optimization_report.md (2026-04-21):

# Beam Optimization Report

## Search Summary

- Search method: stratified global sampling with elite local refinement
- Total evaluated designs: 760
- Feasible designs found: 717
- Minimum required factor of safety: 1.500
- Objective shaping: penalize excess FoS margin and underutilized stress envelope so the design approaches the 1.5 target more closely
- Maximum allowed deflection: not enforced in this run
- Random seed: 42

## Best Design

- Weight: 0.05057 lbf
- Minimum factor of safety: 3.157
- Excess FoS above target: 1.657
- Governing minimum-FoS load case: Load Case 1 at x = 4.000 in
- Maximum deflection: 0.02303 in
- Constraint status: feasible

### Geometry Variables

| Variable | Value |
| --- | ---: |
| $L$ [in] | 8.000 |
| $L_{total}$ [in] | 9.000 |
| $b_L$ [in] | 1.099 |
| $b_M$ [in] | 0.450 |
| $b_R$ [in] | 1.431 |
| $h_L$ [in] | 1.387 |
| $h_M$ [in] | 0.550 |
| $h_R$ [in] | 0.958 |
| $t$ [in] | 0.060 |
| $r_L$ [-] | 0.630 |
| $r_M$ [-] | 0.644 |
| $r_R$ [-] | 0.384 |
| $E_{eff}$ [psi] | 297500.0 |
| $\sigma_{allow,eff}$ [psi] | 2380.0 |

### Best-Design Load-Case Metrics

| Load Case | Orientation | Load [lbf] | Location [in] | Min FoS | FoS x [in] | Max Deflection [in] | Max von Mises [psi] |
| --- | --- | ---: | ---: | ---: | ---: | ---: | ---: |
| Load Case 1 | upright | 5.000 | 4.000 | 3.157 | 4.000 | 0.02303 | 754.0 |
| Load Case 2 | side | 3.000 | 2.500 | 7.360 | 4.000 | 0.01260 | 323.4 |

## Beam Structure and Parameters

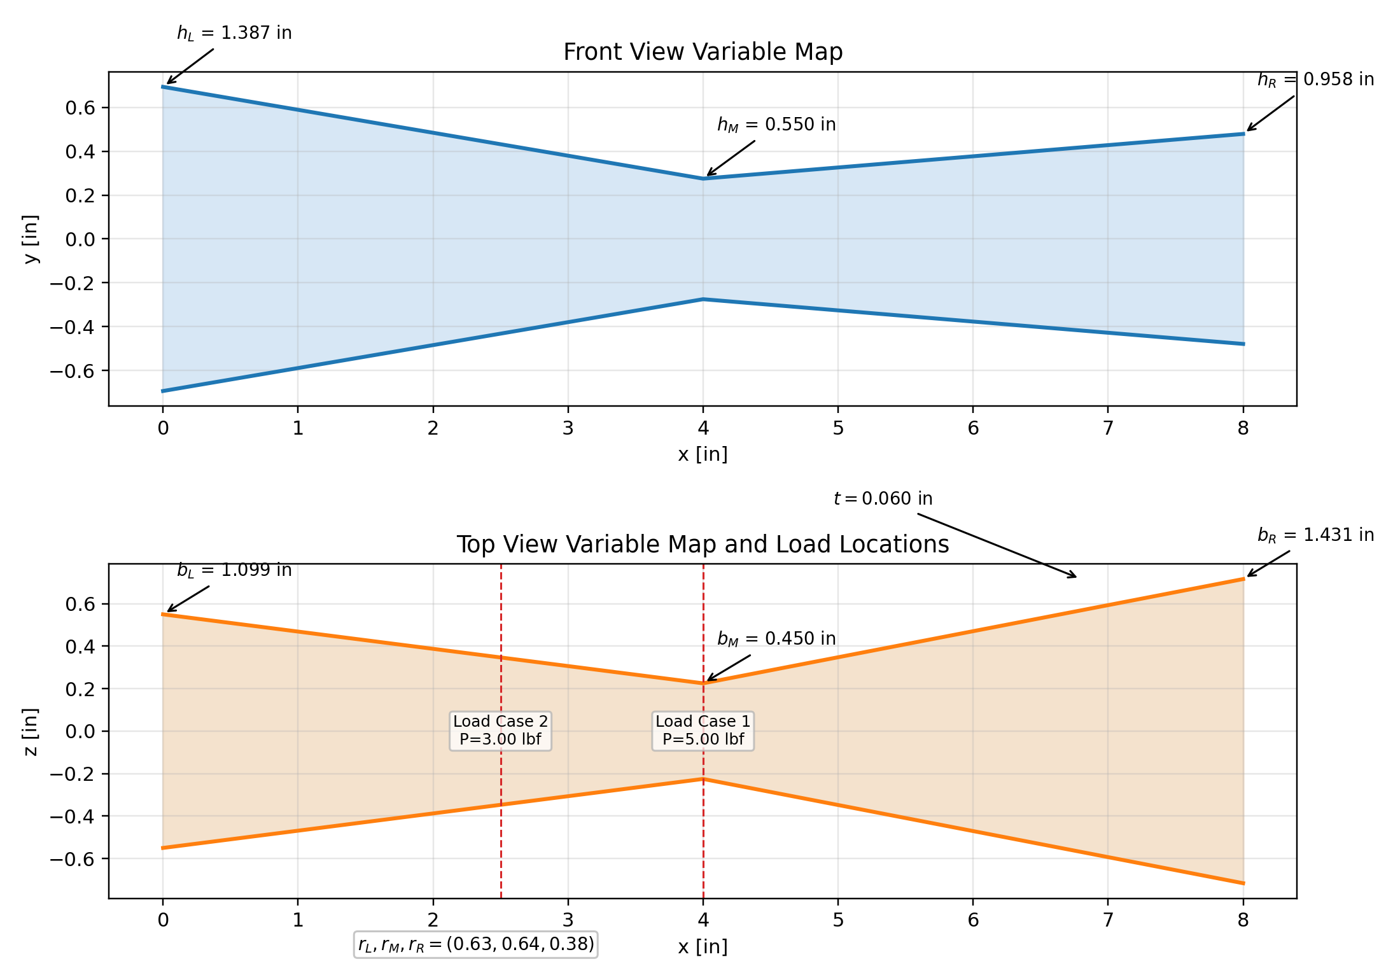
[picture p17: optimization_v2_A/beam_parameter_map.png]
Beam parameter map


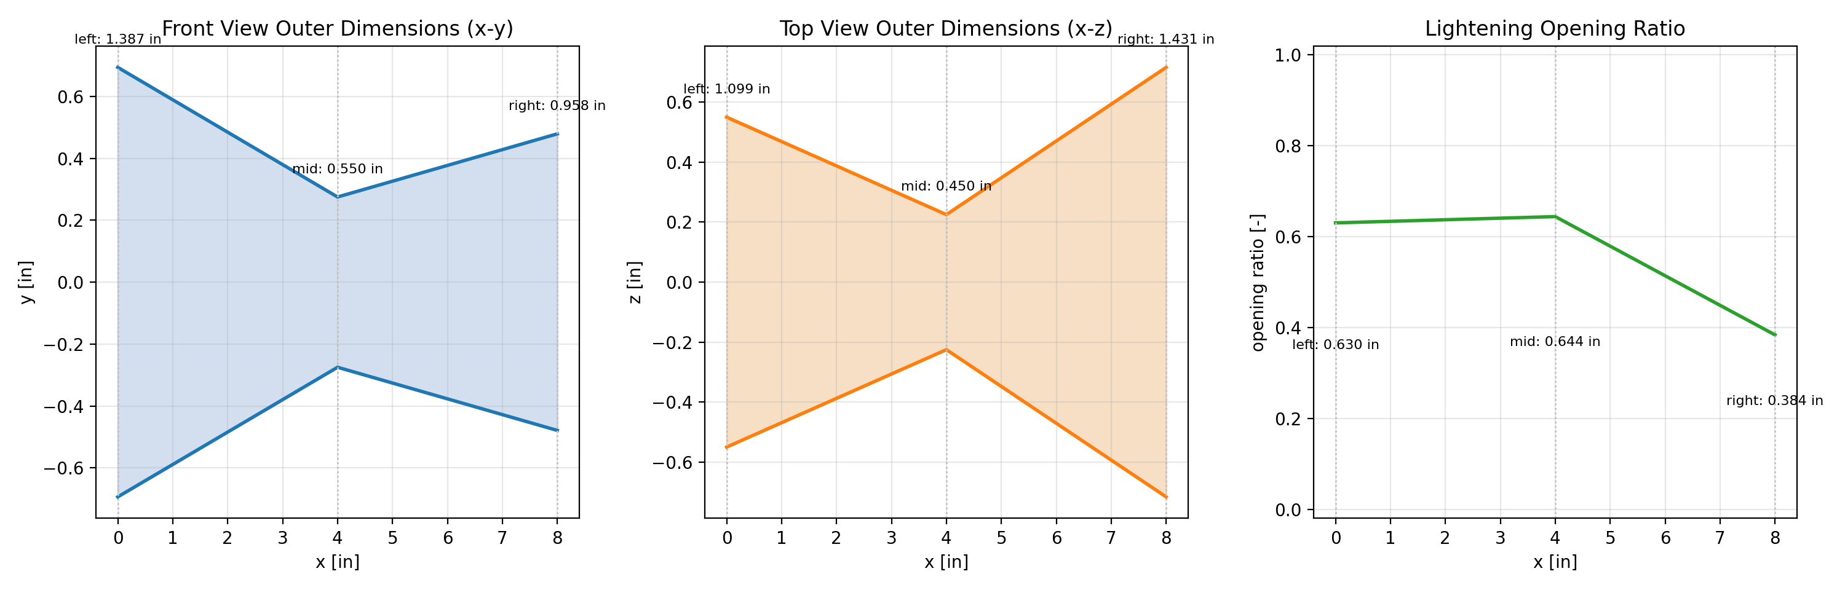
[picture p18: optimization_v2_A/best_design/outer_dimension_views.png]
Outer dimension views


## General Equations

### Geometry

- $$b(x)=\begin{cases}1.0994 + (-0.1623)x, & 0 \le x \le 4.0000\\0.4500 + (0.2453)(x-4.0000), & 4.0000 < x \le 8.0000\end{cases}$$
- $$h(x)=\begin{cases}1.3875 + (-0.2094)x, & 0 \le x \le 4.0000\\0.5500 + (0.1020)(x-4.0000), & 4.0000 < x \le 8.0000\end{cases}$$
- $$r(x)=\begin{cases}0.6304 + (0.0035)x, & 0 \le x \le 4.0000\\0.6442 + (-0.0651)(x-4.0000), & 4.0000 < x \le 8.0000\end{cases}$$
- Hollow tube area with lightening openings: $A(x)=2b(x)t + [1-r(x)]2t[h(x)-2t]$
- Upright bending second moment: $I(x)=\frac{b(x)h(x)^3-[b(x)-2t][h(x)-2t]^3}{12}-2\frac{t[r(x)(h(x)-2t)]^3}{12}$
- Side-rotated bending second moment: $I_{side}(x)=\frac{h(x)b(x)^3-[h(x)-2t][b(x)-2t]^3}{12}-2\frac{t[r(x)(b(x)-2t)]^3}{12}$
- Section modulus: $S(x)=I(x)/c(x)$ with $c(x)=\text{outer vertical dimension}/2$

### Statics and Stress

- Reactions for a point load $P$ at $x=a$: $R_A=P(L-a)/L$, $R_B=Pa/L$
- Shear and moment: $V(x)$ and $M(x)$ are computed piecewise from the reactions and applied load
- Bending stress: $\sigma_b(x)=|M(x)|/S(x)$
- Shear stress estimate: $\tau(x)=|V(x)|/A_{shear}(x)$ with $A_{shear}(x)=[1-r(x)]2t\,h_{clear}(x)$ for the active orientation
- von Mises stress: $\sigma_{vm}(x)=\sqrt{\sigma_b(x)^2+3\tau(x)^2}$
- Factor of safety: $FoS(x)=\sigma_{allow,eff}/\sigma_{vm}(x)$

### Deflection and Objective

- Euler-Bernoulli relation: $E_{eff}I(x)v''(x)=M(x)$
- Weight objective: $W=\rho\int_0^L A(x)\,dx$
- Search objective used here: minimize weight while enforcing factor-of-safety and optional deflection constraints

## Automatic Equation Substitution

### Effective Material Properties

- $E_{eff} = E \times k_{orientation} \times k_{infill} = 500000.0 \times 0.700 \times 0.850 = 297500.0\ \text{psi}$
- $\sigma_{allow,eff} = \sigma_{allow} \times k_{orientation} \times k_{infill} = 4000.0 \times 0.700 \times 0.850 = 2380.0\ \text{psi}$
- $W = \rho \int_0^L A(x)\,dx = 0.05057\ \text{lbf}$
- Global governing factor of safety is the minimum value over all beam stations and over both load cases.

### Load Case 1

- Active bending orientation: upright (upright section properties)
- $R_A = P(L-a)/L = 5.000(8.000-4.000)/8.000 = 2.500\ \text{lbf}$
- $R_B = Pa/L = 5.000(4.000)/8.000 = 2.500\ \text{lbf}$
- $FoS_{min} = \sigma_{allow,eff}/\sigma_{vm,max} = 2380.0/754.0 = 3.157$
- Governing location for this load case: $x = 4.000\ \text{in}$
- $\max |v(x)| = 0.02303\ \text{in}$
- $\max |\theta(x)| = 0.007449\ \text{rad}$

### Load Case 2

- Active bending orientation: side (side-rotated section properties)
- $R_A = P(L-a)/L = 3.000(8.000-2.500)/8.000 = 2.062\ \text{lbf}$
- $R_B = Pa/L = 3.000(2.500)/8.000 = 0.938\ \text{lbf}$
- $FoS_{min} = \sigma_{allow,eff}/\sigma_{vm,max} = 2380.0/323.4 = 7.360$
- Governing location for this load case: $x = 4.000\ \text{in}$
- $\max |v(x)| = 0.01260\ \text{in}$
- $\max |\theta(x)| = 0.004326\ \text{rad}$

## Automatic Trail of Tried Designs

- Full design study table: `design_study.csv`
- Best design record: `best_design.json`
- Best-design plots folder: `best_design/`

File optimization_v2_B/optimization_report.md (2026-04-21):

# Beam Optimization Report

## Search Summary

- Search method: stratified global sampling with elite local refinement
- Total evaluated designs: 760
- Feasible designs found: 702
- Minimum required factor of safety: 1.500
- Objective shaping: penalize excess FoS margin and underutilized stress envelope so the design approaches the 1.5 target more closely
- Maximum allowed deflection: not enforced in this run
- Random seed: 1618

## Best Design

- Weight: 0.04815 lbf
- Minimum factor of safety: 3.289
- Excess FoS above target: 1.789
- Governing minimum-FoS load case: Load Case 1 at x = 4.000 in
- Maximum deflection: 0.02037 in
- Constraint status: feasible

### Geometry Variables

| Variable | Value |
| --- | ---: |
| $L$ [in] | 8.000 |
| $L_{total}$ [in] | 9.000 |
| $b_L$ [in] | 0.450 |
| $b_M$ [in] | 0.484 |
| $b_R$ [in] | 1.014 |
| $h_L$ [in] | 1.519 |
| $h_M$ [in] | 0.550 |
| $h_R$ [in] | 1.561 |
| $t$ [in] | 0.060 |
| $r_L$ [-] | 0.299 |
| $r_M$ [-] | 0.671 |
| $r_R$ [-] | 0.301 |
| $E_{eff}$ [psi] | 297500.0 |
| $\sigma_{allow,eff}$ [psi] | 2380.0 |

### Best-Design Load-Case Metrics

| Load Case | Orientation | Load [lbf] | Location [in] | Min FoS | FoS x [in] | Max Deflection [in] | Max von Mises [psi] |
| --- | --- | ---: | ---: | ---: | ---: | ---: | ---: |
| Load Case 1 | upright | 5.000 | 4.000 | 3.289 | 4.000 | 0.02037 | 723.6 |
| Load Case 2 | side | 3.000 | 2.500 | 7.933 | 2.490 | 0.01728 | 300.0 |

## Beam Structure and Parameters

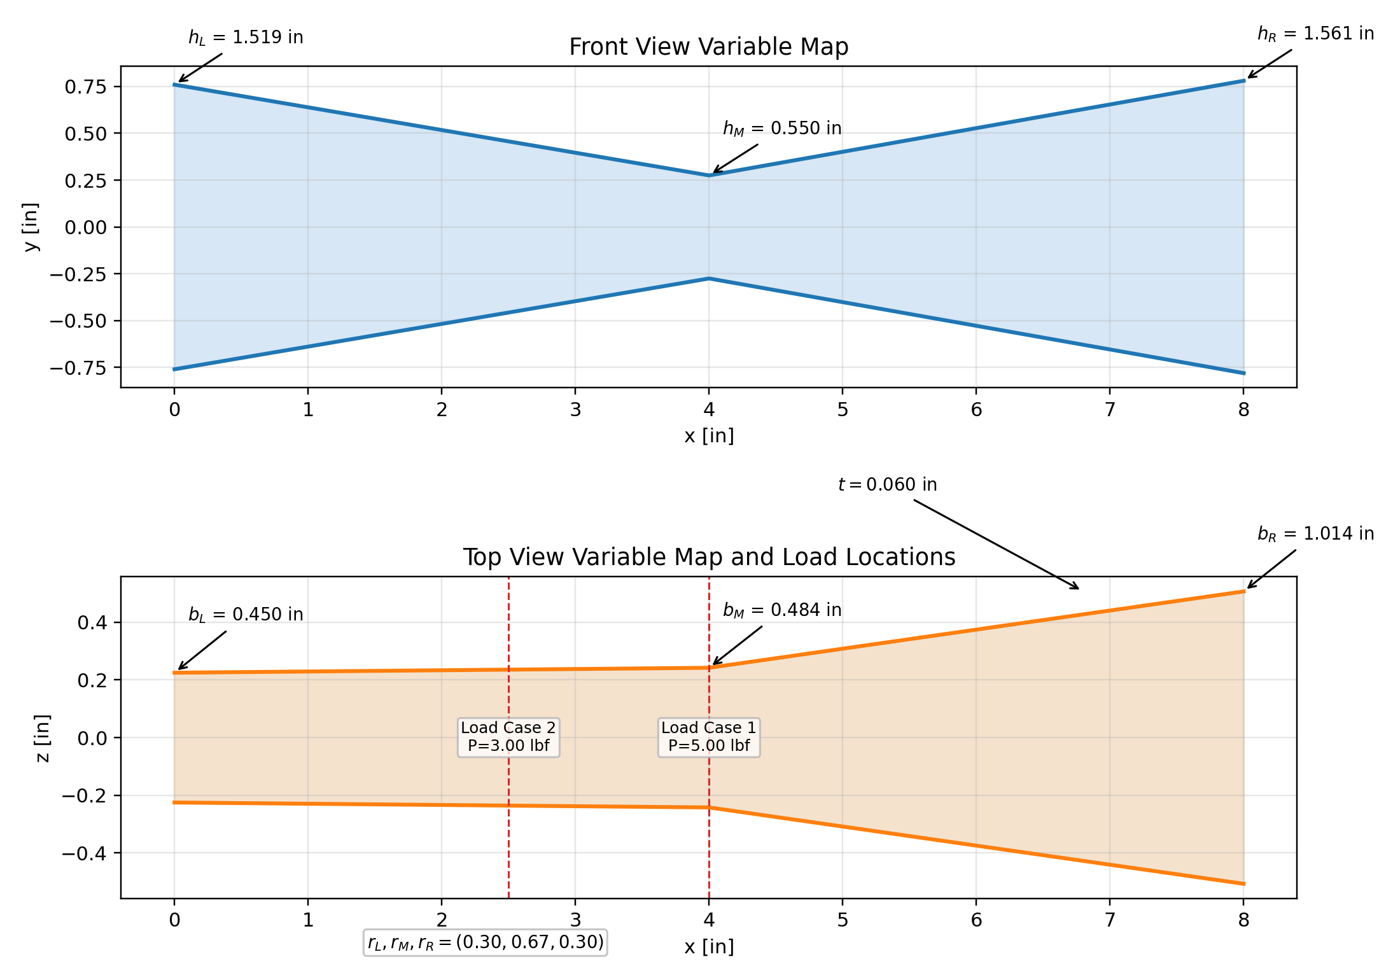
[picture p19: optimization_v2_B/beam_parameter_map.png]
Beam parameter map


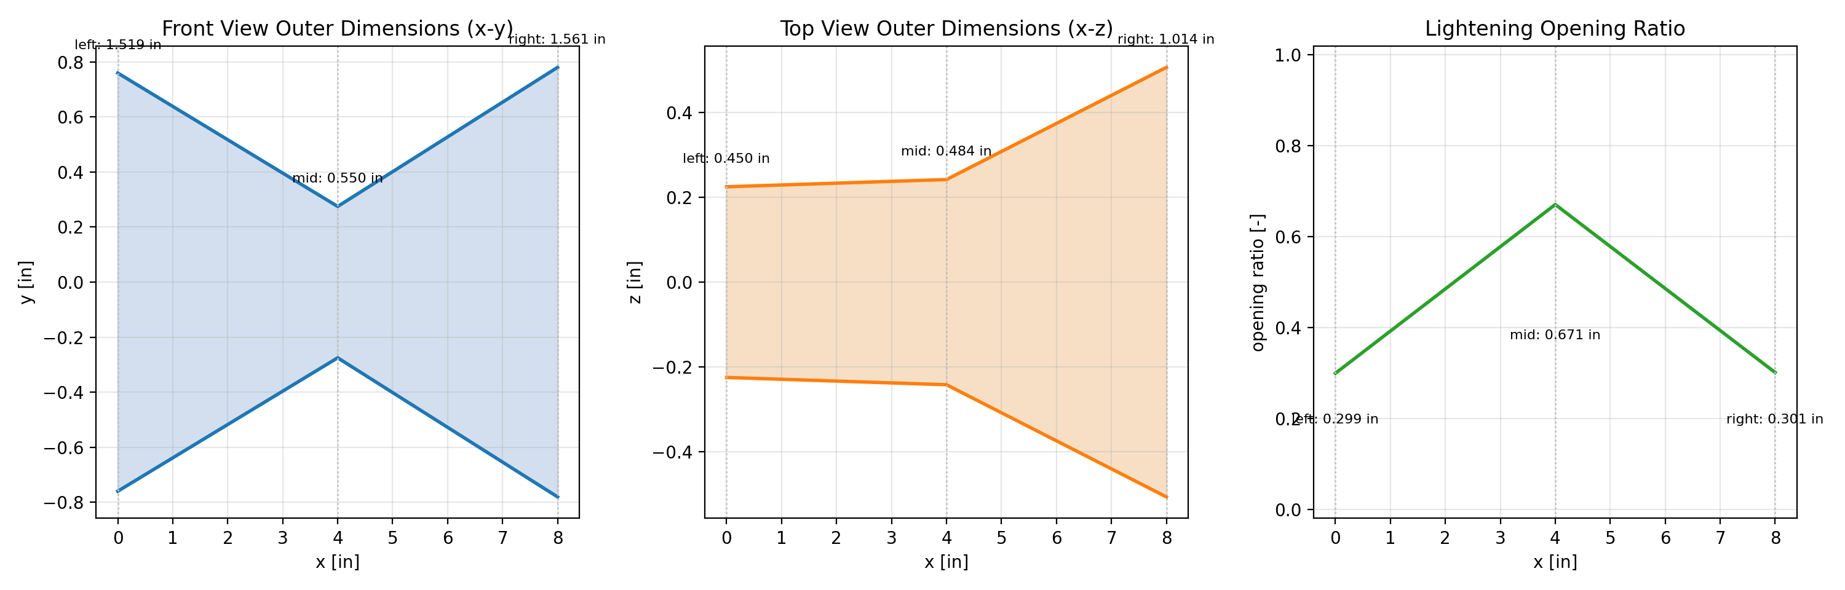
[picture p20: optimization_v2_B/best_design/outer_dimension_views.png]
Outer dimension views


## General Equations

### Geometry

- $$b(x)=\begin{cases}0.4500 + (0.0086)x, & 0 \le x \le 4.0000\\0.4843 + (0.1324)(x-4.0000), & 4.0000 < x \le 8.0000\end{cases}$$
- $$h(x)=\begin{cases}1.5194 + (-0.2423)x, & 0 \le x \le 4.0000\\0.5500 + (0.2527)(x-4.0000), & 4.0000 < x \le 8.0000\end{cases}$$
- $$r(x)=\begin{cases}0.2994 + (0.0929)x, & 0 \le x \le 4.0000\\0.6708 + (-0.0924)(x-4.0000), & 4.0000 < x \le 8.0000\end{cases}$$
- Hollow tube area with lightening openings: $A(x)=2b(x)t + [1-r(x)]2t[h(x)-2t]$
- Upright bending second moment: $I(x)=\frac{b(x)h(x)^3-[b(x)-2t][h(x)-2t]^3}{12}-2\frac{t[r(x)(h(x)-2t)]^3}{12}$
- Side-rotated bending second moment: $I_{side}(x)=\frac{h(x)b(x)^3-[h(x)-2t][b(x)-2t]^3}{12}-2\frac{t[r(x)(b(x)-2t)]^3}{12}$
- Section modulus: $S(x)=I(x)/c(x)$ with $c(x)=\text{outer vertical dimension}/2$

### Statics and Stress

- Reactions for a point load $P$ at $x=a$: $R_A=P(L-a)/L$, $R_B=Pa/L$
- Shear and moment: $V(x)$ and $M(x)$ are computed piecewise from the reactions and applied load
- Bending stress: $\sigma_b(x)=|M(x)|/S(x)$
- Shear stress estimate: $\tau(x)=|V(x)|/A_{shear}(x)$ with $A_{shear}(x)=[1-r(x)]2t\,h_{clear}(x)$ for the active orientation
- von Mises stress: $\sigma_{vm}(x)=\sqrt{\sigma_b(x)^2+3\tau(x)^2}$
- Factor of safety: $FoS(x)=\sigma_{allow,eff}/\sigma_{vm}(x)$

### Deflection and Objective

- Euler-Bernoulli relation: $E_{eff}I(x)v''(x)=M(x)$
- Weight objective: $W=\rho\int_0^L A(x)\,dx$
- Search objective used here: minimize weight while enforcing factor-of-safety and optional deflection constraints

## Automatic Equation Substitution

### Effective Material Properties

- $E_{eff} = E \times k_{orientation} \times k_{infill} = 500000.0 \times 0.700 \times 0.850 = 297500.0\ \text{psi}$
- $\sigma_{allow,eff} = \sigma_{allow} \times k_{orientation} \times k_{infill} = 4000.0 \times 0.700 \times 0.850 = 2380.0\ \text{psi}$
- $W = \rho \int_0^L A(x)\,dx = 0.04815\ \text{lbf}$
- Global governing factor of safety is the minimum value over all beam stations and over both load cases.

### Load Case 1

- Active bending orientation: upright (upright section properties)
- $R_A = P(L-a)/L = 5.000(8.000-4.000)/8.000 = 2.500\ \text{lbf}$
- $R_B = Pa/L = 5.000(4.000)/8.000 = 2.500\ \text{lbf}$
- $FoS_{min} = \sigma_{allow,eff}/\sigma_{vm,max} = 2380.0/723.6 = 3.289$
- Governing location for this load case: $x = 4.000\ \text{in}$
- $\max |v(x)| = 0.02037\ \text{in}$
- $\max |\theta(x)| = 0.006481\ \text{rad}$

### Load Case 2

- Active bending orientation: side (side-rotated section properties)
- $R_A = P(L-a)/L = 3.000(8.000-2.500)/8.000 = 2.062\ \text{lbf}$
- $R_B = Pa/L = 3.000(2.500)/8.000 = 0.938\ \text{lbf}$
- $FoS_{min} = \sigma_{allow,eff}/\sigma_{vm,max} = 2380.0/300.0 = 7.933$
- Governing location for this load case: $x = 2.490\ \text{in}$
- $\max |v(x)| = 0.01728\ \text{in}$
- $\max |\theta(x)| = 0.007329\ \text{rad}$

## Automatic Trail of Tried Designs

- Full design study table: `design_study.csv`
- Best design record: `best_design.json`
- Best-design plots folder: `best_design/`

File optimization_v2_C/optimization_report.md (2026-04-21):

# Beam Optimization Report

## Search Summary

- Search method: stratified global sampling with elite local refinement
- Total evaluated designs: 760
- Feasible designs found: 496
- Minimum required factor of safety: 1.500
- Objective shaping: penalize excess FoS margin and underutilized stress envelope so the design approaches the 1.5 target more closely
- Maximum allowed deflection: not enforced in this run
- Random seed: 42

## Best Design

- Weight: 0.02779 lbf
- Minimum factor of safety: 1.543
- Excess FoS above target: 0.043
- Governing minimum-FoS load case: Load Case 1 at x = 4.000 in
- Maximum deflection: 0.09024 in
- Constraint status: feasible

### Geometry Variables

| Variable | Value |
| --- | ---: |
| $L$ [in] | 8.000 |
| $L_{total}$ [in] | 9.000 |
| $b_L$ [in] | 0.442 |
| $b_M$ [in] | 0.350 |
| $b_R$ [in] | 0.480 |
| $h_L$ [in] | 0.450 |
| $h_M$ [in] | 0.380 |
| $h_R$ [in] | 1.300 |
| $t$ [in] | 0.061 |
| $r_L$ [-] | 0.480 |
| $r_M$ [-] | 0.518 |
| $r_R$ [-] | 0.622 |
| $E_{eff}$ [psi] | 297500.0 |
| $\sigma_{allow,eff}$ [psi] | 2380.0 |

### Best-Design Load-Case Metrics

| Load Case | Orientation | Load [lbf] | Location [in] | Min FoS | FoS x [in] | Max Deflection [in] | Max von Mises [psi] |
| --- | --- | ---: | ---: | ---: | ---: | ---: | ---: |
| Load Case 1 | upright | 5.000 | 4.000 | 1.543 | 4.000 | 0.09024 | 1542.0 |
| Load Case 2 | side | 3.000 | 2.500 | 3.379 | 2.490 | 0.05877 | 704.3 |

## Beam Structure and Parameters

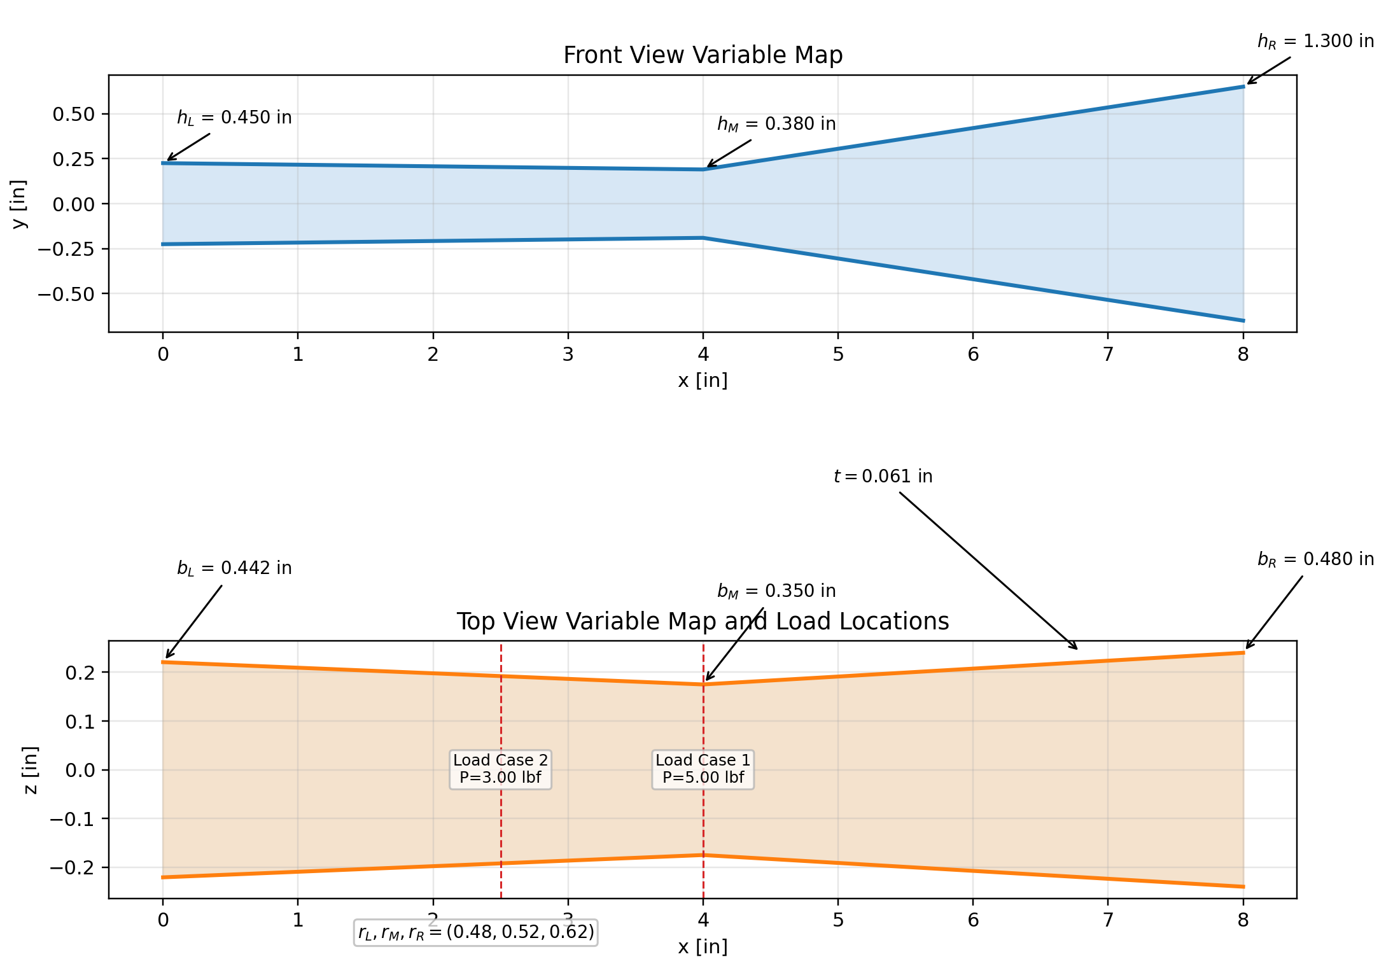
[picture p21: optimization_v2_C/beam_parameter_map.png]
Beam parameter map


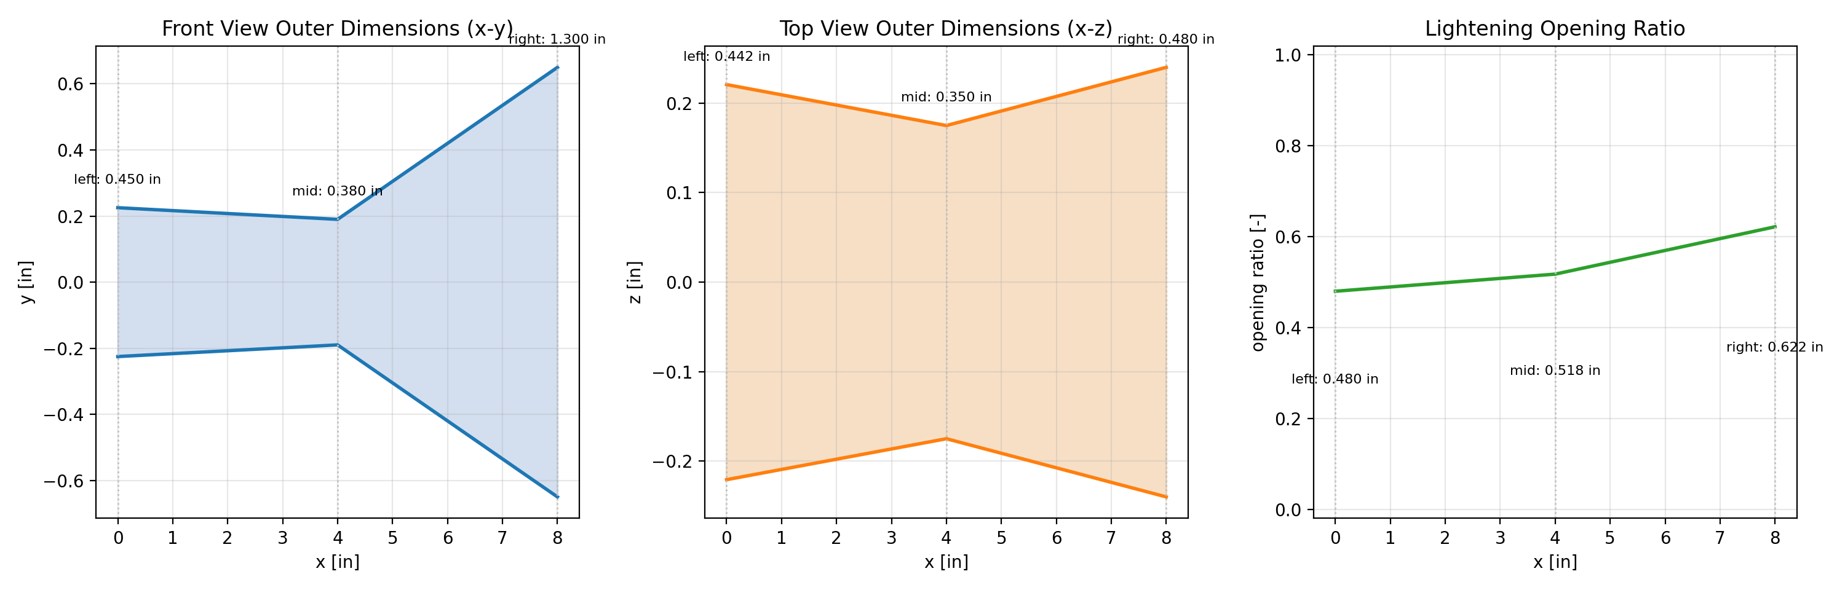
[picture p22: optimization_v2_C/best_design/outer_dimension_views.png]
Outer dimension views


## General Equations

### Geometry

- $$b(x)=\begin{cases}0.4416 + (-0.0229)x, & 0 \le x \le 4.0000\\0.3500 + (0.0325)(x-4.0000), & 4.0000 < x \le 8.0000\end{cases}$$
- $$h(x)=\begin{cases}0.4505 + (-0.0176)x, & 0 \le x \le 4.0000\\0.3800 + (0.2300)(x-4.0000), & 4.0000 < x \le 8.0000\end{cases}$$
- $$r(x)=\begin{cases}0.4799 + (0.0094)x, & 0 \le x \le 4.0000\\0.5176 + (0.0260)(x-4.0000), & 4.0000 < x \le 8.0000\end{cases}$$
- Hollow tube area with lightening openings: $A(x)=2b(x)t + [1-r(x)]2t[h(x)-2t]$
- Upright bending second moment: $I(x)=\frac{b(x)h(x)^3-[b(x)-2t][h(x)-2t]^3}{12}-2\frac{t[r(x)(h(x)-2t)]^3}{12}$
- Side-rotated bending second moment: $I_{side}(x)=\frac{h(x)b(x)^3-[h(x)-2t][b(x)-2t]^3}{12}-2\frac{t[r(x)(b(x)-2t)]^3}{12}$
- Section modulus: $S(x)=I(x)/c(x)$ with $c(x)=\text{outer vertical dimension}/2$

### Statics and Stress

- Reactions for a point load $P$ at $x=a$: $R_A=P(L-a)/L$, $R_B=Pa/L$
- Shear and moment: $V(x)$ and $M(x)$ are computed piecewise from the reactions and applied load
- Bending stress: $\sigma_b(x)=|M(x)|/S(x)$
- Shear stress estimate: $\tau(x)=|V(x)|/A_{shear}(x)$ with $A_{shear}(x)=[1-r(x)]2t\,h_{clear}(x)$ for the active orientation
- von Mises stress: $\sigma_{vm}(x)=\sqrt{\sigma_b(x)^2+3\tau(x)^2}$
- Factor of safety: $FoS(x)=\sigma_{allow,eff}/\sigma_{vm}(x)$

### Deflection and Objective

- Euler-Bernoulli relation: $E_{eff}I(x)v''(x)=M(x)$
- Weight objective: $W=\rho\int_0^L A(x)\,dx$
- Search objective used here: minimize weight while enforcing factor-of-safety and optional deflection constraints

## Automatic Equation Substitution

### Effective Material Properties

- $E_{eff} = E \times k_{orientation} \times k_{infill} = 500000.0 \times 0.700 \times 0.850 = 297500.0\ \text{psi}$
- $\sigma_{allow,eff} = \sigma_{allow} \times k_{orientation} \times k_{infill} = 4000.0 \times 0.700 \times 0.850 = 2380.0\ \text{psi}$
- $W = \rho \int_0^L A(x)\,dx = 0.02779\ \text{lbf}$
- Global governing factor of safety is the minimum value over all beam stations and over both load cases.

### Load Case 1

- Active bending orientation: upright (upright section properties)
- $R_A = P(L-a)/L = 5.000(8.000-4.000)/8.000 = 2.500\ \text{lbf}$
- $R_B = Pa/L = 5.000(4.000)/8.000 = 2.500\ \text{lbf}$
- $FoS_{min} = \sigma_{allow,eff}/\sigma_{vm,max} = 2380.0/1542.0 = 1.543$
- Governing location for this load case: $x = 4.000\ \text{in}$
- $\max |v(x)| = 0.09024\ \text{in}$
- $\max |\theta(x)| = 0.035148\ \text{rad}$

### Load Case 2

- Active bending orientation: side (side-rotated section properties)
- $R_A = P(L-a)/L = 3.000(8.000-2.500)/8.000 = 2.062\ \text{lbf}$
- $R_B = Pa/L = 3.000(2.500)/8.000 = 0.938\ \text{lbf}$
- $FoS_{min} = \sigma_{allow,eff}/\sigma_{vm,max} = 2380.0/704.3 = 3.379$
- Governing location for this load case: $x = 2.490\ \text{in}$
- $\max |v(x)| = 0.05877\ \text{in}$
- $\max |\theta(x)| = 0.024872\ \text{rad}$

## Automatic Trail of Tried Designs

- Full design study table: `design_study.csv`
- Best design record: `best_design.json`
- Best-design plots folder: `best_design/`

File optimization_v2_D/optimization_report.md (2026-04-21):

# Beam Optimization Report

## Search Summary

- Search method: stratified global sampling with elite local refinement
- Total evaluated designs: 760
- Feasible designs found: 531
- Minimum required factor of safety: 1.500
- Objective shaping: penalize excess FoS margin and underutilized stress envelope so the design approaches the 1.5 target more closely
- Maximum allowed deflection: not enforced in this run
- Random seed: 1618

## Best Design

- Weight: 0.04946 lbf
- Minimum factor of safety: 1.670
- Excess FoS above target: 0.170
- Governing minimum-FoS load case: Load Case 1 at x = 4.000 in
- Maximum deflection: 0.04698 in
- Constraint status: feasible

### Geometry Variables

| Variable | Value |
| --- | ---: |
| $L$ [in] | 8.000 |
| $L_{total}$ [in] | 9.000 |
| $b_L$ [in] | 0.932 |
| $b_M$ [in] | 0.350 |
| $b_R$ [in] | 1.182 |
| $h_L$ [in] | 1.300 |
| $h_M$ [in] | 0.380 |
| $h_R$ [in] | 1.176 |
| $t$ [in] | 0.068 |
| $r_L$ [-] | 0.782 |
| $r_M$ [-] | 0.191 |
| $r_R$ [-] | 0.777 |
| $E_{eff}$ [psi] | 297500.0 |
| $\sigma_{allow,eff}$ [psi] | 2380.0 |

### Best-Design Load-Case Metrics

| Load Case | Orientation | Load [lbf] | Location [in] | Min FoS | FoS x [in] | Max Deflection [in] | Max von Mises [psi] |
| --- | --- | ---: | ---: | ---: | ---: | ---: | ---: |
| Load Case 1 | upright | 5.000 | 4.000 | 1.670 | 4.000 | 0.04698 | 1425.3 |
| Load Case 2 | side | 3.000 | 2.500 | 4.172 | 4.000 | 0.02499 | 570.5 |

## Beam Structure and Parameters

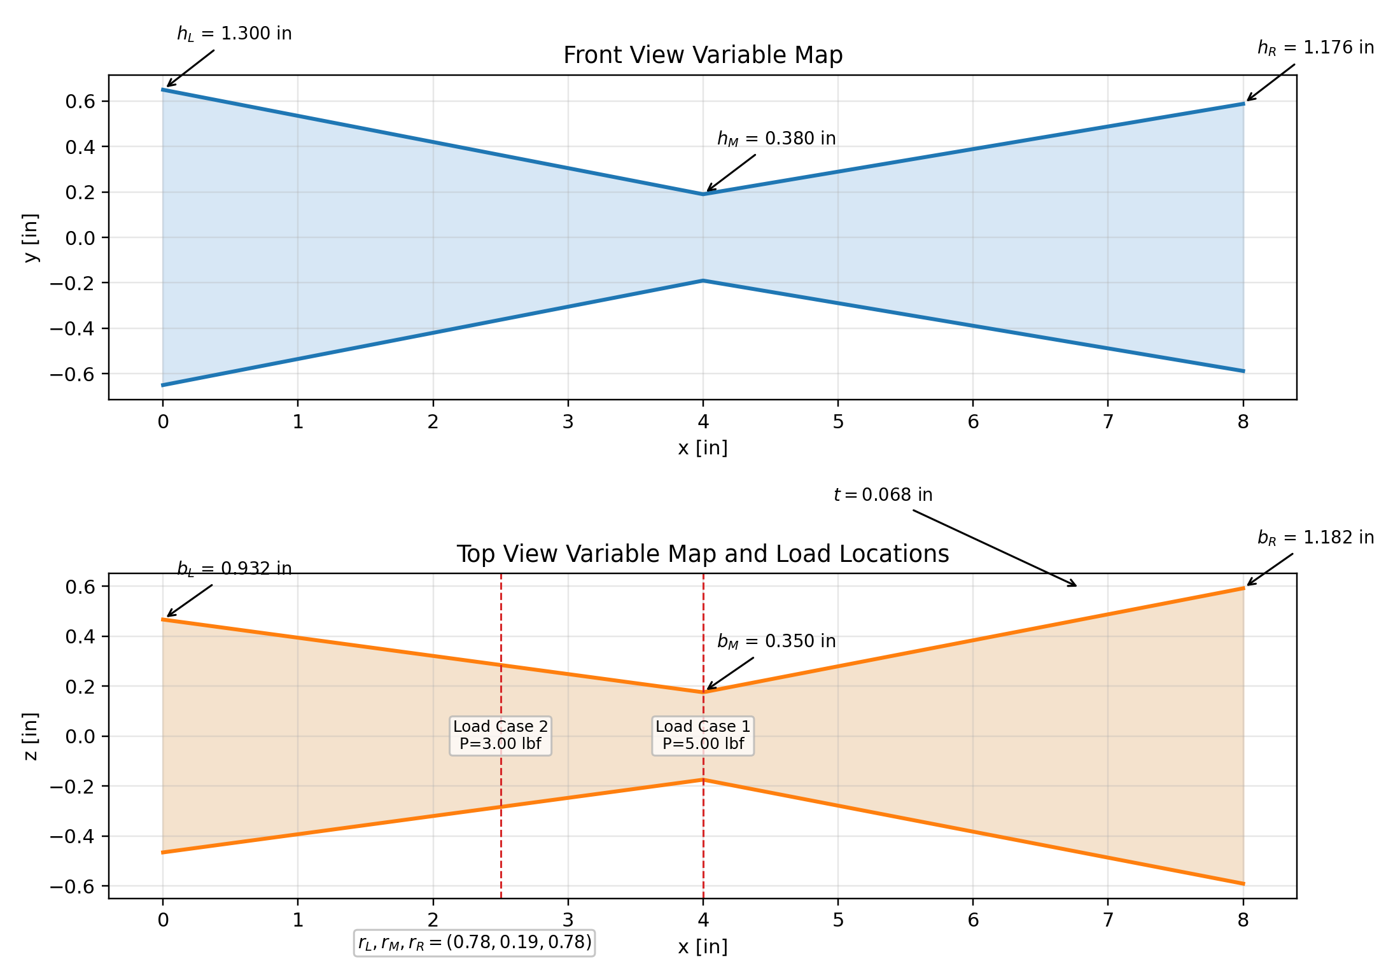
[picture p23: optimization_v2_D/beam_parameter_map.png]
Beam parameter map


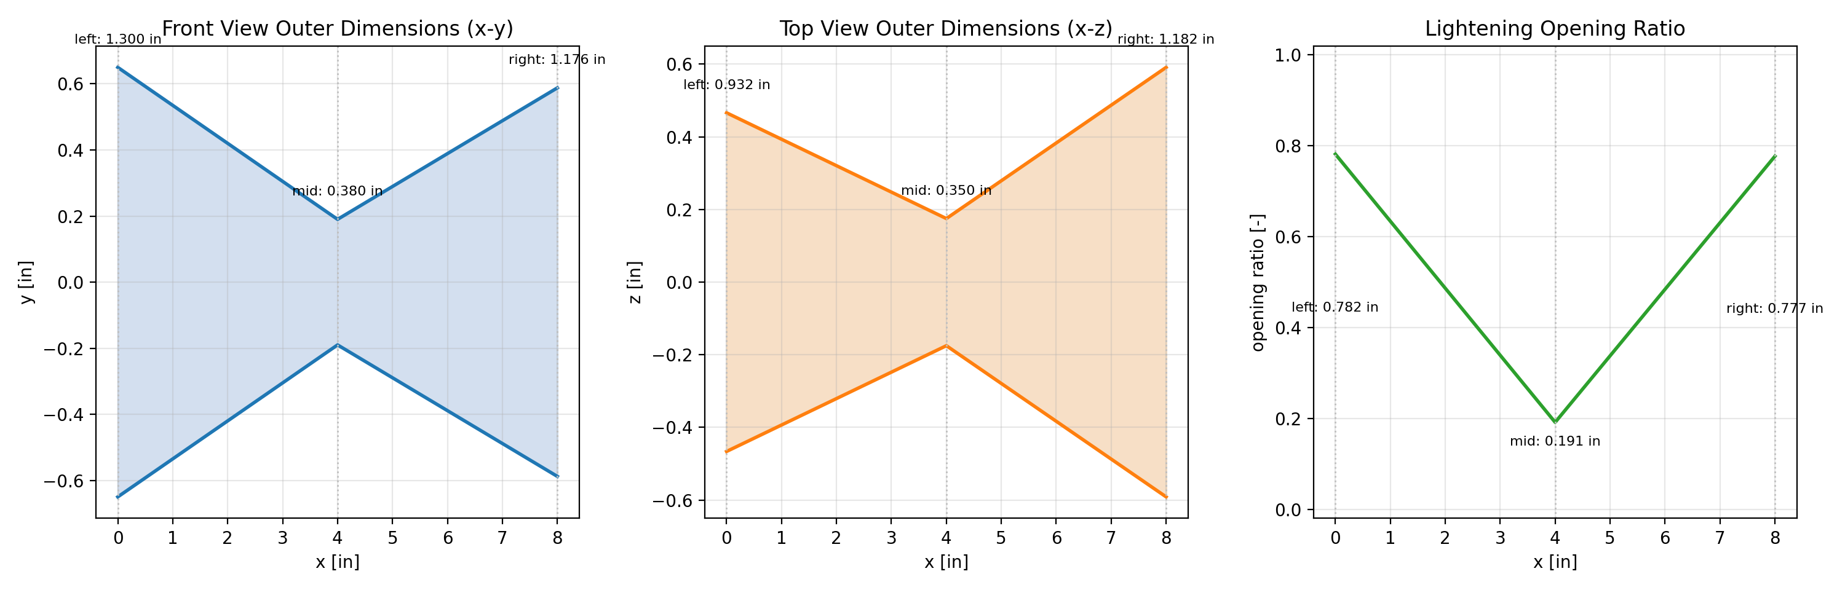
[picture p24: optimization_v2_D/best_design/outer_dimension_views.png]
Outer dimension views


## General Equations

### Geometry

- $$b(x)=\begin{cases}0.9323 + (-0.1456)x, & 0 \le x \le 4.0000\\0.3500 + (0.2081)(x-4.0000), & 4.0000 < x \le 8.0000\end{cases}$$
- $$h(x)=\begin{cases}1.3000 + (-0.2300)x, & 0 \le x \le 4.0000\\0.3800 + (0.1990)(x-4.0000), & 4.0000 < x \le 8.0000\end{cases}$$
- $$r(x)=\begin{cases}0.7817 + (-0.1476)x, & 0 \le x \le 4.0000\\0.1914 + (0.1464)(x-4.0000), & 4.0000 < x \le 8.0000\end{cases}$$
- Hollow tube area with lightening openings: $A(x)=2b(x)t + [1-r(x)]2t[h(x)-2t]$
- Upright bending second moment: $I(x)=\frac{b(x)h(x)^3-[b(x)-2t][h(x)-2t]^3}{12}-2\frac{t[r(x)(h(x)-2t)]^3}{12}$
- Side-rotated bending second moment: $I_{side}(x)=\frac{h(x)b(x)^3-[h(x)-2t][b(x)-2t]^3}{12}-2\frac{t[r(x)(b(x)-2t)]^3}{12}$
- Section modulus: $S(x)=I(x)/c(x)$ with $c(x)=\text{outer vertical dimension}/2$

### Statics and Stress

- Reactions for a point load $P$ at $x=a$: $R_A=P(L-a)/L$, $R_B=Pa/L$
- Shear and moment: $V(x)$ and $M(x)$ are computed piecewise from the reactions and applied load
- Bending stress: $\sigma_b(x)=|M(x)|/S(x)$
- Shear stress estimate: $\tau(x)=|V(x)|/A_{shear}(x)$ with $A_{shear}(x)=[1-r(x)]2t\,h_{clear}(x)$ for the active orientation
- von Mises stress: $\sigma_{vm}(x)=\sqrt{\sigma_b(x)^2+3\tau(x)^2}$
- Factor of safety: $FoS(x)=\sigma_{allow,eff}/\sigma_{vm}(x)$

### Deflection and Objective

- Euler-Bernoulli relation: $E_{eff}I(x)v''(x)=M(x)$
- Weight objective: $W=\rho\int_0^L A(x)\,dx$
- Search objective used here: minimize weight while enforcing factor-of-safety and optional deflection constraints

## Automatic Equation Substitution

### Effective Material Properties

- $E_{eff} = E \times k_{orientation} \times k_{infill} = 500000.0 \times 0.700 \times 0.850 = 297500.0\ \text{psi}$
- $\sigma_{allow,eff} = \sigma_{allow} \times k_{orientation} \times k_{infill} = 4000.0 \times 0.700 \times 0.850 = 2380.0\ \text{psi}$
- $W = \rho \int_0^L A(x)\,dx = 0.04946\ \text{lbf}$
- Global governing factor of safety is the minimum value over all beam stations and over both load cases.

### Load Case 1

- Active bending orientation: upright (upright section properties)
- $R_A = P(L-a)/L = 5.000(8.000-4.000)/8.000 = 2.500\ \text{lbf}$
- $R_B = Pa/L = 5.000(4.000)/8.000 = 2.500\ \text{lbf}$
- $FoS_{min} = \sigma_{allow,eff}/\sigma_{vm,max} = 2380.0/1425.3 = 1.670$
- Governing location for this load case: $x = 4.000\ \text{in}$
- $\max |v(x)| = 0.04698\ \text{in}$
- $\max |\theta(x)| = 0.013956\ \text{rad}$

### Load Case 2

- Active bending orientation: side (side-rotated section properties)
- $R_A = P(L-a)/L = 3.000(8.000-2.500)/8.000 = 2.062\ \text{lbf}$
- $R_B = Pa/L = 3.000(2.500)/8.000 = 0.938\ \text{lbf}$
- $FoS_{min} = \sigma_{allow,eff}/\sigma_{vm,max} = 2380.0/570.5 = 4.172$
- Governing location for this load case: $x = 4.000\ \text{in}$
- $\max |v(x)| = 0.02499\ \text{in}$
- $\max |\theta(x)| = 0.008266\ \text{rad}$

## Automatic Trail of Tried Designs

- Full design study table: `design_study.csv`
- Best design record: `best_design.json`
- Best-design plots folder: `best_design/`

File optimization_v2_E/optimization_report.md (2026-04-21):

# Beam Optimization Report

## Search Summary

- Search method: stratified global sampling with elite local refinement
- Total evaluated designs: 1040
- Feasible designs found: 753
- Minimum required factor of safety: 1.500
- Objective shaping: penalize excess FoS margin and underutilized stress envelope so the design approaches the 1.5 target more closely
- Maximum allowed deflection: not enforced in this run
- Random seed: 2718

## Best Design

- Weight: 0.02939 lbf
- Minimum factor of safety: 1.588
- Excess FoS above target: 0.088
- Governing minimum-FoS load case: Load Case 1 at x = 4.000 in
- Maximum deflection: 0.11822 in
- Constraint status: feasible

### Geometry Variables

| Variable | Value |
| --- | ---: |
| $L$ [in] | 8.000 |
| $L_{total}$ [in] | 9.000 |
| $b_L$ [in] | 0.350 |
| $b_M$ [in] | 0.353 |
| $b_R$ [in] | 0.527 |
| $h_L$ [in] | 0.399 |
| $h_M$ [in] | 0.380 |
| $h_R$ [in] | 0.567 |
| $t$ [in] | 0.060 |
| $r_L$ [-] | 0.331 |
| $r_M$ [-] | 0.031 |
| $r_R$ [-] | 0.000 |
| $E_{eff}$ [psi] | 297500.0 |
| $\sigma_{allow,eff}$ [psi] | 2380.0 |

### Best-Design Load-Case Metrics

| Load Case | Orientation | Load [lbf] | Location [in] | Min FoS | FoS x [in] | Max Deflection [in] | Max von Mises [psi] |
| --- | --- | ---: | ---: | ---: | ---: | ---: | ---: |
| Load Case 1 | upright | 5.000 | 4.000 | 1.588 | 4.000 | 0.11822 | 1498.8 |
| Load Case 2 | side | 3.000 | 2.500 | 2.922 | 2.490 | 0.07100 | 814.5 |

## Beam Structure and Parameters

Beam parameter map

Outer dimension views

## General Equations

### Geometry

- $$b(x)=\begin{cases}0.3500 + (0.0008)x, & 0 \le x \le 4.0000\\0.3532 + (0.0433)(x-4.0000), & 4.0000 < x \le 8.0000\end{cases}$$
- $$h(x)=\begin{cases}0.3993 + (-0.0048)x, & 0 \le x \le 4.0000\\0.3800 + (0.0468)(x-4.0000), & 4.0000 < x \le 8.0000\end{cases}$$
- $$r(x)=\begin{cases}0.3310 + (-0.0751)x, & 0 \le x \le 4.0000\\0.0305 + (-0.0076)(x-4.0000), & 4.0000 < x \le 8.0000\end{cases}$$
- Hollow tube area with lightening openings: $A(x)=2b(x)t + [1-r(x)]2t[h(x)-2t]$
- Upright bending second moment: $I(x)=\frac{b(x)h(x)^3-[b(x)-2t][h(x)-2t]^3}{12}-2\frac{t[r(x)(h(x)-2t)]^3}{12}$
- Side-rotated bending second moment: $I_{side}(x)=\frac{h(x)b(x)^3-[h(x)-2t][b(x)-2t]^3}{12}-2\frac{t[r(x)(b(x)-2t)]^3}{12}$
- Section modulus: $S(x)=I(x)/c(x)$ with $c(x)=\text{outer vertical dimension}/2$

### Statics and Stress

- Reactions for a point load $P$ at $x=a$: $R_A=P(L-a)/L$, $R_B=Pa/L$
- Shear and moment: $V(x)$ and $M(x)$ are computed piecewise from the reactions and applied load
- Bending stress: $\sigma_b(x)=|M(x)|/S(x)$
- Shear stress estimate: $\tau(x)=|V(x)|/A_{shear}(x)$ with $A_{shear}(x)=[1-r(x)]2t\,h_{clear}(x)$ for the active orientation
- von Mises stress: $\sigma_{vm}(x)=\sqrt{\sigma_b(x)^2+3\tau(x)^2}$
- Factor of safety: $FoS(x)=\sigma_{allow,eff}/\sigma_{vm}(x)$

### Deflection and Objective

- Euler-Bernoulli relation: $E_{eff}I(x)v''(x)=M(x)$
- Weight objective: $W=\rho\int_0^L A(x)\,dx$
- Search objective used here: minimize weight while enforcing factor-of-safety and optional deflection constraints

## Automatic Equation Substitution

### Effective Material Properties

- $E_{eff} = E \times k_{orientation} \times k_{infill} = 500000.0 \times 0.700 \times 0.850 = 297500.0\ \text{psi}$
- $\sigma_{allow,eff} = \sigma_{allow} \times k_{orientation} \times k_{infill} = 4000.0 \times 0.700 \times 0.850 = 2380.0\ \text{psi}$
- $W = \rho \int_0^L A(x)\,dx = 0.02939\ \text{lbf}$
- Global governing factor of safety is the minimum value over all beam stations and over both load cases.

### Load Case 1

- Active bending orientation: upright (upright section properties)
- $R_A = P(L-a)/L = 5.000(8.000-4.000)/8.000 = 2.500\ \text{lbf}$
- $R_B = Pa/L = 5.000(4.000)/8.000 = 2.500\ \text{lbf}$
- $FoS_{min} = \sigma_{allow,eff}/\sigma_{vm,max} = 2380.0/1498.8 = 1.588$
- Governing location for this load case: $x = 4.000\ \text{in}$
- $\max |v(x)| = 0.11822\ \text{in}$
- $\max |\theta(x)| = 0.046017\ \text{rad}$

### Load Case 2

- Active bending orientation: side (side-rotated section properties)
- $R_A = P(L-a)/L = 3.000(8.000-2.500)/8.000 = 2.062\ \text{lbf}$
- $R_B = Pa/L = 3.000(2.500)/8.000 = 0.938\ \text{lbf}$
- $FoS_{min} = \sigma_{allow,eff}/\sigma_{vm,max} = 2380.0/814.5 = 2.922$
- Governing location for this load case: $x = 2.490\ \text{in}$
- $\max |v(x)| = 0.07100\ \text{in}$
- $\max |\theta(x)| = 0.032354\ \text{rad}$

## Automatic Trail of Tried Designs

- Full design study table: `design_study.csv`
- Best design record: `best_design.json`
- Best-design plots folder: `best_design/`

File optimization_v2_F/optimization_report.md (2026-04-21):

# Beam Optimization Report

## Search Summary

- Search method: stratified global sampling with elite local refinement
- Total evaluated designs: 1040
- Feasible designs found: 620
- Minimum required factor of safety: 1.500
- Objective shaping: penalize excess FoS margin and underutilized stress envelope so the design approaches the 1.5 target more closely
- Maximum allowed deflection: not enforced in this run
- Random seed: 42

## Best Design

- Weight: 0.03270 lbf
- Minimum factor of safety: 1.564
- Excess FoS above target: 0.064
- Governing minimum-FoS load case: Load Case 1 at x = 4.000 in
- Maximum deflection: 0.09030 in
- Constraint status: feasible

### Geometry Variables

| Variable | Value |
| --- | ---: |
| $L$ [in] | 8.000 |
| $L_{total}$ [in] | 9.000 |
| $b_L$ [in] | 0.350 |
| $b_M$ [in] | 0.350 |
| $b_R$ [in] | 0.737 |
| $h_L$ [in] | 0.743 |
| $h_M$ [in] | 0.380 |
| $h_R$ [in] | 0.574 |
| $t$ [in] | 0.060 |
| $r_L$ [-] | 0.120 |
| $r_M$ [-] | 0.291 |
| $r_R$ [-] | 0.233 |
| $E_{eff}$ [psi] | 297500.0 |
| $\sigma_{allow,eff}$ [psi] | 2380.0 |

### Best-Design Load-Case Metrics

| Load Case | Orientation | Load [lbf] | Location [in] | Min FoS | FoS x [in] | Max Deflection [in] | Max von Mises [psi] |
| --- | --- | ---: | ---: | ---: | ---: | ---: | ---: |
| Load Case 1 | upright | 5.000 | 4.000 | 1.564 | 4.000 | 0.09030 | 1521.5 |
| Load Case 2 | side | 3.000 | 2.500 | 3.691 | 2.490 | 0.05868 | 644.9 |

## Beam Structure and Parameters

Beam parameter map

Outer dimension views

## General Equations

### Geometry

- $$b(x)=\begin{cases}0.3500 + (0.0000)x, & 0 \le x \le 4.0000\\0.3500 + (0.0968)(x-4.0000), & 4.0000 < x \le 8.0000\end{cases}$$
- $$h(x)=\begin{cases}0.7428 + (-0.0907)x, & 0 \le x \le 4.0000\\0.3800 + (0.0485)(x-4.0000), & 4.0000 < x \le 8.0000\end{cases}$$
- $$r(x)=\begin{cases}0.1199 + (0.0427)x, & 0 \le x \le 4.0000\\0.2909 + (-0.0144)(x-4.0000), & 4.0000 < x \le 8.0000\end{cases}$$
- Hollow tube area with lightening openings: $A(x)=2b(x)t + [1-r(x)]2t[h(x)-2t]$
- Upright bending second moment: $I(x)=\frac{b(x)h(x)^3-[b(x)-2t][h(x)-2t]^3}{12}-2\frac{t[r(x)(h(x)-2t)]^3}{12}$
- Side-rotated bending second moment: $I_{side}(x)=\frac{h(x)b(x)^3-[h(x)-2t][b(x)-2t]^3}{12}-2\frac{t[r(x)(b(x)-2t)]^3}{12}$
- Section modulus: $S(x)=I(x)/c(x)$ with $c(x)=\text{outer vertical dimension}/2$

### Statics and Stress

- Reactions for a point load $P$ at $x=a$: $R_A=P(L-a)/L$, $R_B=Pa/L$
- Shear and moment: $V(x)$ and $M(x)$ are computed piecewise from the reactions and applied load
- Bending stress: $\sigma_b(x)=|M(x)|/S(x)$
- Shear stress estimate: $\tau(x)=|V(x)|/A_{shear}(x)$ with $A_{shear}(x)=[1-r(x)]2t\,h_{clear}(x)$ for the active orientation
- von Mises stress: $\sigma_{vm}(x)=\sqrt{\sigma_b(x)^2+3\tau(x)^2}$
- Factor of safety: $FoS(x)=\sigma_{allow,eff}/\sigma_{vm}(x)$

### Deflection and Objective

- Euler-Bernoulli relation: $E_{eff}I(x)v''(x)=M(x)$
- Weight objective: $W=\rho\int_0^L A(x)\,dx$
- Search objective used here: minimize weight while enforcing factor-of-safety and optional deflection constraints

## Automatic Equation Substitution

### Effective Material Properties

- $E_{eff} = E \times k_{orientation} \times k_{infill} = 500000.0 \times 0.700 \times 0.850 = 297500.0\ \text{psi}$
- $\sigma_{allow,eff} = \sigma_{allow} \times k_{orientation} \times k_{infill} = 4000.0 \times 0.700 \times 0.850 = 2380.0\ \text{psi}$
- $W = \rho \int_0^L A(x)\,dx = 0.03270\ \text{lbf}$
- Global governing factor of safety is the minimum value over all beam stations and over both load cases.

### Load Case 1

- Active bending orientation: upright (upright section properties)
- $R_A = P(L-a)/L = 5.000(8.000-4.000)/8.000 = 2.500\ \text{lbf}$
- $R_B = Pa/L = 5.000(4.000)/8.000 = 2.500\ \text{lbf}$
- $FoS_{min} = \sigma_{allow,eff}/\sigma_{vm,max} = 2380.0/1521.5 = 1.564$
- Governing location for this load case: $x = 4.000\ \text{in}$
- $\max |v(x)| = 0.09030\ \text{in}$
- $\max |\theta(x)| = 0.030029\ \text{rad}$

### Load Case 2

- Active bending orientation: side (side-rotated section properties)
- $R_A = P(L-a)/L = 3.000(8.000-2.500)/8.000 = 2.062\ \text{lbf}$
- $R_B = Pa/L = 3.000(2.500)/8.000 = 0.938\ \text{lbf}$
- $FoS_{min} = \sigma_{allow,eff}/\sigma_{vm,max} = 2380.0/644.9 = 3.691$
- Governing location for this load case: $x = 2.490\ \text{in}$
- $\max |v(x)| = 0.05868\ \text{in}$
- $\max |\theta(x)| = 0.025279\ \text{rad}$

## Automatic Trail of Tried Designs

- Full design study table: `design_study.csv`
- Best design record: `best_design.json`
- Best-design plots folder: `best_design/`

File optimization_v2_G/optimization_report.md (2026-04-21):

# Beam Optimization Report

## Search Summary

- Search method: stratified global sampling with elite local refinement
- Total evaluated designs: 1200
- Feasible designs found: 713
- Minimum required factor of safety: 1.500
- Objective shaping: penalize excess FoS margin and underutilized stress envelope so the design approaches the 1.5 target more closely
- Maximum allowed deflection: not enforced in this run
- Random seed: 9999

## Best Design

- Weight: 0.02690 lbf
- Minimum factor of safety: 1.551
- Excess FoS above target: 0.051
- Governing minimum-FoS load case: Load Case 1 at x = 4.000 in
- Maximum deflection: 0.08463 in
- Constraint status: feasible

### Geometry Variables

| Variable | Value |
| --- | ---: |
| $L$ [in] | 8.000 |
| $L_{total}$ [in] | 9.000 |
| $b_L$ [in] | 0.350 |
| $b_M$ [in] | 0.350 |
| $b_R$ [in] | 0.512 |
| $h_L$ [in] | 0.809 |
| $h_M$ [in] | 0.380 |
| $h_R$ [in] | 0.741 |
| $t$ [in] | 0.060 |
| $r_L$ [-] | 0.687 |
| $r_M$ [-] | 0.397 |
| $r_R$ [-] | 0.429 |
| $E_{eff}$ [psi] | 297500.0 |
| $\sigma_{allow,eff}$ [psi] | 2380.0 |

### Best-Design Load-Case Metrics

| Load Case | Orientation | Load [lbf] | Location [in] | Min FoS | FoS x [in] | Max Deflection [in] | Max von Mises [psi] |
| --- | --- | ---: | ---: | ---: | ---: | ---: | ---: |
| Load Case 1 | upright | 5.000 | 4.000 | 1.551 | 4.000 | 0.08463 | 1534.3 |
| Load Case 2 | side | 3.000 | 2.500 | 3.624 | 2.490 | 0.06085 | 656.7 |

## Beam Structure and Parameters

Beam parameter map

Outer dimension views

## General Equations

### Geometry

- $$b(x)=\begin{cases}0.3500 + (0.0000)x, & 0 \le x \le 4.0000\\0.3500 + (0.0405)(x-4.0000), & 4.0000 < x \le 8.0000\end{cases}$$
- $$h(x)=\begin{cases}0.8089 + (-0.1072)x, & 0 \le x \le 4.0000\\0.3800 + (0.0902)(x-4.0000), & 4.0000 < x \le 8.0000\end{cases}$$
- $$r(x)=\begin{cases}0.6868 + (-0.0724)x, & 0 \le x \le 4.0000\\0.3971 + (0.0080)(x-4.0000), & 4.0000 < x \le 8.0000\end{cases}$$
- Hollow tube area with lightening openings: $A(x)=2b(x)t + [1-r(x)]2t[h(x)-2t]$
- Upright bending second moment: $I(x)=\frac{b(x)h(x)^3-[b(x)-2t][h(x)-2t]^3}{12}-2\frac{t[r(x)(h(x)-2t)]^3}{12}$
- Side-rotated bending second moment: $I_{side}(x)=\frac{h(x)b(x)^3-[h(x)-2t][b(x)-2t]^3}{12}-2\frac{t[r(x)(b(x)-2t)]^3}{12}$
- Section modulus: $S(x)=I(x)/c(x)$ with $c(x)=\text{outer vertical dimension}/2$

### Statics and Stress

- Reactions for a point load $P$ at $x=a$: $R_A=P(L-a)/L$, $R_B=Pa/L$
- Shear and moment: $V(x)$ and $M(x)$ are computed piecewise from the reactions and applied load
- Bending stress: $\sigma_b(x)=|M(x)|/S(x)$
- Shear stress estimate: $\tau(x)=|V(x)|/A_{shear}(x)$ with $A_{shear}(x)=[1-r(x)]2t\,h_{clear}(x)$ for the active orientation
- von Mises stress: $\sigma_{vm}(x)=\sqrt{\sigma_b(x)^2+3\tau(x)^2}$
- Factor of safety: $FoS(x)=\sigma_{allow,eff}/\sigma_{vm}(x)$

### Deflection and Objective

- Euler-Bernoulli relation: $E_{eff}I(x)v''(x)=M(x)$
- Weight objective: $W=\rho\int_0^L A(x)\,dx$
- Search objective used here: minimize weight while enforcing factor-of-safety and optional deflection constraints

## Automatic Equation Substitution

### Effective Material Properties

- $E_{eff} = E \times k_{orientation} \times k_{infill} = 500000.0 \times 0.700 \times 0.850 = 297500.0\ \text{psi}$
- $\sigma_{allow,eff} = \sigma_{allow} \times k_{orientation} \times k_{infill} = 4000.0 \times 0.700 \times 0.850 = 2380.0\ \text{psi}$
- $W = \rho \int_0^L A(x)\,dx = 0.02690\ \text{lbf}$
- Global governing factor of safety is the minimum value over all beam stations and over both load cases.

### Load Case 1

- Active bending orientation: upright (upright section properties)
- $R_A = P(L-a)/L = 5.000(8.000-4.000)/8.000 = 2.500\ \text{lbf}$
- $R_B = Pa/L = 5.000(4.000)/8.000 = 2.500\ \text{lbf}$
- $FoS_{min} = \sigma_{allow,eff}/\sigma_{vm,max} = 2380.0/1534.3 = 1.551$
- Governing location for this load case: $x = 4.000\ \text{in}$
- $\max |v(x)| = 0.08463\ \text{in}$
- $\max |\theta(x)| = 0.027657\ \text{rad}$

### Load Case 2

- Active bending orientation: side (side-rotated section properties)
- $R_A = P(L-a)/L = 3.000(8.000-2.500)/8.000 = 2.062\ \text{lbf}$
- $R_B = Pa/L = 3.000(2.500)/8.000 = 0.938\ \text{lbf}$
- $FoS_{min} = \sigma_{allow,eff}/\sigma_{vm,max} = 2380.0/656.7 = 3.624$
- Governing location for this load case: $x = 2.490\ \text{in}$
- $\max |v(x)| = 0.06085\ \text{in}$
- $\max |\theta(x)| = 0.025524\ \text{rad}$

## Automatic Trail of Tried Designs

- Full design study table: `design_study.csv`
- Best design record: `best_design.json`
- Best-design plots folder: `best_design/`

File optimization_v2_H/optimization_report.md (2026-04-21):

# Beam Optimization Report

## Search Summary

- Search method: stratified global sampling with elite local refinement
- Total evaluated designs: 1200
- Feasible designs found: 804
- Minimum required factor of safety: 1.500
- Objective shaping: penalize excess FoS margin and underutilized stress envelope so the design approaches the 1.5 target more closely
- Maximum allowed deflection: not enforced in this run
- Random seed: 31415

## Best Design

- Weight: 0.04285 lbf
- Minimum factor of safety: 1.550
- Excess FoS above target: 0.050
- Governing minimum-FoS load case: Load Case 1 at x = 4.000 in
- Maximum deflection: 0.06029 in
- Constraint status: feasible

### Geometry Variables

| Variable | Value |
| --- | ---: |
| $L$ [in] | 8.000 |
| $L_{total}$ [in] | 9.000 |
| $b_L$ [in] | 0.938 |
| $b_M$ [in] | 0.350 |
| $b_R$ [in] | 0.350 |
| $h_L$ [in] | 1.029 |
| $h_M$ [in] | 0.380 |
| $h_R$ [in] | 1.211 |
| $t$ [in] | 0.060 |
| $r_L$ [-] | 0.190 |
| $r_M$ [-] | 0.404 |
| $r_R$ [-] | 0.000 |
| $E_{eff}$ [psi] | 297500.0 |
| $\sigma_{allow,eff}$ [psi] | 2380.0 |

### Best-Design Load-Case Metrics

| Load Case | Orientation | Load [lbf] | Location [in] | Min FoS | FoS x [in] | Max Deflection [in] | Max von Mises [psi] |
| --- | --- | ---: | ---: | ---: | ---: | ---: | ---: |
| Load Case 1 | upright | 5.000 | 4.000 | 1.550 | 4.000 | 0.06029 | 1535.4 |
| Load Case 2 | side | 3.000 | 2.500 | 3.887 | 4.000 | 0.03934 | 612.3 |

## Beam Structure and Parameters

Beam parameter map

Outer dimension views

## General Equations

### Geometry

- $$b(x)=\begin{cases}0.9383 + (-0.1471)x, & 0 \le x \le 4.0000\\0.3500 + (0.0000)(x-4.0000), & 4.0000 < x \le 8.0000\end{cases}$$
- $$h(x)=\begin{cases}1.0291 + (-0.1623)x, & 0 \le x \le 4.0000\\0.3800 + (0.2078)(x-4.0000), & 4.0000 < x \le 8.0000\end{cases}$$
- $$r(x)=\begin{cases}0.1897 + (0.0536)x, & 0 \le x \le 4.0000\\0.4042 + (-0.1011)(x-4.0000), & 4.0000 < x \le 8.0000\end{cases}$$
- Hollow tube area with lightening openings: $A(x)=2b(x)t + [1-r(x)]2t[h(x)-2t]$
- Upright bending second moment: $I(x)=\frac{b(x)h(x)^3-[b(x)-2t][h(x)-2t]^3}{12}-2\frac{t[r(x)(h(x)-2t)]^3}{12}$
- Side-rotated bending second moment: $I_{side}(x)=\frac{h(x)b(x)^3-[h(x)-2t][b(x)-2t]^3}{12}-2\frac{t[r(x)(b(x)-2t)]^3}{12}$
- Section modulus: $S(x)=I(x)/c(x)$ with $c(x)=\text{outer vertical dimension}/2$

### Statics and Stress

- Reactions for a point load $P$ at $x=a$: $R_A=P(L-a)/L$, $R_B=Pa/L$
- Shear and moment: $V(x)$ and $M(x)$ are computed piecewise from the reactions and applied load
- Bending stress: $\sigma_b(x)=|M(x)|/S(x)$
- Shear stress estimate: $\tau(x)=|V(x)|/A_{shear}(x)$ with $A_{shear}(x)=[1-r(x)]2t\,h_{clear}(x)$ for the active orientation
- von Mises stress: $\sigma_{vm}(x)=\sqrt{\sigma_b(x)^2+3\tau(x)^2}$
- Factor of safety: $FoS(x)=\sigma_{allow,eff}/\sigma_{vm}(x)$

### Deflection and Objective

- Euler-Bernoulli relation: $E_{eff}I(x)v''(x)=M(x)$
- Weight objective: $W=\rho\int_0^L A(x)\,dx$
- Search objective used here: minimize weight while enforcing factor-of-safety and optional deflection constraints

## Automatic Equation Substitution

### Effective Material Properties

- $E_{eff} = E \times k_{orientation} \times k_{infill} = 500000.0 \times 0.700 \times 0.850 = 297500.0\ \text{psi}$
- $\sigma_{allow,eff} = \sigma_{allow} \times k_{orientation} \times k_{infill} = 4000.0 \times 0.700 \times 0.850 = 2380.0\ \text{psi}$
- $W = \rho \int_0^L A(x)\,dx = 0.04285\ \text{lbf}$
- Global governing factor of safety is the minimum value over all beam stations and over both load cases.

### Load Case 1

- Active bending orientation: upright (upright section properties)
- $R_A = P(L-a)/L = 5.000(8.000-4.000)/8.000 = 2.500\ \text{lbf}$
- $R_B = Pa/L = 5.000(4.000)/8.000 = 2.500\ \text{lbf}$
- $FoS_{min} = \sigma_{allow,eff}/\sigma_{vm,max} = 2380.0/1535.4 = 1.550$
- Governing location for this load case: $x = 4.000\ \text{in}$
- $\max |v(x)| = 0.06029\ \text{in}$
- $\max |\theta(x)| = 0.018530\ \text{rad}$

### Load Case 2

- Active bending orientation: side (side-rotated section properties)
- $R_A = P(L-a)/L = 3.000(8.000-2.500)/8.000 = 2.062\ \text{lbf}$
- $R_B = Pa/L = 3.000(2.500)/8.000 = 0.938\ \text{lbf}$
- $FoS_{min} = \sigma_{allow,eff}/\sigma_{vm,max} = 2380.0/612.3 = 3.887$
- Governing location for this load case: $x = 4.000\ \text{in}$
- $\max |v(x)| = 0.03934\ \text{in}$
- $\max |\theta(x)| = 0.013931\ \text{rad}$

## Automatic Trail of Tried Designs

- Full design study table: `design_study.csv`
- Best design record: `best_design.json`
- Best-design plots folder: `best_design/`

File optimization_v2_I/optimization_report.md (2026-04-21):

# Beam Optimization Report

## Search Summary

- Search method: stratified global sampling with elite local refinement
- Total evaluated designs: 1200
- Feasible designs found: 773
- Minimum required factor of safety: 1.500
- Objective shaping: penalize excess FoS margin and underutilized stress envelope so the design approaches the 1.5 target more closely
- Maximum allowed deflection: not enforced in this run
- Random seed: 27182

## Best Design

- Weight: 0.03578 lbf
- Minimum factor of safety: 1.564
- Excess FoS above target: 0.064
- Governing minimum-FoS load case: Load Case 1 at x = 4.000 in
- Maximum deflection: 0.09504 in
- Constraint status: feasible

### Geometry Variables

| Variable | Value |
| --- | ---: |
| $L$ [in] | 8.000 |
| $L_{total}$ [in] | 9.000 |
| $b_L$ [in] | 0.975 |
| $b_M$ [in] | 0.350 |
| $b_R$ [in] | 0.640 |
| $h_L$ [in] | 0.577 |
| $h_M$ [in] | 0.380 |
| $h_R$ [in] | 0.486 |
| $t$ [in] | 0.060 |
| $r_L$ [-] | 0.156 |
| $r_M$ [-] | 0.292 |
| $r_R$ [-] | 0.313 |
| $E_{eff}$ [psi] | 297500.0 |
| $\sigma_{allow,eff}$ [psi] | 2380.0 |

### Best-Design Load-Case Metrics

| Load Case | Orientation | Load [lbf] | Location [in] | Min FoS | FoS x [in] | Max Deflection [in] | Max von Mises [psi] |
| --- | --- | ---: | ---: | ---: | ---: | ---: | ---: |
| Load Case 1 | upright | 5.000 | 4.000 | 1.564 | 4.000 | 0.09504 | 1521.6 |
| Load Case 2 | side | 3.000 | 2.500 | 3.920 | 4.000 | 0.03857 | 607.2 |

## Beam Structure and Parameters

Beam parameter map

Outer dimension views

## General Equations
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

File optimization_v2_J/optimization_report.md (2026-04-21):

# Beam Optimization Report

## Search Summary

- Search method: stratified global sampling with elite local refinement
- Total evaluated designs: 1200
- Feasible designs found: 687
- Minimum required factor of safety: 1.500
- Objective shaping: penalize excess FoS margin and underutilized stress envelope so the design approaches the 1.5 target more closely
- Maximum allowed deflection: not enforced in this run
- Random seed: 9999

## Best Design

- Weight: 0.02655 lbf
- Minimum factor of safety: 1.549
- Excess FoS above target: 0.049
- Governing minimum-FoS load case: Load Case 1 at x = 4.000 in
- Maximum deflection: 0.08478 in
- Constraint status: feasible
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

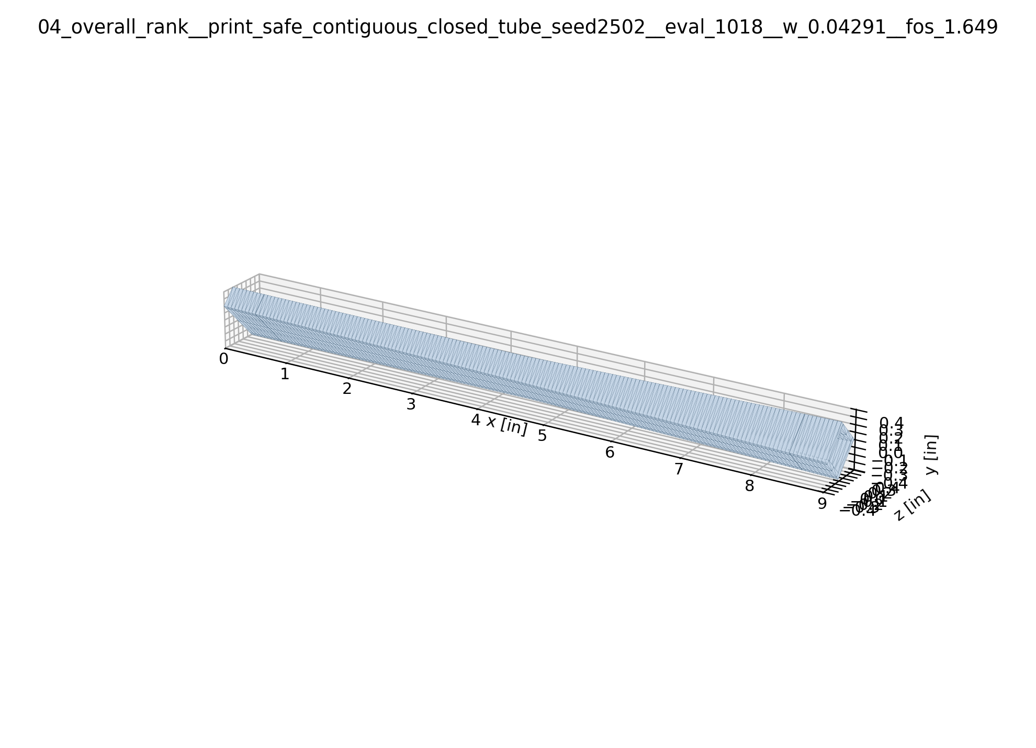
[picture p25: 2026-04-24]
docs/reports/figures/beam04/model_preview.png

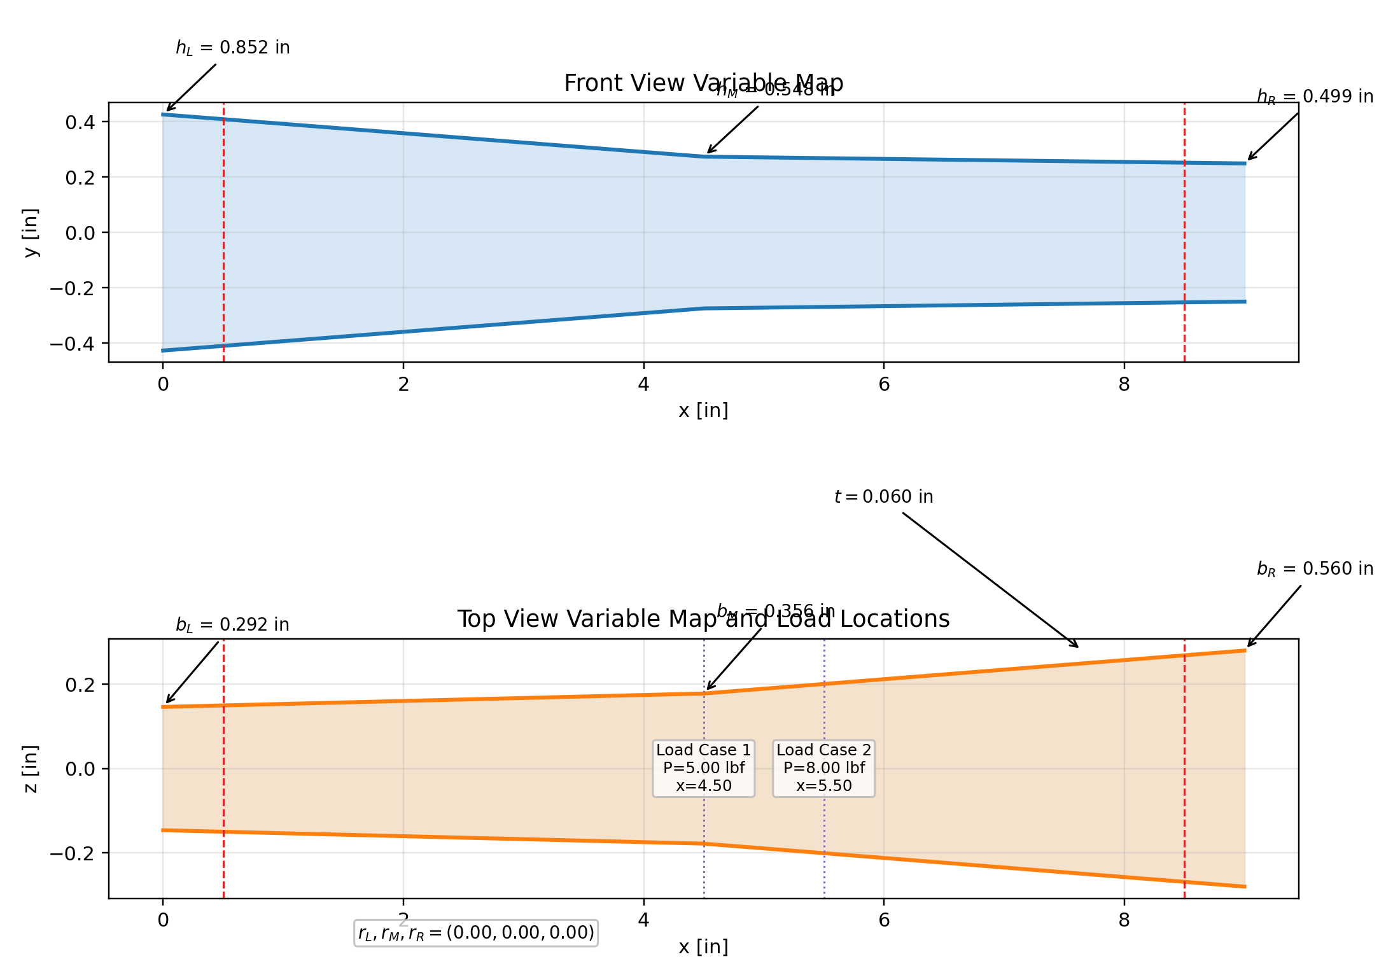
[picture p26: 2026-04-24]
docs/reports/figures/beam04/beam_parameter_map.png

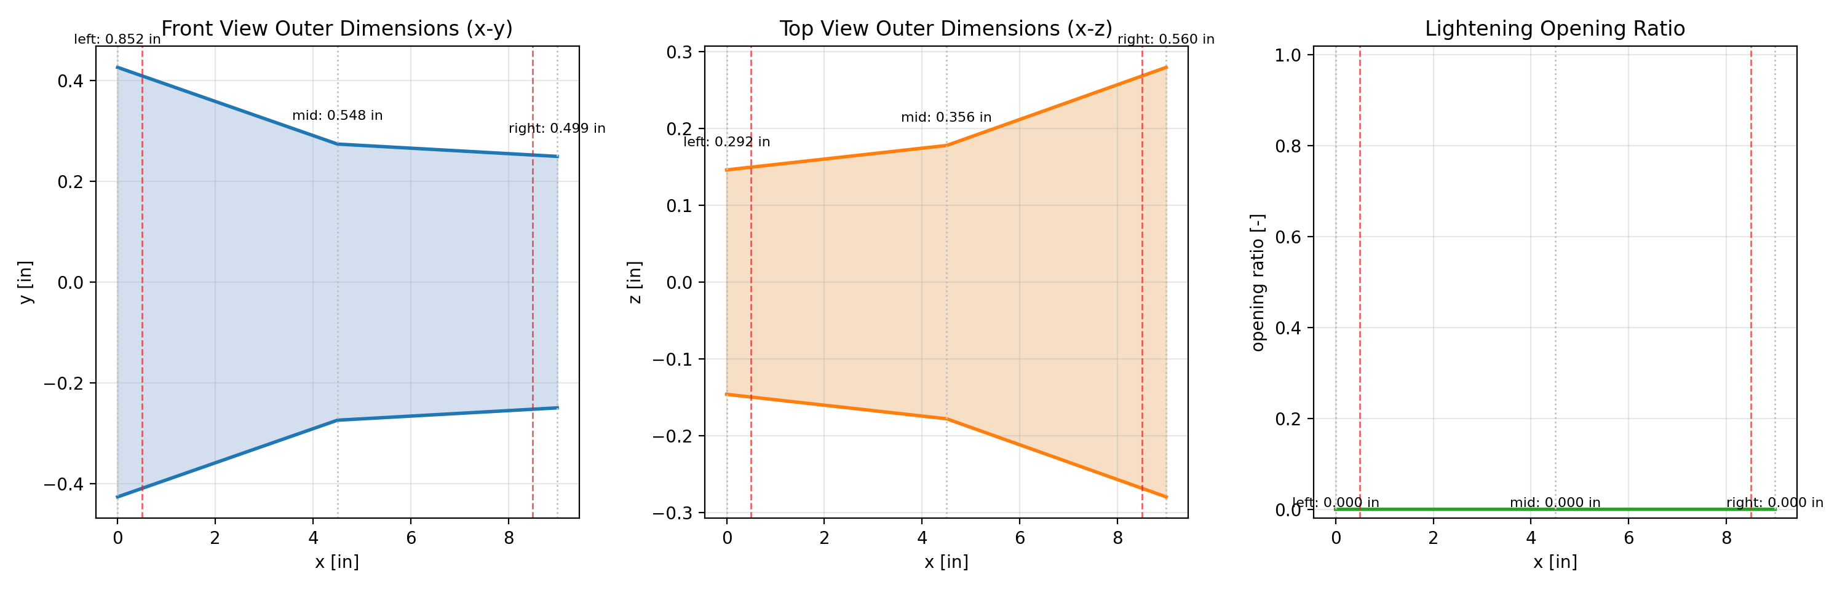
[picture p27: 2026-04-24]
docs/reports/figures/beam04/outer_dimension_views.png

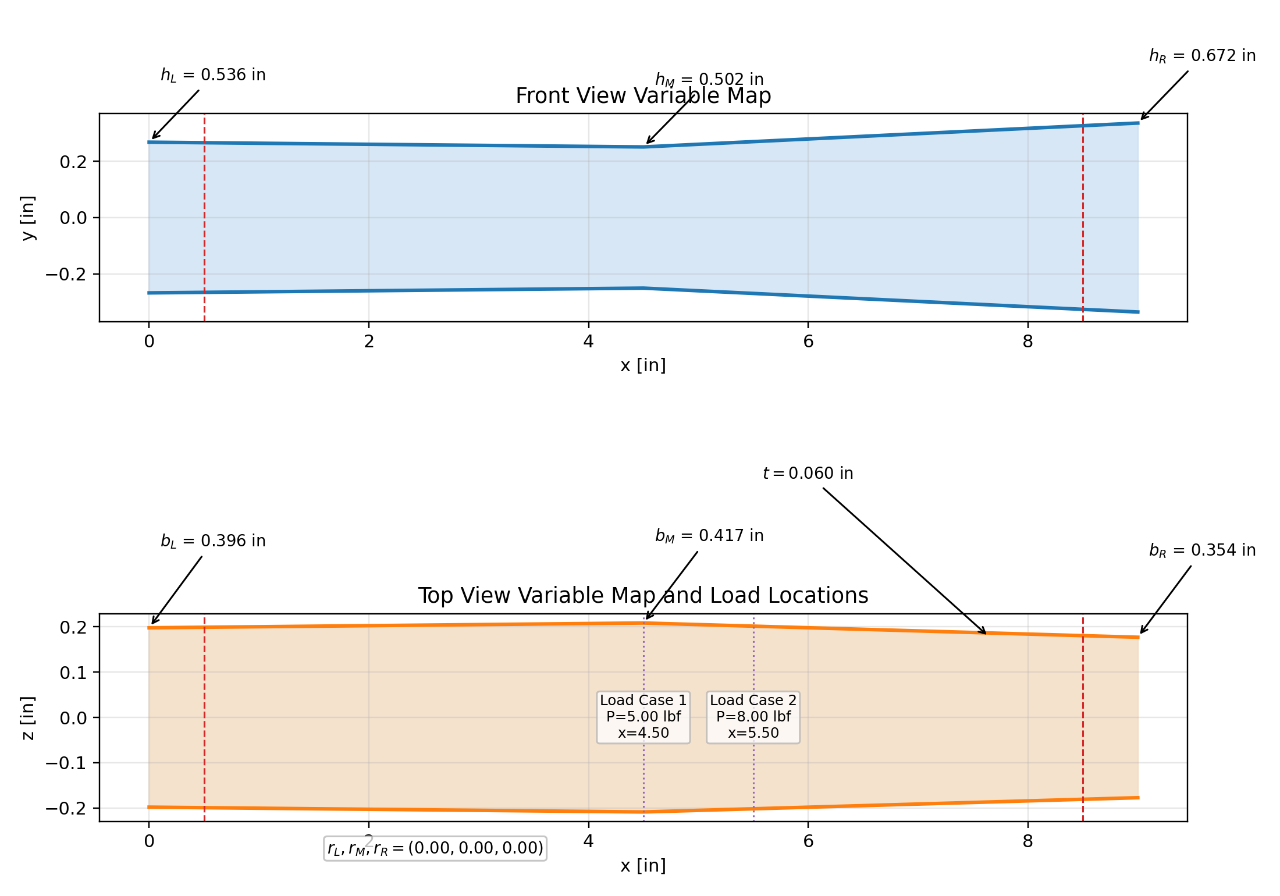
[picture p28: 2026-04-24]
docs/reports/figures/beam02/beam_parameter_map.png

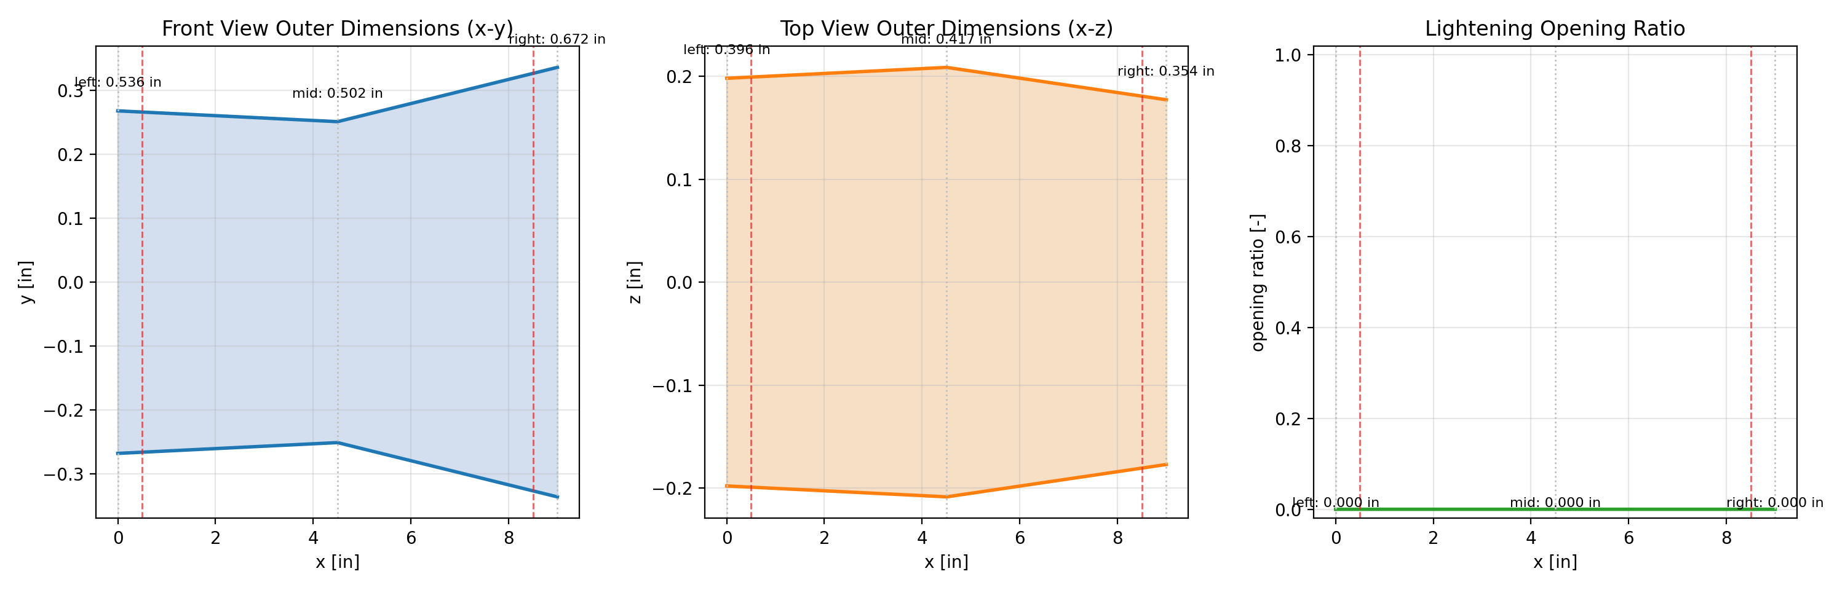
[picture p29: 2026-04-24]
docs/reports/figures/beam02/outer_dimension_views.png

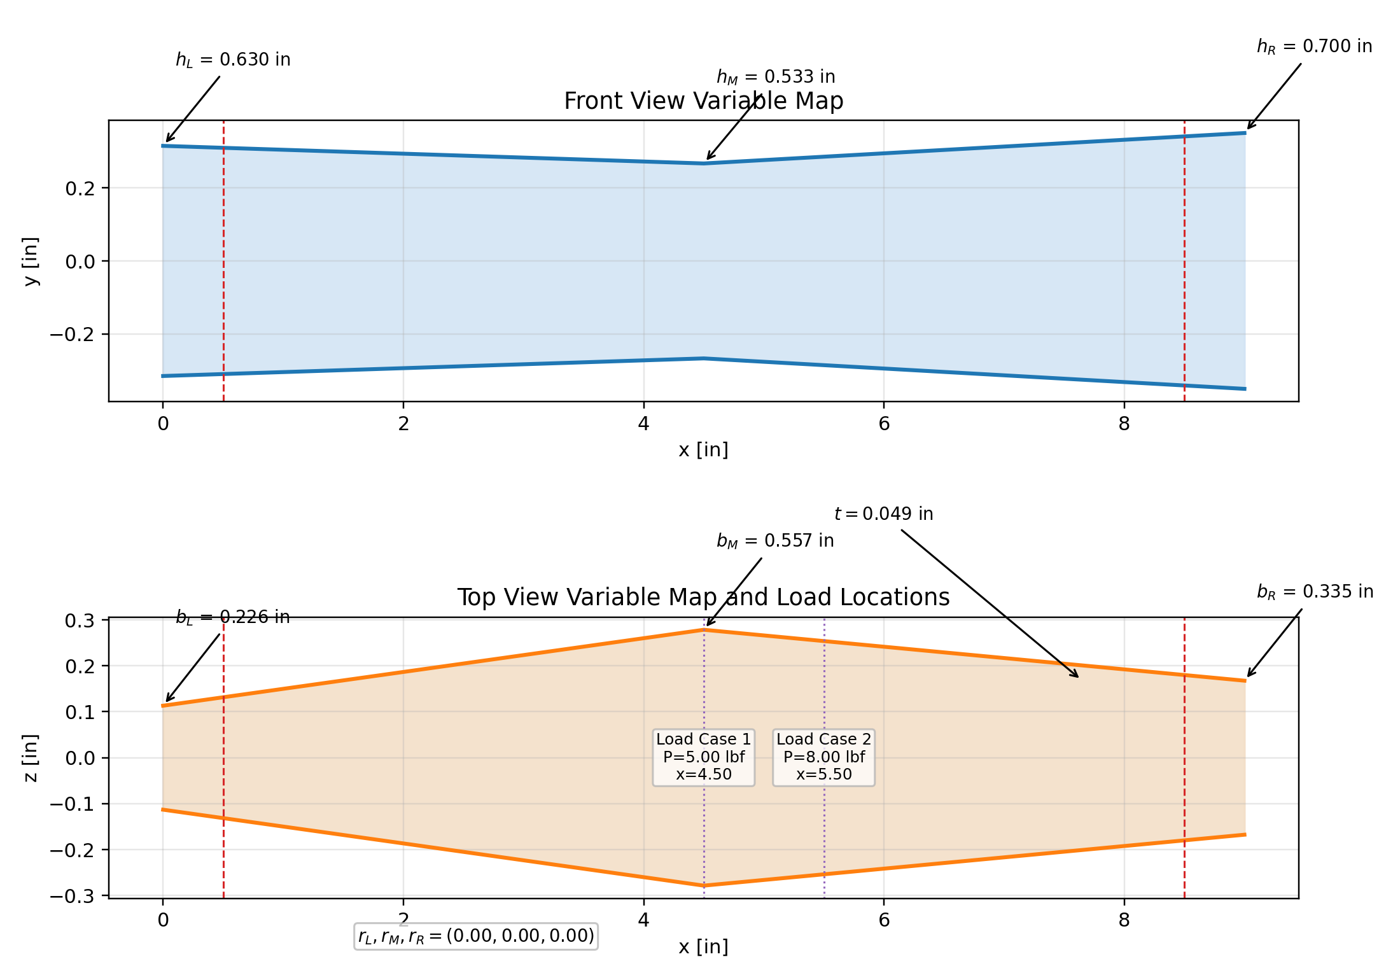
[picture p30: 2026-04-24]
best-designs-20/ranked-designs/13_overall_rank__ultra_light_runa_seed2430__eval_2464__w_0.03652__fos_2.154/beam_parameter_map.png

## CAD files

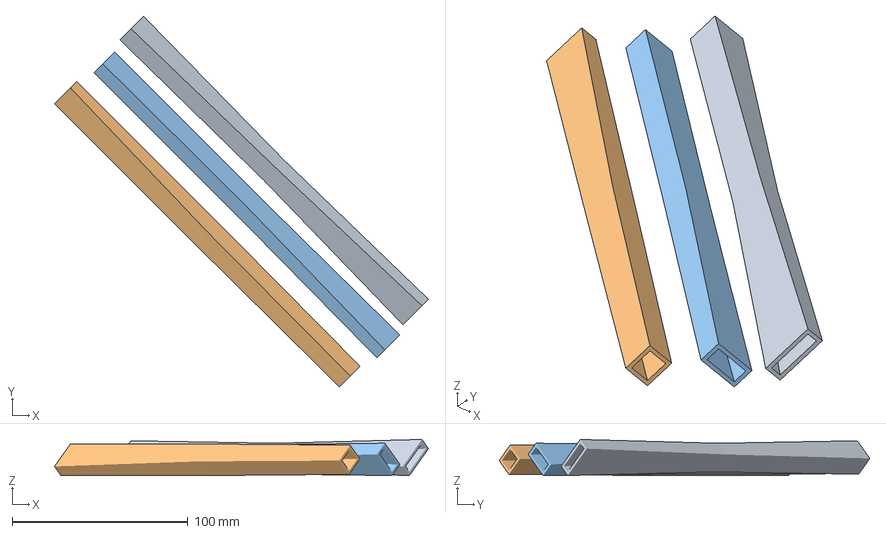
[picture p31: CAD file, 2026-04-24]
best-designs-20/3d-models-print-oriented/Completed_Actual_Sliced_Items.3mf
212.8 x 211.0 x 20.6 mm
04_overall_rank__print_safe_contiguous_closed_tube_seed2502__eval_1018__w_0.04291__fos_1.649.obj
03_overall_rank__print_safe_contiguous_closed_tube_seed2502__eval_1062__w_0.04179__fos_1.846.obj
02_overall_rank__print_safe_contiguous_closed_tube_seed2502__eval_1066__w_0.04048__fos_1.674.obj

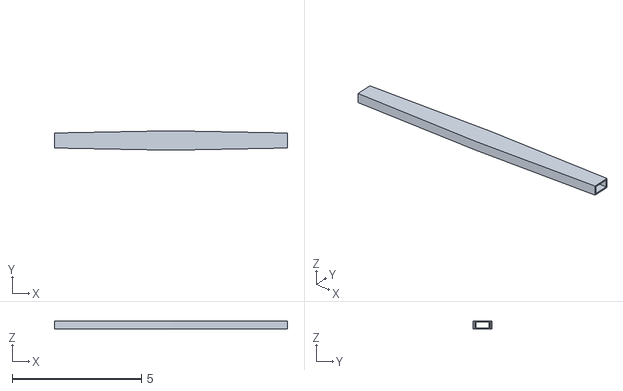
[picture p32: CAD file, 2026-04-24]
best-designs-20/3d-models/02_overall_rank__ultra_light_full_strength_seed2433__eval_1528__w_0.02894__fos_1.732.stl
9.00 x 0.749 x 0.314

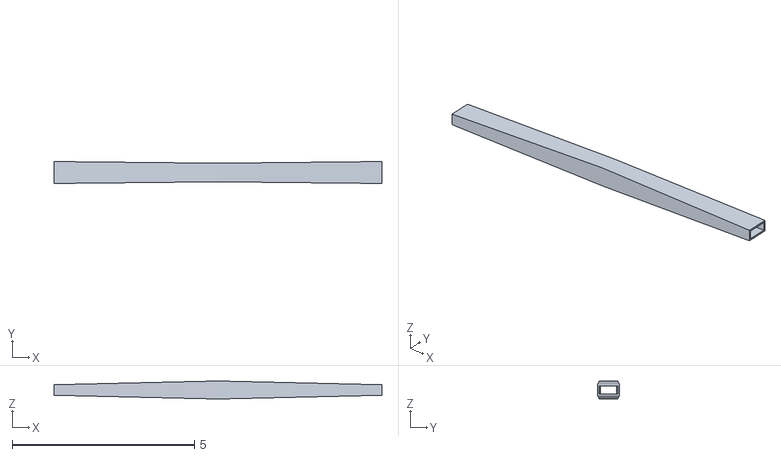
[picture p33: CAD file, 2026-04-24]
best-designs-20/design-packages/01_overall_rank__continuous_uniform_both_load_cases_9in_corrected__eval_0370__w_0.02815__fos_1.642/01_overall_rank__continuous_uniform_both_load_cases_9in_corrected__e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
9.00 x 0.602 x 0.494

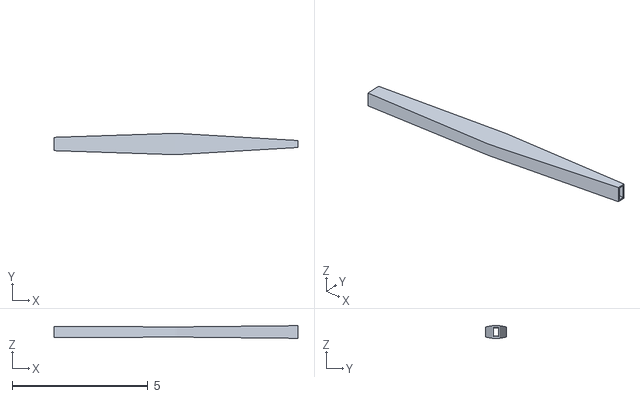
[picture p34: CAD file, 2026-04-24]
best-designs-20/design-packages/03_overall_rank__ultra_light_run4_asymmetric_seed2427__eval_1102__w_0.02958__fos_2.116/03_overall_rank__ultra_light_run4_asymmetric_seed2427__eval_1102__w_0.02958__fos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
9.00 x 0.787 x 0.468

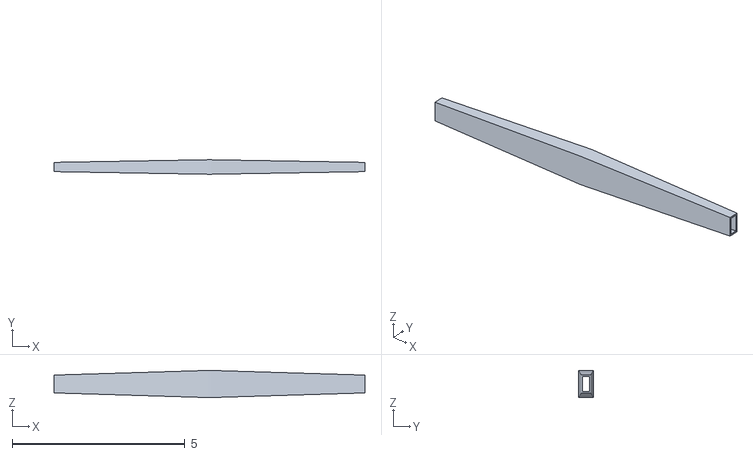
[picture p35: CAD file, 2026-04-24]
best-designs-20/design-packages/04_overall_rank__ultra_light_full_strength_seed2433__eval_2458__w_0.02971__fos_1.562/04_overall_rank__ultra_light_full_strength_seed2433__eval_2458__w_0.02971__fos_1.5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
9.00 x 0.421 x 0.786

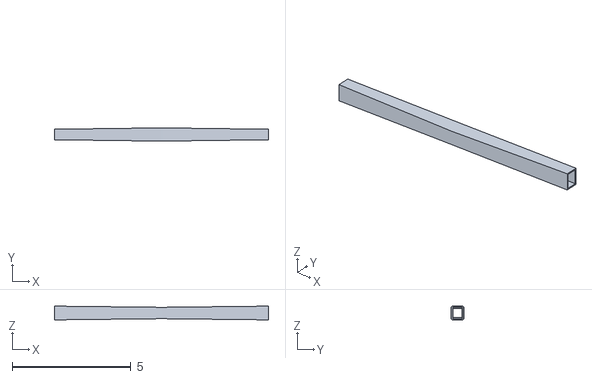
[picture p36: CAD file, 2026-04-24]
best-designs-20/design-packages/05_overall_rank__ultra_light_full_infill_seed2432__eval_2924__w_0.03074__fos_1.789/05_overall_rank__ultra_light_full_infill_seed2432__eval_2924__w_0.03074__fos_1.789.s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
9.00 x 0.558 x 0.579

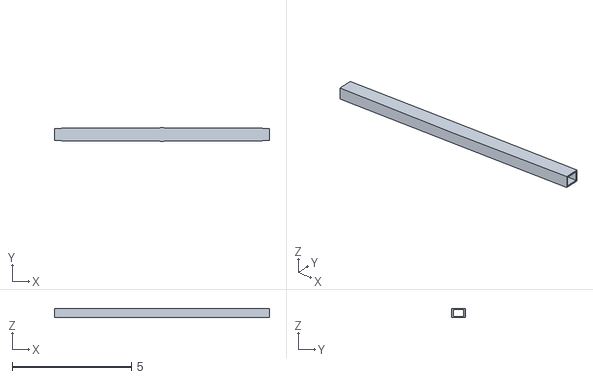
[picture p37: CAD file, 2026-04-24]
best-designs-20/design-packages/06_overall_rank__ultra_light_full_strength_seed2433__eval_1532__w_0.03127__fos_1.712/06_overall_rank__ultra_light_full_strength_seed2433__eval_1532__w_0.03127__fos_1.7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
9.00 x 0.566 x 0.397

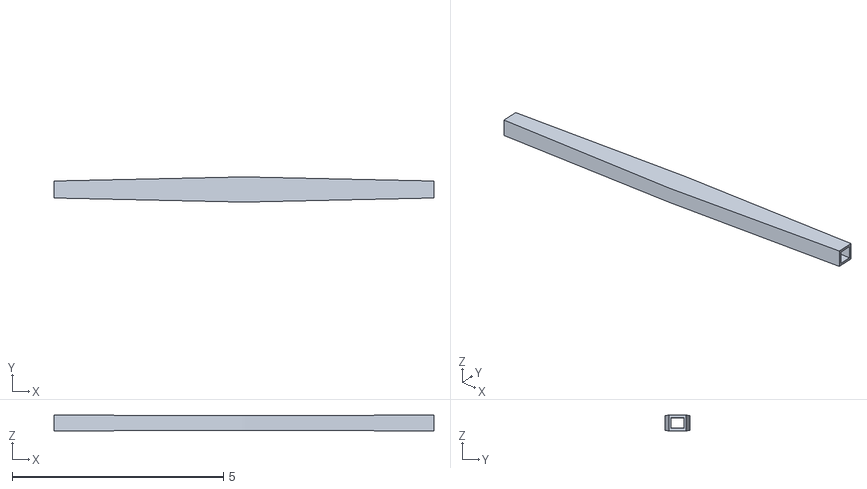
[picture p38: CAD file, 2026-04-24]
best-designs-20/design-packages/07_overall_rank__ultra_light_full_infill_seed2432__eval_2497__w_0.03158__fos_1.751/07_overall_rank__ultra_light_full_infill_seed2432__eval_2497__w_0.03158__fos_1.751.s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
9.00 x 0.595 x 0.376

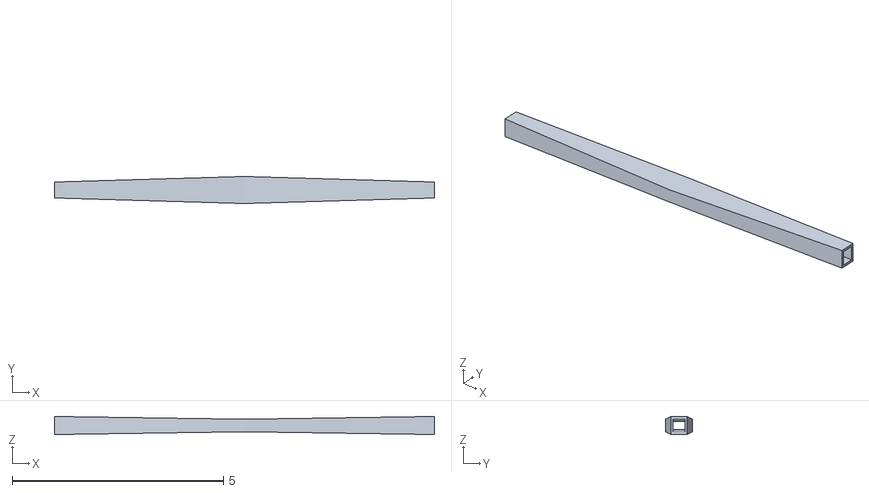
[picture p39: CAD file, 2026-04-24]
best-designs-20/design-packages/08_overall_rank__ultra_light_full_infill_seed2432__eval_2852__w_0.03254__fos_1.713/08_overall_rank__ultra_light_full_infill_seed2432__eval_2852__w_0.03254__fos_1.713.s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
9.00 x 0.639 x 0.428

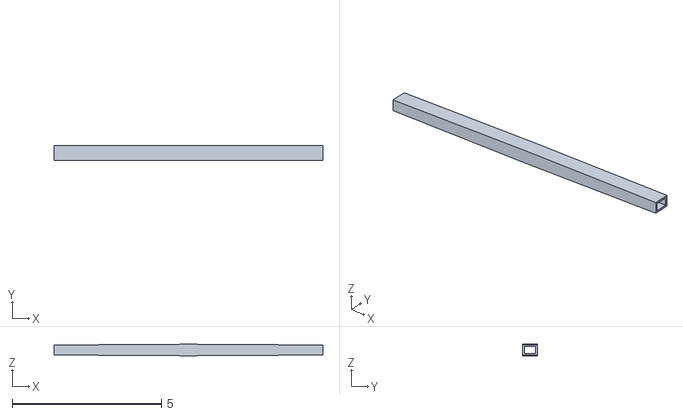
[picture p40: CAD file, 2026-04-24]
best-designs-20/design-packages/09_overall_rank__ultra_light_full_infill_seed2432__eval_2251__w_0.03329__fos_1.595/09_overall_rank__ultra_light_full_infill_seed2432__eval_2251__w_0.03329__fos_1.595.s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
9.00 x 0.492 x 0.388

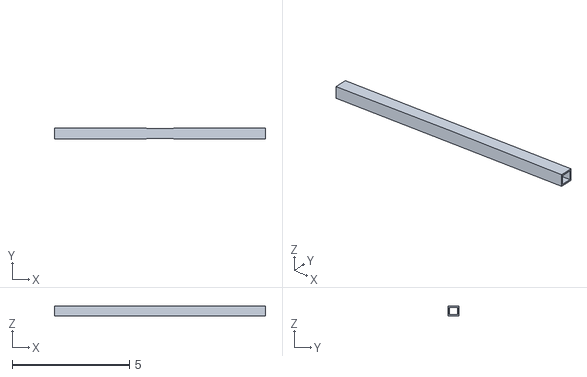
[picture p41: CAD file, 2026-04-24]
best-designs-20/design-packages/10_overall_rank__ultra_light_full_infill_seed2432__eval_2514__w_0.03483__fos_1.572/10_overall_rank__ultra_light_full_infill_seed2432__eval_2514__w_0.03483__fos_1.572.s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
9.00 x 0.477 x 0.442

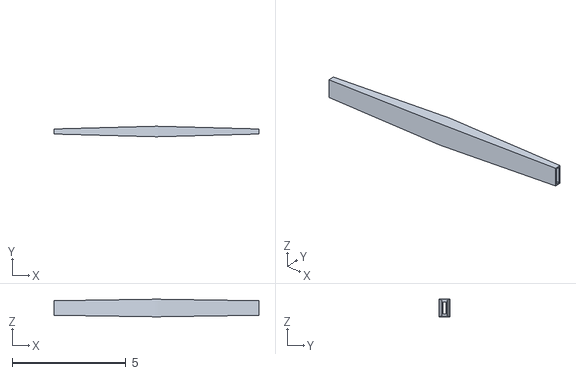
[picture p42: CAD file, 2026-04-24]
best-designs-20/design-packages/11_overall_rank__continuous_uniform_both_load_cases_9in_corrected__eval_0572__w_0.03504__fos_1.877/11_overall_rank__continuous_uniform_both_load_cases_9in_corrected__e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
9.00 x 0.463 x 0.773

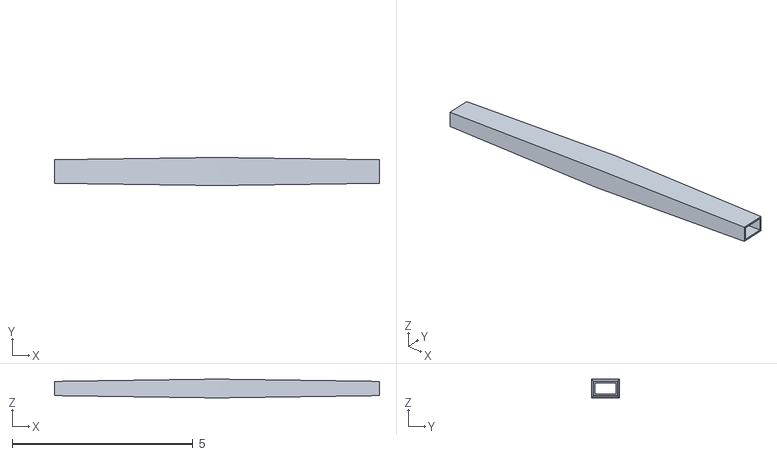
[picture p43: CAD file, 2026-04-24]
best-designs-20/design-packages/12_overall_rank__continuous_uniform_both_load_cases_9in_corrected__eval_0680__w_0.03546__fos_2.902/12_overall_rank__continuous_uniform_both_load_cases_9in_corrected__e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
9.00 x 0.777 x 0.521

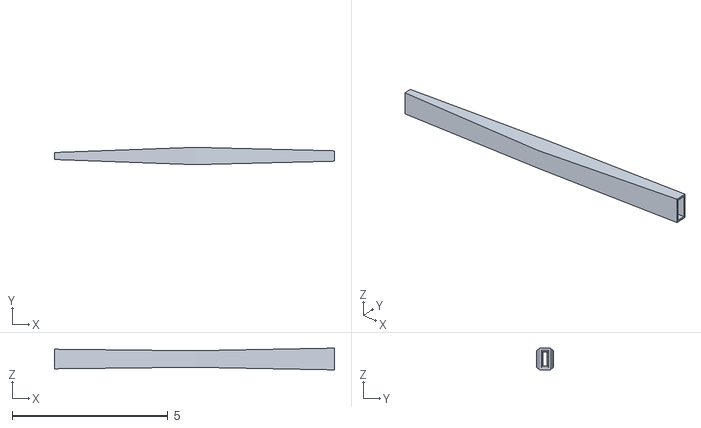
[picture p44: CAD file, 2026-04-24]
best-designs-20/design-packages/13_overall_rank__ultra_light_runa_seed2430__eval_2464__w_0.03652__fos_2.154/13_overall_rank__ultra_light_runa_seed2430__eval_2464__w_0.03652__fos_2.154.stl
9.00 x 0.555 x 0.7

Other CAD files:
best-designs-20/design-packages/14_overall_rank__continuous_uniform_both_load_cases_9in_corrected__eval_0402__w_0.03782__fos_2.022/14_overall_rank__continuous_uniform_both_load_cases_9in_corrected__e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
best-designs-20/design-packages/15_overall_rank__continuous_uniform_both_load_cases_9in_corrected__eval_0364__w_0.03983__fos_1.695/15_overall_rank__continuous_uniform_both_load_cases_9in_corrected__e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
best-designs-20/design-packages/16_overall_rank__continuous_uniform_both_load_cases_9in_corrected__eval_0219__w_0.03983__fos_1.761/16_overall_rank__continuous_uniform_both_load_cases_9in_corrected__e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
archive/deprecated_assets/legacy_continuous_design_deliverables/optimization_continuous_uniform_all/optimization_continuous_uniform_all.stl
archive/deprecated_assets/legacy_continuous_design_deliverables/optimization_continuous_uniform_load1/optimization_continuous_uniform_load1.stl
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

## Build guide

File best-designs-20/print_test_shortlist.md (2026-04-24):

# Print Test Shortlist — Current Set

Generated on 2026-04-24 (updated after prior-set test results).

This record covers the **current** best-designs-20 set: all solid closed-tube designs (web opening ratio = 0.000 everywhere) ranked by weight. Wall thickness floor is now 0.040 in (down from 0.060 in in the prior set), which pushed the lightest candidate from ~18 g down to 12.8 g.

Print the champion (rank 01) first. It is the lightest fully solid-wall beam that passes both load cases with standard PLA material assumptions (2380 psi effective allowable). No web openings means no bridging issues, no floating cantilever sections, and no material discontinuities in the side walls.

Use `print_settings.md` for slicer setup. STLs are in `3d-models/`. Scale to `2540%` uniform, or set X to `228.6 mm`, because mesh coordinates are in inches.

---

## Champion — Rank 01 (print first)

| Property | Imperial | Metric |
| --- | --- | --- |
| Design folder | `01_overall_rank__continuous_uniform_both_load_cases_9in_corrected__eval_0370__w_0.02815__fos_1.642` | — |
| Weight (model) | `0.02815 lbf` | `12.77 g` |
| Min FoS | `1.642` | — |
| Governing case | Load Case 2 (sideways, 8 lbf) | — |
| Max deflection | `0.0948 in` | `2.41 mm` |
| Width L / M / R | `0.6020 / 0.5109 / 0.6020 in` | `15.29 / 12.98 / 15.29 mm` |
| Height L / M / R | `0.2891 / 0.4955 / 0.2891 in` | `7.34 / 12.59 / 7.34 mm` |
| Wall thickness | `0.0400 in` | `1.016 mm` |
| Web openings | `0.000 / 0.000 / 0.000` | — |
| STL | `3d-models/01_overall_rank__continuous_uniform_both_load_cases_9in_corrected__eval_0370__w_0.02815__fos_1.642.stl` | — |

LC1 (upright, 5 lbf): FoS = 2.478, max VM = 960 psi, max defl = 0.0864 in / 2.19 mm  
LC2 (side, 8 lbf): FoS = 1.642, max VM = 1450 psi, max defl = 0.0948 in / 2.41 mm

The champion is also copied to `../final-champion/champion_beam.stl`.

---

## Backup Candidates (if rank 01 fails)

| Rank | Weight | Min FoS | Max defl | Notes |
| ---: | --- | --- | --- | --- |
| 02 | 13.1 g | 1.732 | — | Next lightest; solid wall, good FoS margin |
| 03 | 13.4 g | 2.116 | — | Over-designed but very safe backup |
| 04 | 13.5 g | 1.562 | — | Slightly heavier, tighter margin |
| 05 | 13.9 g | 1.789 | — | Conservative closed-tube option |

All backup STLs are in `3d-models/`.

---

## Print Gates (all designs in this set pass)

- Corrected 9.0 in beam, supports at x = 0.5 in and x = 8.5 in
- Max web opening ratio: **0.000** (solid walls, no holes)
- Wall thickness: ≥ 0.040 in (≥ 1.016 mm)
- Min FoS: ≥ 1.5 (standard PLA, 2380 psi effective allowable)
- Evaluated with standard PLA: orientation factor 0.70, infill factor 0.85

---

## Prior Print Test Results (for record)

See `../print_test_shortlist_prior_set.md` for the prior-set results. Summary: rank 03 of the prior set failed to print; ranks 02 and 04 printed successfully.

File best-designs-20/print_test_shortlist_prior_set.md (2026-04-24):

# Print Test Shortlist — Prior Set (2026-04-24 Physical Test Pass)

This file records the outcome of the first physical print-and-test pass on the weight-ranked `best-designs-20` set from commit `cf80a41`. That set enforced closed-tube gates with wall thickness ≥ 0.060 in. The current set (see `print_test_shortlist.md`) supersedes this with a lighter 0.040 in wall floor.

---

## What Was Printed

Only ranks 02, 03, and 04 were printed. Rank 01 and rank 05+ were not printed in this pass.

| Printed rank | Candidate | Weight | Min FoS | Print result |
| ---: | --- | --- | --- | --- |
| 02 | `02_overall_rank__print_safe_contiguous_closed_tube_seed2502__eval_1066__w_0.04048__fos_1.674` | 0.04048 lbf / 18.4 g | 1.674 | **Printed successfully.** Lightest printed candidate. |
| 03 | `03_overall_rank__print_safe_contiguous_closed_tube_seed2502__eval_1062__w_0.04179__fos_1.846` | 0.04179 lbf / 18.9 g | 1.846 | **Failed to print.** Did not complete or was not usable. |
| 04 | `04_overall_rank__print_safe_contiguous_closed_tube_seed2502__eval_1018__w_0.04291__fos_1.649` | 0.04291 lbf / 19.5 g | 1.649 | **Printed successfully.** |

---

## Not Printed In This Pass

- Rank 01: `01_overall_rank__continuous_uniform_both_load_cases_9in_corrected__eval_0219__w_0.03983__fos_1.761` — 18.1 g
- Rank 05: `05_overall_rank__print_safe_contiguous_closed_tube_seed2502__eval_1075__w_0.04297__fos_1.520` — 19.5 g
- Ranks 06–20

---

## Prior-Set Print Gates

- Corrected 9.0 in beam, supports at x = 0.5 in and x = 8.5 in
- Max web opening ratio: 0.000 (solid walls)
- Wall thickness: ≥ 0.060 in
- Residual web ligament: ≥ 0.140 in
- Shell area ratio: ≥ 0.320
- Max dimension slope: ≤ 0.140 in/in
- Max deflection: ≤ 0.165 in
- Min FoS: ≥ 1.5

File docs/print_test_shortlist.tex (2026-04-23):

\documentclass[11pt]{article}
\usepackage[margin=1in]{geometry}
\usepackage{booktabs}
\usepackage{array}
\usepackage{longtable}
\usepackage{tabularx}
\usepackage{hyperref}
\usepackage{xcolor}
\usepackage{ragged2e}

\hypersetup{
  colorlinks=true,
  linkcolor=blue,
  urlcolor=blue
}

\newcommand{\pathlink}[1]{\href{run:#1}{\nolinkurl{#1}}}
\newcommand{\runlink}[2]{\href{run:#1}{#2}}
\newcommand{\designid}[1]{\nolinkurl{#1}}
\newcolumntype{Y}{>{\RaggedRight\arraybackslash}X}
\renewcommand{\arraystretch}{1.15}
\setlength{\tabcolsep}{4pt}

\title{MEEN 305 Print-Test Shortlist}
\author{}
\date{2026-04-23}

\begin{document}
\maketitle

\section*{Bottom Line}

The current project-correct design to print first is
\designid{continuous_uniform_both_load_cases_9in_corrected}. It is the
active source-of-truth design in this repo because it explicitly uses the
correct beam geometry: total length \(9.0\ \mathrm{in}\)
\((228.6\ \mathrm{mm})\), supports at \(x=0.5\ \mathrm{in}\)
\((12.7\ \mathrm{mm})\) and \(x=8.5\ \mathrm{in}\)
\((215.9\ \mathrm{mm})\), and the Team 6 load cases.

The older archived designs are still useful as comparison specimens, but they
should be treated as \emph{benchmark prints}, not as the final project answer,
because the repo notes state that many archived outputs predate the full
9-inch support-placement correction.

\section*{What To Do Next}

\begin{enumerate}
  \item Print and test
  \texttt{continuous\_uniform\_both\_load\_cases\_9in\_corrected} first. This
  is the only design in the shortlist that is both current and project-correct.
  \item Print \texttt{optimization\_final} as the archived baseline. It is the
  cleanest older ``final-style'' candidate and remains one of the best fully
  documented print-friendly references in the repo.
  \item Print \texttt{optimization\_revised\_symmetric\_light} next if you want
  a cleaner symmetric comparison that still stays near the FoS \(=1.5\) target.
  \item Print \texttt{optimization\_v2\_Q7777} as the aggressive lightweight
  benchmark. It is one of the lightest archived Team-6-style passing options.
  \item If you want a fifth print, use
  \texttt{optimization\_revised\_symmetric\_balanced} as a smooth, symmetric
  control specimen.
  \item Do \emph{not} spend a print on both \texttt{optimization\_final} and
  \texttt{optimization\_connected\_v2\_6060}; their stored geometry and metrics
  are effectively identical in this repo.
  \item Use one print profile for all test pieces so the comparison is fair,
  then record actual mass, max elastic deflection, visible failure location,
  and whether failure starts near the predicted governing section.
  \item After testing, update the final report with corrected 9-inch results
  plus a short validation table comparing predicted and measured behavior.
\end{enumerate}

\section*{Common Material And Print Assumptions}

These are the analysis assumptions used by the active solver in
\pathlink{scripts/beam_solver.py}.

\small
\begin{tabularx}{\textwidth}{@{}p{0.28\textwidth}YY@{}}
\toprule
Property & Imperial & Metric \\
\midrule
Material family & PLA & PLA \\
Printer basis & 0.4 mm nozzle, about 40\% rectilinear infill & 0.0157 in nozzle, about 40\% rectilinear infill \\
Beam length & \(9.0\ \mathrm{in}\) total, \(8.0\ \mathrm{in}\) support span & \(228.6\ \mathrm{mm}\) total, \(203.2\ \mathrm{mm}\) support span \\
Support locations & \(x_A=0.5\ \mathrm{in}\), \(x_B=8.5\ \mathrm{in}\) & \(x_A=12.7\ \mathrm{mm}\), \(x_B=215.9\ \mathrm{mm}\) \\
Load Case 1 & \(5.0\ \mathrm{lbf}\) at \(4.0\ \mathrm{in}\) from A & \(22.24\ \mathrm{N}\) at \(101.6\ \mathrm{mm}\) from A \\
Load Case 2 & \(8.0\ \mathrm{lbf}\) at \(5.0\ \mathrm{in}\) from A & \(35.59\ \mathrm{N}\) at \(127.0\ \mathrm{mm}\) from A \\
Nominal elastic modulus & \(500{,}000\ \mathrm{psi}\) & \(3447.38\ \mathrm{MPa}\) \\
Nominal allowable stress & \(4{,}000\ \mathrm{psi}\) & \(27.58\ \mathrm{MPa}\) \\
Weight density & \(0.045\ \mathrm{lbf/in^3}\) & \(12.22\ \mathrm{kN/m^3}\) (about \(1.25\ \mathrm{g/cm^3}\) mass density) \\
Orientation factor & \(0.70\) & \(0.70\) \\
Infill factor & \(0.85\) & \(0.85\) \\
Effective modulus used in solver & \(297{,}500\ \mathrm{psi}\) & \(2051.19\ \mathrm{MPa}\) \\
Effective allowable stress used in solver & \(2{,}380\ \mathrm{psi}\) & \(16.41\ \mathrm{MPa}\) \\
Hard printability floor & wall thickness \(\ge 0.040\ \mathrm{in}\), dimension \(\ge 0.150\ \mathrm{in}\) & wall thickness \(\ge 1.016\ \mathrm{mm}\), dimension \(\ge 3.81\ \mathrm{mm}\) \\
Durability screen target & residual ligament \(\ge 0.080\ \mathrm{in}\) & residual ligament \(\ge 2.032\ \mathrm{mm}\) \\
\bottomrule
\end{tabularx}
\normalsize

\section*{Recommended Print Queue}

If you only want four prints, stop after Item 4. Item 5 is the optional control.

\small
\begin{longtable}{@{}p{0.05\textwidth}p{0.25\textwidth}p{0.15\textwidth}p{0.09\textwidth}p{0.15\textwidth}p{0.24\textwidth}@{}}
\toprule
Order & Design & Weight [lbf / N] & Min FoS & Max Defl. [in / mm] & Why it belongs in the test set \\
\midrule
\endhead
1 & \designid{continuous_uniform_both_load_cases_9in_corrected} & 0.04079 / 0.181 & 1.503 & 0.16121 / 4.10 & Current project-correct reference design; must-print. \\
2 & \designid{optimization_final} & 0.03018 / 0.134 & 1.634 & 0.12226 / 3.11 & Best archived final-style benchmark with full package and clean printability. \\
3 & \designid{optimization_revised_symmetric_light} & 0.03254 / 0.145 & 1.515 & 0.13453 / 3.42 & Best symmetric near-target comparator. \\
4 & \designid{optimization_v2_Q7777} & 0.03454 / 0.154 & 1.522 & 0.11608 / 2.95 & Lightest archived Team-6-style passing option; useful aggressive benchmark. \\
5 & \designid{optimization_revised_symmetric_balanced} & 0.02649 / 0.118 & 1.863 & 0.09424 / 2.39 & Optional smooth control specimen; easiest geometry family to compare against. \\
\bottomrule
\end{longtable}
\normalsize

\section*{Design Notes}

\subsection*{1. Corrected 9 in Reference}

\textbf{Why first:} this is the repo's current recommended design in
\pathlink{docs/notes/current_design_selection.md}. It is the one that matches
the corrected 9-inch beam with supports at \(x=0.5\ \mathrm{in}\)
\((12.7\ \mathrm{mm})\) and \(x=8.5\ \mathrm{in}\)
\((215.9\ \mathrm{mm})\).

\small
\begin{tabularx}{\textwidth}{@{}p{0.31\textwidth}Y@{}}
\toprule
Property & Value \\
\midrule
Design ID & \designid{continuous_uniform_both_load_cases_9in_corrected} \\
Widths & \(0.521 / 0.294 / 0.521\ \mathrm{in}\) \\ \(13.24 / 7.48 / 13.24\ \mathrm{mm}\) \\
Heights & \(0.659 / 0.713 / 0.659\ \mathrm{in}\) \\ \(16.73 / 18.11 / 16.73\ \mathrm{mm}\) \\
Wall thickness & \(0.0508\ \mathrm{in}\) \\ \(1.290\ \mathrm{mm}\) \\
Web openings & \(0 / 0 / 0\) \\
Governing case & Load Case 2 at global \(x=5.5\ \mathrm{in}\) \\ global \(x=139.7\ \mathrm{mm}\) \\
Minimum FoS & \(1.503\) \\
Maximum deflection & \(0.16121\ \mathrm{in}\) \\ \(4.095\ \mathrm{mm}\) \\
\bottomrule
\end{tabularx}

\vspace{0.5em}
\begin{tabularx}{\textwidth}{@{}p{0.22\textwidth}Y@{}}
\toprule
File & Link \\
\midrule
Package folder & \runlink{designs/packages/continuous_design_deliverables_9in_corrected/continuous_uniform_both_load_cases_9in_corrected}{Open package folder} \\
STL & \runlink{designs/packages/continuous_design_deliverables_9in_corrected/continuous_uniform_both_load_cases_9in_corrected/continuous_uniform_both_load_cases_9in_corrected.stl}{Open STL} \\
Best design JSON & \runlink{designs/packages/continuous_design_deliverables_9in_corrected/continuous_uniform_both_load_cases_9in_corrected/best_design.json}{Open JSON} \\
Report & \runlink{designs/packages/continuous_design_deliverables_9in_corrected/continuous_uniform_both_load_cases_9in_corrected/optimization_report.md}{Open report} \\
\bottomrule
\end{tabularx}
\normalsize

\subsection*{2. Archived Final Baseline}

\textbf{Why second:} this is the cleanest archived ``final'' comparison print.
The archived printability note explicitly calls it a defensible final choice.

\small
\begin{tabularx}{\textwidth}{@{}p{0.31\textwidth}Y@{}}
\toprule
Property & Value \\
\midrule
Design ID & \designid{optimization_final} \\
Widths & \(0.446 / 0.350 / 0.572\ \mathrm{in}\) \\ \(11.32 / 8.90 / 14.54\ \mathrm{mm}\) \\
Heights & \(1.051 / 0.559 / 0.530\ \mathrm{in}\) \\ \(26.69 / 14.21 / 13.46\ \mathrm{mm}\) \\
Wall thickness & \(0.0600\ \mathrm{in}\) \\ \(1.524\ \mathrm{mm}\) \\
Web openings & \(0.621 / 0.525 / 0.297\) \\
Governing case & Load Case 2 at \(x=5.0\ \mathrm{in}\) \\ \(x=127.0\ \mathrm{mm}\) \\
Minimum FoS & \(1.634\) \\
Maximum deflection & \(0.12226\ \mathrm{in}\) \\ \(3.105\ \mathrm{mm}\) \\
\bottomrule
\end{tabularx}

\vspace{0.5em}
\begin{tabularx}{\textwidth}{@{}p{0.22\textwidth}Y@{}}
\toprule
File & Link \\
\midrule
Package folder & \runlink{archive/deprecated_assets/relevant_design_packages/optimization_final}{Open package folder} \\
STL & \runlink{archive/deprecated_assets/relevant_design_packages/optimization_final/optimization_final.stl}{Open STL} \\
Best design JSON & \runlink{archive/deprecated_assets/relevant_design_packages/optimization_final/best_design.json}{Open JSON} \\
Report & \runlink{archive/deprecated_assets/relevant_design_packages/optimization_final/optimization_report.md}{Open report} \\
\bottomrule
\end{tabularx}
\normalsize

\subsection*{3. Symmetric Near-Target Comparator}

\textbf{Why third:} this is the best archived symmetric design that still stays
very close to the FoS target. It is useful if you want a specimen that is easy
to explain and visually cleaner than the more asymmetric archived runs.

\small
\begin{tabularx}{\textwidth}{@{}p{0.31\textwidth}Y@{}}
\toprule
Property & Value \\
\midrule
Design ID & \designid{optimization_revised_symmetric_light} \\
Widths & \(0.535 / 0.362 / 0.535\ \mathrm{in}\) \\ \(13.58 / 9.21 / 13.58\ \mathrm{mm}\) \\
Heights & \(0.453 / 0.493 / 0.453\ \mathrm{in}\) \\ \(11.50 / 12.52 / 11.50\ \mathrm{mm}\) \\
Wall thickness & \(0.0600\ \mathrm{in}\) \\ \(1.524\ \mathrm{mm}\) \\
Web openings & \(0.000 / 0.266 / 0.000\) \\
Governing case & Load Case 2 at \(x=5.0\ \mathrm{in}\) \\ \(x=127.0\ \mathrm{mm}\) \\
Minimum FoS & \(1.515\) \\
Maximum deflection & \(0.13453\ \mathrm{in}\) \\ \(3.417\ \mathrm{mm}\) \\
\bottomrule
\end{tabularx}

\vspace{0.5em}
\begin{tabularx}{\textwidth}{@{}p{0.22\textwidth}Y@{}}
\toprule
File & Link \\
\midrule
Package folder & \runlink{archive/deprecated_assets/relevant_design_packages/optimization_revised_symmetric_light}{Open package folder} \\
STL & \runlink{archive/deprecated_assets/relevant_design_packages/optimization_revised_symmetric_light/optimization_revised_symmetric_light.stl}{Open STL} \\
Best design JSON & \runlink{archive/deprecated_assets/relevant_design_packages/optimization_revised_symmetric_light/best_design.json}{Open JSON} \\
Report & \runlink{archive/deprecated_assets/relevant_design_packages/optimization_revised_symmetric_light/optimization_report.md}{Open report} \\
\bottomrule
\end{tabularx}
\normalsize

\subsection*{4. Aggressive Lightweight Benchmark}

\textbf{Why fourth:} among the archived Team-6-style designs that still pass
cleanly, this is the lightweight aggressive benchmark. It is not the current
final answer, but it is still a strong comparison specimen.

\small
\begin{tabularx}{\textwidth}{@{}p{0.31\textwidth}Y@{}}
\toprule
Property & Value \\
\midrule
Design ID & \designid{optimization_v2_Q7777} \\
Widths & \(0.823 / 0.350 / 0.350\ \mathrm{in}\) \\ \(20.90 / 8.89 / 8.89\ \mathrm{mm}\) \\
Heights & \(0.959 / 0.727 / 0.606\ \mathrm{in}\) \\ \(24.37 / 18.46 / 15.38\ \mathrm{mm}\) \\
Wall thickness & \(0.0600\ \mathrm{in}\) \\ \(1.524\ \mathrm{mm}\) \\
Web openings & \(0.334 / 0.650 / 0.276\) \\
Governing case & Load Case 2 at \(x=5.0\ \mathrm{in}\) \\ \(x=127.0\ \mathrm{mm}\) \\
Minimum FoS & \(1.522\) \\
Maximum deflection & \(0.11608\ \mathrm{in}\) \\ \(2.949\ \mathrm{mm}\) \\
\bottomrule
\end{tabularx}

\vspace{0.5em}
\begin{tabularx}{\textwidth}{@{}p{0.22\textwidth}Y@{}}
\toprule
File & Link \\
\midrule
Data folder & \runlink{archive/deprecated_assets/optimization_v2_Q7777}{Open data folder} \\
STL & \runlink{archive/deprecated_assets/models_3d/optimization_v2_q7777.stl}{Open STL} \\
Best design JSON & \runlink{archive/deprecated_assets/optimization_v2_Q7777/best_design.json}{Open JSON} \\
Report & \runlink{archive/deprecated_assets/optimization_v2_Q7777/optimization_report.md}{Open report} \\
\bottomrule
\end{tabularx}
\normalsize

\subsection*{5. Symmetric Balanced Control (Optional)}

\textbf{Why optional:} this is a good control print when you want a smooth,
very symmetric geometry with comfortable margin. It is lighter than the other
archived candidates listed here, but it is also more conservative than the
near-target options because the minimum FoS stays well above 1.5.

\small
\begin{tabularx}{\textwidth}{@{}p{0.31\textwidth}Y@{}}
\toprule
Property & Value \\
\midrule
Design ID & \designid{optimization_revised_symmetric_balanced} \\
Widths & \(0.350 / 0.411 / 0.350\ \mathrm{in}\) \\ \(8.89 / 10.44 / 8.89\ \mathrm{mm}\) \\
Heights & \(0.785 / 0.777 / 0.785\ \mathrm{in}\) \\ \(19.95 / 19.74 / 19.95\ \mathrm{mm}\) \\
Wall thickness & \(0.0604\ \mathrm{in}\) \\ \(1.534\ \mathrm{mm}\) \\
Web openings & \(0.677 / 0.631 / 0.677\) \\
Governing case & Load Case 2 at \(x=5.0\ \mathrm{in}\) \\ \(x=127.0\ \mathrm{mm}\) \\
Minimum FoS & \(1.863\) \\
Maximum deflection & \(0.09424\ \mathrm{in}\) \\ \(2.394\ \mathrm{mm}\) \\
\bottomrule
\end{tabularx}

\vspace{0.5em}
\begin{tabularx}{\textwidth}{@{}p{0.22\textwidth}Y@{}}
\toprule
File & Link \\
\midrule
Package folder & \runlink{archive/deprecated_assets/relevant_design_packages/optimization_revised_symmetric_balanced}{Open package folder} \\
STL & \runlink{archive/deprecated_assets/relevant_design_packages/optimization_revised_symmetric_balanced/optimization_revised_symmetric_balanced.stl}{Open STL} \\
Best design JSON & \runlink{archive/deprecated_assets/relevant_design_packages/optimization_revised_symmetric_balanced/best_design.json}{Open JSON} \\
Report & \runlink{archive/deprecated_assets/relevant_design_packages/optimization_revised_symmetric_balanced/optimization_report.md}{Open report} \\
\bottomrule
\end{tabularx}
\normalsize

\section*{Notes On Scope}

\begin{itemize}
  \item The corrected design is the one to cite in the final report.
  \item The archived designs are still worth printing because they cover
  different geometry strategies: open-web asymmetric, clean symmetric, and
  aggressive lightweight variants.
  \item I intentionally did not include archived designs such as
  \designid{optimization_v2_E} or \designid{optimization_v2_F} in the main
  print queue because their stored load cases do not match the current Team 6
  loading used by the active corrected workflow.
\end{itemize}

\end{document}

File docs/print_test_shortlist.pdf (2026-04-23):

# MEEN 305 Print-Test Shortlist

2026-04-23

## Bottom Line

The current project-correct design to print first is continuous_uniform_both_load_cases_9in_ corrected. It is the active source-of-truth design in this repo because it explicitly uses the correct beam geometry: total length 9.0 in (228.6 mm), supports at x = 0.5 in (12.7 mm) and x = 8.5 in (215.9 mm), and the Team 6 load cases.
The older archived designs are still useful as comparison specimens, but they should be treated as benchmark prints, not as the final project answer, because the repo notes state that many archived outputs predate the full 9-inch support-placement correction.

## What To Do Next

1. Print and test continuous uniform both load cases 9in corrected first. This is the only design in the shortlist that is both current and project-correct.
2. Print optimization final as the archived baseline. It is the cleanest older “final-style” candidate and remains one of the best fully documented print-friendly references in the repo.
3. Print optimization revised symmetric light next if you want a cleaner symmetric comparison that still stays near the FoS = 1.5 target.
4. Print optimization v2 Q7777 as the aggressive lightweight benchmark. It is one of the lightest archived Team-6-style passing options.
5. If you want a fifth print, use optimization revised symmetric balanced as a smooth, symmetric control specimen.
6. Do not spend a print on both optimization final and optimization connected v2 6060; their stored geometry and metrics are effectively identical in this repo.
7. Use one print profile for all test pieces so the comparison is fair, then record actual mass, max elastic deflection, visible failure location, and whether failure starts near the predicted governing section.
8. After testing, update the final report with corrected 9-inch results plus a short validation table comparing predicted and measured behavior.

## Common Material And Print Assumptions

These are the analysis assumptions used by the active solver in scripts/beam_solver.py.

Property | Imperial | Metric
Material family | PLA | PLA
Printer basis | 0.4 mm nozzle, about 40% rectilin-
ear infill

0.0157 in nozzle, about 40% rectilinear infill
Beam length | 9.0 in total, 8.0 in support span | 228.6 mm total, 203.2 mm support
span
Support locations | xA = 0.5 in, xB = 8.5 in | xA = 12.7 mm, xB = 215.9 mm
Load Case 1 | 5.0 lbf at 4.0 in from A | 22.24 N at 101.6 mm from A
Load Case 2 | 8.0 lbf at 5.0 in from A | 35.59 N at 127.0 mm from A
Nominal elastic modulus | 500,000 psi | 3447.38 MPa
Nominal allowable stress | 4,000 psi | 27.58 MPa
Weight density | 0.045 lbf/in³ | 12.22 kN/m³

(about 1.25 g/cm³
mass density)
Orientation factor | 0.70 | 0.70
Infill factor | 0.85 | 0.85
Effective modulus used in
solver
297,500 psi | 2051.19 MPa

Effective allowable stress used
in solver
2,380 psi | 16.41 MPa
Hard printability floor | wall thickness ≥ 0.040 in, dimension
≥ 0.150 in

wall thickness ≥ 1.016 mm, dimension ≥ 3.81 mm
Durability screen target | residual ligament ≥ 0.080 in | residual ligament ≥ 2.032 mm

## Recommended Print Queue

If you only want four prints, stop after Item 4. Item 5 is the optional control.

Order Design | Weight [lbf / N] Min FoS | Max Defl. [in /
mm]

Why it belongs in the test set

1 | continuous_uniform_
both_load_cases_9in_
corrected
0.04079 / 0.181 | 1.503 | 0.16121 / 4.10 | Current | project-correct
reference design; | must-
print.
2 | optimization_final | 0.03018 / 0.134 | 1.634 | 0.12226 / 3.11 | Best archived final-style
benchmark with full package and clean printability.
3 | optimization_revised_
symmetric_light
0.03254 / 0.145 | 1.515 | 0.13453 / 3.42 | Best | symmetric | near-
target comparator.
4 | optimization_v2_Q7777 | 0.03454 / 0.154 | 1.522 | 0.11608 / 2.95 | Lightest archived Team-6-
style passing option; useful aggressive benchmark.
5 | optimization_revised_
symmetric_balanced
0.02649 / 0.118 | 1.863 | 0.09424 / 2.39 | Optional smooth control
specimen; easiest geometry family to compare
against.

## Design Notes

### 1. Corrected 9 in Reference

Why first: this is the repo’s current recommended design in docs/notes/current_design_ selection.md. It is the one that matches the corrected 9-inch beam with supports at x = 0.5 in (12.7 mm) and x = 8.5 in (215.9 mm).

Property | Value
Design ID | continuous_uniform_both_load_cases_9in_corrected
Widths | 0.521/0.294/0.521 in
13.24/7.48/13.24 mm
Heights | 0.659/0.713/0.659 in
16.73/18.11/16.73 mm
Wall thickness | 0.0508 in
1.290 mm
Web openings | 0/0/0
Governing case | Load Case 2 at global x = 5.5 in
global x = 139.7 mm
Minimum FoS | 1.503
Maximum deflection | 0.16121 in
4.095 mm
File | Link
Package folder | Open package folder
STL | Open STL
Best design JSON | Open JSON
Report | Open report

### 2. Archived Final Baseline

Why second: this is the cleanest archived “final” comparison print. The archived printability note explicitly calls it a defensible final choice.

Property | Value
Design ID | optimization_final
Widths | 0.446/0.350/0.572 in
11.32/8.90/14.54 mm
Heights | 1.051/0.559/0.530 in
26.69/14.21/13.46 mm
Wall thickness | 0.0600 in
1.524 mm
Web openings | 0.621/0.525/0.297
Governing case | Load Case 2 at x = 5.0 in
x = 127.0 mm
Minimum FoS | 1.634
Maximum deflection | 0.12226 in
3.105 mm

File | Link
Package folder | Open package folder
STL | Open STL
Best design JSON | Open JSON
Report | Open report

### 3. Symmetric Near-Target Comparator

Why third: this is the best archived symmetric design that still stays very close to the FoS target. It is useful if you want a specimen that is easy to explain and visually cleaner than the more asymmetric archived runs.

Property | Value
Design ID | optimization_revised_symmetric_light
Widths | 0.535/0.362/0.535 in
13.58/9.21/13.58 mm
Heights | 0.453/0.493/0.453 in
11.50/12.52/11.50 mm
Wall thickness | 0.0600 in
1.524 mm
Web openings | 0.000/0.266/0.000
Governing case | Load Case 2 at x = 5.0 in
x = 127.0 mm
Minimum FoS | 1.515
Maximum deflection | 0.13453 in
3.417 mm
File | Link
Package folder | Open package folder
STL | Open STL
Best design JSON | Open JSON
Report | Open report

### 4. Aggressive Lightweight Benchmark

Why fourth: among the archived Team-6-style designs that still pass cleanly, this is the lightweight aggressive benchmark. It is not the current final answer, but it is still a strong comparison specimen.

Property | Value
Design ID | optimization_v2_Q7777
Widths | 0.823/0.350/0.350 in
20.90/8.89/8.89 mm
Heights | 0.959/0.727/0.606 in
24.37/18.46/15.38 mm
Wall thickness | 0.0600 in
1.524 mm
Web openings | 0.334/0.650/0.276
Governing case | Load Case 2 at x = 5.0 in
x = 127.0 mm
Minimum FoS | 1.522
Maximum deflection | 0.11608 in
2.949 mm
File | Link
Data folder | Open data folder
STL | Open STL
Best design JSON | Open JSON
Report | Open report

### 5. Symmetric Balanced Control (Optional)

Why optional: this is a good control print when you want a smooth, very symmetric geometry with comfortable margin. It is lighter than the other archived candidates listed here, but it is also more conservative than the near-target options because the minimum FoS stays well above 1.5.

Property | Value
Design ID | optimization_revised_symmetric_balanced
Widths | 0.350/0.411/0.350 in
8.89/10.44/8.89 mm
Heights | 0.785/0.777/0.785 in
19.95/19.74/19.95 mm
Wall thickness | 0.0604 in
1.534 mm
Web openings | 0.677/0.631/0.677
Governing case | Load Case 2 at x = 5.0 in
x = 127.0 mm
Minimum FoS | 1.863
Maximum deflection | 0.09424 in
2.394 mm

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

## Notes On Scope

| The corrected design is the one to cite in the final report.
| The archived designs are still worth printing because they cover different geometry strategies:
open-web asymmetric, clean symmetric, and aggressive lightweight variants.

I intentionally did not include archived designs such as optimization_v2_E or optimization_ v2_F in the main print queue because their stored load cases do not match the current Team 6 loading used by the active corrected workflow.

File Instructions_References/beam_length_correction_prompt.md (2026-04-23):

# Beam-Length Correction Prompt

Use the same analysis and design approach as before, but correct the project setup to match the actual instructions.

The beam must be `9 in` total length, not `8 in`.

The two supports are `8 in` apart, so place them at `x = 0.5 in` and `x = 8.5 in` along the full `9 in` beam.

Please account for that corrected support placement in any diagrams, geometry descriptions, and load-location references.

The project instructions say the beam must be `9 in` long and the supports must be `8 in` apart, with each support at least `0.5 in` wide. We previously messed up by treating the beam as if it were only `8 in` long, so update the work to reflect the correct `9 in` overall length.

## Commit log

2026-04-21 Enforce connected beam durability and rerun Team 6 analyses
    [design_study.csv, optimization_connected_2026.obj, optimization_connected_2026.stl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]
2026-04-23 new stuff 04-23
    [continuous_uniform_both_load_cases_9in_corrected.dxf, continuous_uniform_both_load_cases_9in_corrected.obj, continuous_uniform_both_load_cases_9in_corrected.st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]
2026-04-24 Add print-safe ranked beam designs
    [01_overall_rank__print_safe_contiguous_closed_tube_seed2502__eval_1113__w_0.04801__fos_1.591.dxf, 01_overall_rank__print_safe_contiguous_closed_tube_seed2502__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]
2026-04-24 Rank beam designs by weight
    [01_overall_rank__continuous_uniform_both_load_cases_9in_corrected__eval_0219__w_0.03983__fos_1.761.dxf, 01_overall_rank__continuous_uniform_both_load_cases_9in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]
2026-04-24 Record print test slicer settings
2026-04-24 Add print-oriented beam models
    [01_overall_rank__continuous_uniform_both_load_cases_9in_corrected__eval_0219__w_0.03983__fos_1.761.obj, 01_overall_rank__continuous_uniform_both_load_cases_9in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]
2026-04-24 Ultra-light top-20 redesign: 8.88g champion with 3D models
    Rebuilt best-designs-20 with relaxed ranker filters to capture open-web
    ultra-light designs (web opening ratio up to 0.90, wall thickness down
    to 0.040 in). All 20 designs now range 8.88g–9.32g vs previous 18–21g.
    Champion (rank 2): 8.88g, FoS=1.707, standard PLA — symmetric tapered
    tube with mid-span web openings of 68.5%, wall thickness 0.040 in.
    Deliverables:
    - best-designs-20/ranked-designs/ — top 20 with full JSON/CSV/plots
    - best-designs-20/3d-models/ — STL, OBJ, DXF, preview PNG ×20
    - final-champion/ — champion_beam.{stl,obj,dxf,png}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
    [01_overall_rank__continuous_uniform_both_load_cases_9in_corrected__eval_0219__w_0.03983__fos_1.761.dxf, 01_overall_rank__continuous_uniform_both_load_cases_9in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]
2026-04-24 Solid-tube top-20: 12.8g champion, no web holes, updated shortlists
    Reimposed closed-tube constraint (max web opening ratio = 0.000) while
    relaxing wall thickness floor from 0.060 in to 0.040 in. Lightest valid
    solid-wall beam drops from 18.1g to 12.8g. All 20 designs are fully
    contiguous hollow tubes with no side-wall openings.
    Champion (rank 01): 12.77g, FoS=1.642, solid walls, t=0.040 in
    Width 0.602/0.511/0.602 in, Height 0.289/0.496/0.289 in
    - Rebuilt best-designs-20/ranked-designs/ and 3d-models/ (20 solid tubes)
    - Updated final-champion/ with new champion STL/OBJ/DXF/PNG
    - Added print_test_shortlist.md for current set (rank 01 champion)
    - Added print_test_shortlist_prior_set.md: prio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
    [01_overall_rank__continuous_uniform_both_load_cases_9in_corrected__eval_0370__w_0.02815__fos_1.642.dxf, 01_overall_rank__continuous_uniform_both_load_cases_9in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]
2026-04-26 Add ultra-light/pure-weight runs, final gcode, clean up archive
    - 10 new design runs (ultra_light series + pure_weight_tight)
    - Final champion gcode files (43m12s and 53m8s slices)
    - Updated ranked_candidates_after_top20.csv
    - Remove stale archive CSVs and README
    [continuous_uniform_both_load_cases_9in_corrected.csv, design_study.csv, flat_3to7_lc2_ranksearch_symmetric_seed2403.csv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]
2026-04-26 Restore deleted slicer and gcode files
    Restores 3MF slicer files and gcode files that were accidentally removed
    in the ultra-light top-20 redesign commit (42c791b).
    [Completed_Actual_Sliced_Items.3mf, Completed_Pins_Sliced_Items.3mf, Completed_Sliced_Items.3mf]
